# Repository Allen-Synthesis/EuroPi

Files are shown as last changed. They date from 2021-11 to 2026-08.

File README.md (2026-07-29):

  
# EuroPi
The EuroPi is a user reprogrammable [Eurorack](https://en.wikipedia.org/wiki/Eurorack) module developed by [Allen Synthesis](https://allensynthesis.co.uk) that uses the [Raspberry Pi Pico](https://www.raspberrypi.com/products/raspberry-pi-pico/) to process and produce modular level signals based on code written in [MicroPython](https://micropython.org/). The entire project is open-source.

## Documentation
### Hardware
The hardware source files and documentation (including build guides) can be found in the [hardware overview](hardware/README.md), and kits can be bought directly from [Allen Synthesis](https://allensynthesis.square.site/product/europi-panel-pcb/16?cp=true&sa=true&sbp=false&q=false).

### Software
Before using any of the software, follow the [programming_instructions](software/programming_instructions.md) to set up and calibrate your module.
A list of user contributed scripts (along with descriptions for their usage) can be found in [contrib/README.md](software/contrib/README.md).

The EuroPi firmware allows you to interact with the hardware easily using code written in MicroPython. You can read the full list of available functions in the [EuroPi API Documentation](https://allen-synthesis.github.io/EuroPi/), which also includes some examples of some of those functions can be used. Some of the less obvious but potentially useful functions are also explained in more depth in [interesting_things.md](software/interesting_things.md).

If you would like to extend any of the features of the EuroPi software, you can view the [firmware source code](software/firmware/europi.py), and make contributions of your own after reading the [contribution guidelines](contributing.md).

### Issues
If you find any bugs, either in the software, the hardware, or the documentation, please [create a GitHub issue](https://github.com/Allen-Synthesis/EuroPi/issues/new/choose) so it can be fixed by one of the maintainers. There are issue templates available, so please choose whichever is most relevant.

### AI Policy 
This is a project that is both explicitly aware of, and reliant on, its social context; the module's licenses are deliberately 'free' and open-source, and that fact is what has allowed its community to develop itself, and consequently develop the EuroPi module.
To paraphrase [Dan McQuillan](https://www.youtube.com/watch?v=mh0U2o5Ysms), "AI removes the cultural context that underpins our social relations" - A tool which produces an output without regard for social context cannot be used to meaningfully contribute to any project that specifically aims to analyse and engage with that context.

We are not able to know with certainty that any contribution is AI-free, however any pull requests which have clearly relied on it will be rejected. For the reasons described above we hope that you will choose to develop without it, not just to ensure a quick merge, but for the benefit of the open-source community and society as a whole.
All of the core components of the EuroPi (the firmware and hardware) are entirely AI-free.

## Specification
* 6 0-10V Control Voltage outputs, each with indicator LED
* 2 Knobs with 12 bit resolution
* 2 Push Buttons
* 1 0-12V Control Voltage input with 12 bit resolution
* 1 Digital input for external clocking or gate sources
* 128x32 OLED Display
* I²C expansion header on the rear for extra sensors or outputs

github banner

## License
This module, and any documentation included in this repository, is entirely "free" software and hardware. The hardware is [certified by the Open Source Hardware Association](https://certification.oshwa.org/uk000048.html)

* Software: [Apache 2.0](software/LICENSE)
* Hardware: [CERN OHL-S v2](hardware/LICENSE)
* Documentation: [CC0 1.0](LICENSE)

Anyone is welcome to design their own versions of the idea, or modify my designs.
The only thing I would ask is that you refrain from using the brand name 'Allen Synthesis' on your DIY builds if they have modified my files in any way, just to prevent any confusion if they end up being re-sold or distributed. This is in line with section 8.2 of the CERN license. You may use the brand name if you have simply copied the files from this repository to replicate without modification.

If you have a bug fix or improvement that you think is worth sharing, then feel free to send over any pictures or documentation and it can be merged with the main project!

## Disclaimer
Recreate any of the files found in this repository at your own risk; I will attempt to solve any issues that you might have with my designs, but I can't guarantee that there are not minor bugs in any of the documents, both hardware and software. If you want a module or kit that you know will work and will have customer support, you can order one directly from [Allen Synthesis](https://allensynthesis.co.uk/).

**NOTE:** This repository relates to the EuroPi module, however some users may be expecting to see what is now referred to as the 'EuroPi Prototype'. The repository for this (now deprecated) module [can be found here](https://github.com/roryjamesallen/EuroPi-Prototype)

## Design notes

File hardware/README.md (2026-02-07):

# Hardware Overview
There are multiple versions of the hardware documented in this directory, the original EuroPi (through-hole), the new EuroPi-SMD (surface-mount), and a stripboard version (stripboard). Each has a different build guide and bill of materials, so make sure you follow the one you want to build.

**[surface-mount](surface-mount/)**: The simplest to DIY as you only need to solder on the components which stick through the panel, i.e. the jacks, knobs etc. All of the other circuitry is soldered onto the PCB already.

**[through-hole](through-hole/)**: A slightly more in depth build as you need to solder on every component, however only through-hole components are used, so this isn't as hard as it sounds. This is the build most people have made and was previously the only publicly available build at all.

**[stripboard](stripboard/)**: A much rougher layout and does not use a PCB at all, but instead uses 'stripboard'. This hasn't been tested nearly as much as the other two, but people have successfully built it and shared their version on Discord. Not developed or maintained by Allen Synthesis.

# Hardware Specifications
All hardware variants share the same specifications as the components and schematics are the same.

## Outputs
- 1k Output Impedance
- RC filter smoothed PWM
- ~1.5kHz Maximum usable frequency (without changing RC values)
- 0-10V

## Analogue Input
- 100k Input Impedance
- 0-12V Readable Range
- Protected for ±12V (TL074 limits, MCP6002 will always clip to ±3.3V)

## Digital Input
- 100k Input Impedance
- 0.8V threshold to read as high

## OLED
- SSD1306 0.91"
- 128 x 32 pixels
- I2C Protocol

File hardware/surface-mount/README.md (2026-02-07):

# EuroPi (surface-mount)

This is a version of the EuroPi that has all of the components other than the Pico, power header, and panel components pre-soldered using SMD packages. This makes for a much simpler DIY build, as well as a thinner end result. It has identical technical specifications to the through-hole version and adds the hardware required for input detection.

The board files for this version are designed in [KiCad](https://www.kicad.org/) so are a more friendly starting point for third-party development or modification.

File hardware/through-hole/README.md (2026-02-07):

# EuroPi (through-hole)
This directory contains the build instructions and production files for the 'original' EuroPi, which is the entirely through-hole build. This is the build the majority of users have.

# PCB Files

The PCB files are in two file types:
- .pcb files, which can be opened in [DesignSpark](https://www.rs-online.com/designspark/pcb-software) free PCB software
- .rar files, which are zipped folders containing the Gerber format PCBs. Each entire .rar folder can be dragged and dropped to a PCB manufacturer such as [JLC PCB](https://jlcpcb.com/) (my personal choice)

There are two different options for the panel PCB:
- Panel, which is made for JLC aluminium production
- Black Panel, which is made for FR4 production by any manufacturer
The subtleties of these files are minor, but JLC will only produce the aluminium boards correctly if the layers are in the order that they are in these files, which is silkscreen on the bottom layer and copper on the top.

In line with the license used for the PCBs, if you modify these files before production (rather than just dragging and dropping the gerber files), please contact me if you would like to keep the 'Allen Synthesis' name on it! This is not based in any mistrust of your modifications, but in the risk that someone else might then get hold of these boards or files, turn to me for support, and be disappointed.

If you would rather save yourself the effort of ordering boards (and potentially paying import charges), you can also order Panel + PCB kits directly from me, which will ship with a lower lead time than a PCB manufacturer too!
https://allensynthesis.square.site/

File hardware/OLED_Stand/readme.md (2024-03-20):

# 3D printed OLED stands

A simple small stand for your OLED display. This helps hold it in place while soldering and keeps it snug against the face of the module.

> There are two versions of the stand, one for the CPC style OLED and one for the TPH (the Pi Hut) style OLED.

## CPC style OLED

3D print the file [OLED_Stand.stl](OLED_Stand.stl).

Put the stand on something about 5-10mm tall, then solder some component cutoff wire to your OLED so that they fall below the bottom of the stand. Place on your interface board, solder pins to board. Pins may need to be bent slightly for the model of OLED that you're using. Just align the stand and the display and you should be right in the middle of the cutout.

Print upside down for best results/least amount of supports. Should print very quickly on most printers. It takes 30 minutes on an Ender3 Pro.

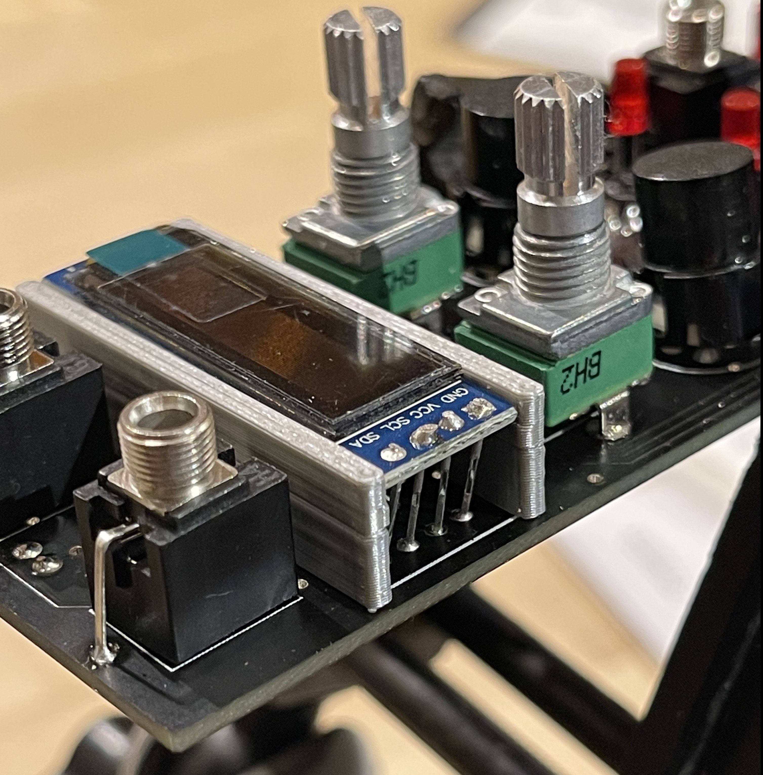
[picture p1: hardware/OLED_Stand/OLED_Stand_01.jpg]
OLED Stand
 

## TPH (the Pi Hut) style OLED

3D print the file [OLED_Stand_Pi_Hut.stl](OLED_Stand_Pi_Hut.stl).

The TPH (the Pi Hut) OLED needs a different stand because it has a chunky connector on the side (unused by the EuroPi).

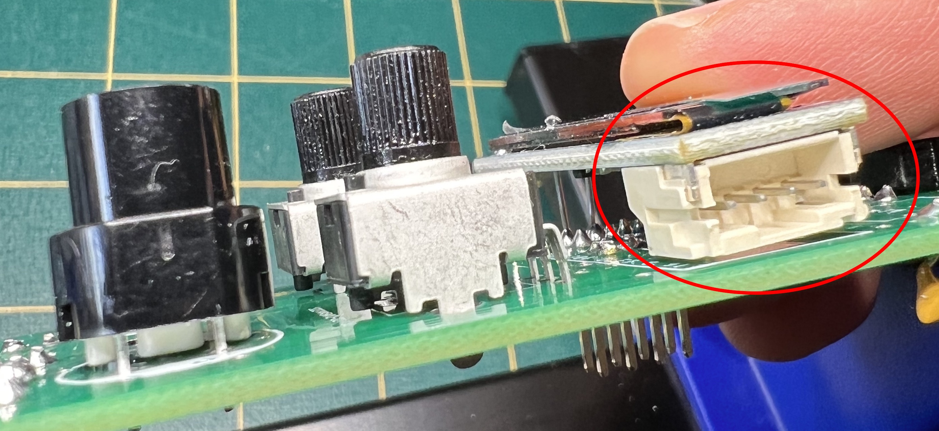
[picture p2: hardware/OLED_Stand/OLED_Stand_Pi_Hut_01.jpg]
OLED Pi Hut style
 

- Slide your OLED into the groove.
- Place the stand with OLED into position on the PCB (hold in place using bluetack).
- Solder the four vertical wires.

The stand has a notch to avoid certain soldering points. You should keep the stand permanently in your EuroPi for added stability of the screen.

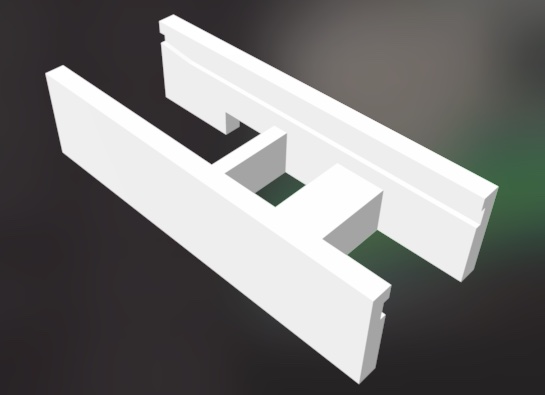
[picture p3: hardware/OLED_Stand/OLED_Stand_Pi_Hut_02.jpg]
OLED Stand for Pi Hut style


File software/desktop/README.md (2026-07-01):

# Desktop and Mobile Software

This directory contains programs and configuration files intended to run on your desktop/laptop
computer or mobile device, not on EuroPi itself.

Please refer to the README.md file in each sub-directory for details on how to set up and use
each piece of software.

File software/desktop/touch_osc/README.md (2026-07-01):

# Sample TouchOSC Configuration

This directory contains a sample TouchOSC configuration file designed to work with
[`osc_control`](/software/contrib/osc_control.md).

To use this layout, copy `europi.tosc` onto your device and open TouchOSC. Import
`europi.tosc` into TouchOSC. This will add the following controls:

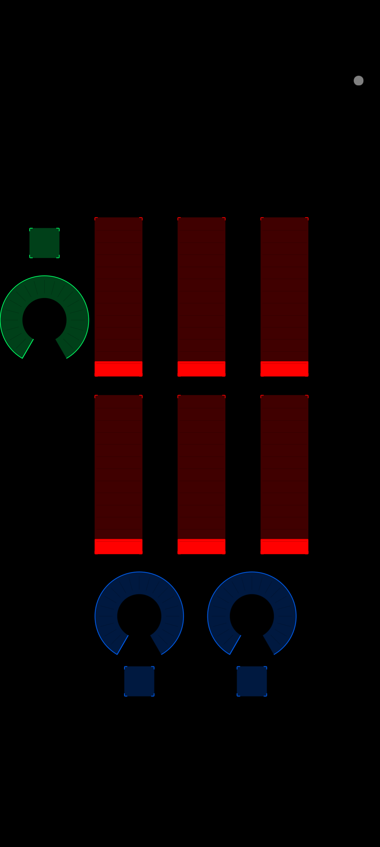
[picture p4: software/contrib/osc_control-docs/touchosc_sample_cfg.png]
OSC Layout


- 6 red sliders to control EuroPi's outputs
- green indicators for the values of `din` and `ain`
- blue indicators for the values of `k1`, `k2`, `b1`, and `b2`

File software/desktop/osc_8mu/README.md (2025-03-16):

# OSC 8mu Interface

This program is intended to be run on a laptop or desktop with a
[Music Thing Modular 8mu](https://www.musicthing.co.uk/8mu_page/)
connected to it.  It converts the MIDI outputs from 8mu into OSC
messages that can be consumed by EuroPi when properly set up.

## Requirements

### EuroPi

Your EuroPi module must be equipped with a Pico W or Pico 2 W instead
of the standard Pico.

EuroPi's WiFi [must be configured](/software/CONFIGURATION.md#wifi-connection)
with either
1. your computer connected directly to EuroPi's access point, or
2. both your computer and EuroPi connected to the same external network.

Power on EuroPi and run the [`OSC Interface`](/software/contrib/osc_control.md)
program, making note of EuroPi's IP address displayed on the OLED.

### Laptop/Desktop

You must have Python3 installed on your computer, with the following
modules:
- `mido`
- `rtmidi` (via the `python-rtmidi` PyPI package)

To install these, use `pip3` (or `pip`):
```bash
pip3 install mido
pip3 install python-rtmidi
```

Finally, you must own a Music Thing Modular 8mu and have it connected to
your computer using a USB-C cable.

## Running the program

Once EuroPi is running the `OSC Interface` program, start `osc_8mu`
on your desktop by running
```bash
cd /path/to/EuroPi/software/desktop
python3 osc_8mu.py --ip <EuroPi's IP address>
```

Depending on the configuration of 8mu you may need to specify what MIDI
controls will control each output of EuroPi.  For example, if you have
configured 8mu to use controls 20-28 for the sliders, you will need
to run `osc_8mu` with the following command:
```bash
python3 osc_8mu.py --ip 192.168.4.1 --cv1 20 --cv2 21 --cv3 22 --cv4 23 --cv5 24 --cv6 24
```

To override the UDP port, use the `-p|--port` argument. By default `osc_8mu` will use
port 9000 to send UDP packets to EuroPi.

For more information about the available parameters, run
```bash
python3 osc_8mu.py --help
```

## MIDI to OSC to EuroPi conversion

The 8mu slider position is reported as a MIDI value from `0` to `127`. This is converted
to a `0.0` to `1.0` value for OSC, which is then multiplied by `MAX_OUTPUT_VOLTAGE` on
EuroPi to set the value of the output channel. Obviously 128 positions in the MIDI source
doesn't provide super-fine resolution on EuroPi's voltage.

To work around this the `-s|--scale` parameter can be set to provide an additional
scale factor during the MIDI to OSC conversion:

```
X_midi <- Read from 8mu: 0-127

X_osc = X_midi / 127.0 * scale
V_out = X_osc * MAX_OUTPUT_VOLTAGE
```

For example, setting `scale` to 0.1 will reduce EuroPi's output range from 0-10V
to 0-1V, but will compress all 128 steps within the 1V range, allowing finer control
over a smaller voltage range.

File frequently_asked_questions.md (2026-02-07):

# FAQ

### Frequently asked questions about the EuroPi project. If you can't find the answer to your question here, head over to [The Discord](https://discord.gg/JaQwtCnBV5) and ask it in the support channel!

#

### Topics:

### [General Questions](#general-questions)
### [Hardware Decisions](#hardware-decisions)
### [Bill of Materials (BOM)](#bill-of-materials)
### [Git](#git)
### [Programming](#programming-1)
### [Calibration](#calibration-1)

#

## General Questions

| Can the EuroPi process audio? | Some audio has been achieved on the EuroPi, such as t-schreibs' [Poly Square](software/contrib/poly_square.md) script, however full audio processing would likely require extra hardware to be accurate |
|--|--|

## Hardware Decisions

| Why did you use potentiometers and not encoders? | This module is designed to be a platform with which you can design fully functioning modules of your own, rather than a deep menu based system, and I feel that using encoders would encourage user interfaces that stray into the unusable. Users can always add encoders using i²c if they're determined! |
|--|--|

## Bill of Materials

| Do any of the capacitors need to be polarised? | No, non-polarised will work fine |
|--|--|

## Git/GitHub

| What is a 'Pull Request'? | This is a request made by a user to the main repository to 'pull' the extra data, either changes, new files, or deletions, from their fork into the main one. Essentially it is the way that users contribute to the main repository. The guidelines for creating a PR, and more explanation of what one is, can be found in the [contributing guidelines](contributing.md) |
|--|--|

## Programming

| Do I need to learn programming to use this module? | Nope! The menu system can be used with absolutely no programming knowledge at all, but once installed you are always free to write your own scripts if you feel like it |
|--|--|

## Calibration

| When in the second stage of calibration, my module never reaches 10V, what do I do? | Refer to the [troubleshooting guide](troubleshooting.md) |
|--|--|

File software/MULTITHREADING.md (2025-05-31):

# Multi-Threading

The Raspberry Pi Pico used in EuroPi has 2 CPU cores.  By default only one core is used.  Micropython contains a
module called `_thread` that can be used to run code on both cores.  This can be helpful if, for example, your program
features a lot of mathematical calculations (e.g. floating point operations, trigonometry (e.g. `sin` or `cos`)) that
must be run quickly, but also features a complex GUI to render to the OLED.

## WARNING

Multi-threading is considered an experimental feature, and is intended for advanced programmers only. Adding threads to
your program can introduce many hard-to-debug errors and requires some understanding of some advanced topics not
covered here, including:
- thread safety
- concurrency
- semaphores & mutexes

Unless you're certain you need the additional processing power offered by the EuroPi CPU's second core, it is
_strongly_ recommended that you write your program using a single thread.

## Using `_thread`

To use the `_thread` library you must first import it into your program:
```python
import _thread
```

Your program will always contain at least one thread, referred to as the "main thread."  To start a second thread
you must define a function to execute and start it with `_thread.start_new_thread`.

### Example 1: Basic thread execution

This example shows the absolute minimum needed to run two threads:

```python
from europi import *
import time
import _thread

def my_second_thread():
    """The secondary thread; toggles CV2 on and off at 0.5Hz"""
    while True:
        cv2.on()
        time.sleep(1)
        cv2.off()
        time.sleep(1)

def main():
    """The main thread; creates the secondary thread and then toggles CV1 at 1Hz"""
    # Start the second thread
    second_thread = _thread.start_new_thread(my_second_thread, ())

    while True:
        cv1.on()
        time.sleep(0.5)
        cv1.off()
        time.sleep(0.5)
```

This example has a few limitations that we'll address below:
1. It's not a `EuroPiScript`, so it can't be included in the main menu
2. The secondary thread can keep running after we cancel execution, which can result in problems
   using the Python terminal in Thonny for debugging.

### Example 2: Basic `EuroPiScript` implementation

This is a more complex example that implements the same logic as above, but wrapped in a `EuroPiScript`.
Note that we add a second condition to the `while` loops; the `self.is_running` flag will allow the
background thread to exit cleanly when debugging in Thonny.
```python
from europi import *
from europi_script import EuroPiScript
import time
import _thread

class BasicThreadingDemo1(EuroPiScript):
    def __init__(self):
        super().__init__()

        # is main() running?
        # this is used to make sure the threads exit when we cancel
        # the program
        self.is_running = False

    def main_thread(self):
        """The main thread; toggles CV1 on and off at 1Hz"""
        while self.is_running:
            cv1.on()
            time.sleep(0.5)
            cv1.off()
            time.sleep(0.5)

    def secondary_thread(self):
        """The secondary thread; toggles CV2 on and off at 0.5Hz
        """
        while self.is_running:
            cv2.on()
            time.sleep(1)
            cv2.off()
            time.sleep(1)

    def main(self):
        # Clear the display
        oled.fill(0)
        oled.show()

        # set is_running to True BEFORE we start the threads!
        # otherwise they'll exit right away
        self.is_running = True
        try:
            second_thread = _thread.start_new_thread(self.secondary_thread, ())
            self.main_thread()
        except KeyboardInterrupt:
            # When Thonny's terminal connects, or when we press ctrl+C we'll
            # catch a KeyboardInterrupt exception, which we can use to stop
            # both threads.
            self.is_running = False
        finally:
            print("User aborted. Exiting.")

if __name__ == "__main__":
    BasicThreadingDemo1().main()
```

### Example 3: Handling digital inputs

Interrupt Service Routines (ISRs), implemented as `handler` functions for button presses and `din` rising/falling edges
have been known to cause threaded programs to hang.  It is therefore recommended to _avoid_ using `handler` functions
in your program:
```python
# To NOT do this:
@b1.handler
def on_b1_rising():
    self.do_stuff()
```

Instead, [`experimental.thread`](/software/firmware/experimental/thread.py) provides a `DigitalInputHelper` class
that can be used inside your main thread to check the state of the buttons & `din` and invoke callback functions
when a rising or falling edge is detected.

For example:
```python
from europi import *
from europi_script import EuroPiScript

import time
import _thread

from experimental.thread import DigitalInputHelper

class BasicThreadingDemo2(EuroPiScript):
    def __init__(self):
        super().__init__()
        self.is_running = False

        self.digital_input_helper = DigitalInputHelper(
            on_b1_rising = self.on_b1_press,
            on_b1_falling = self.on_b1_release,
            on_b2_rising = self.on_b2_press,
            on_b2_falling = self.on_b2_release,
            on_din_rising = self.on_din_high,
            on_din_falling = self.on_din_low
        )

    def on_b1_press(self):
        """Turn on CV4 when the button is held
        """
        cv4.on()

    def on_b1_release(self):
        """Turn off CV4 when the button is released
        """
        cv4.off()

    def on_b2_press(self):
        """Turn on CV5 when the button is held
        """
        cv5.on()

    def on_b2_release(self):
        """Turn off CV5 when the button is released
        """
        cv5.off()

    def on_din_high(self):
        """Turn on CV6 when the signal goes high
        """
        cv6.on()

    def on_din_low(self):
        """Turn off CV6 when the signal drops low
        """
        cv6.off()

    def main_thread(self):
        """The main thread; toggles CV1 on and off at 1Hz and handles the buttons + DIN
        """
        # calling time.sleep will block the input handling, so we need to check the clock instead
        last_state_change_time = time.ticks_ms()
        cv1_on = True
        cv1.on()

        while self.is_running:
            # Check the inputs
            self.digital_input_helper.update()

            now = time.ticks_ms()
            if time.ticks_diff(now, last_state_change_time) >= 500:
                last_state_change_time = now
                cv1_on = not cv1_on
                if cv1_on:
                    cv1.on()
                else:
                    cv1.off()

    def secondary_thread(self):
        """The secondary thread; toggles CV2 on and off at 0.5Hz
        """
        while self.is_running:
            cv2.on()
            time.sleep(1)
            cv2.off()
            time.sleep(1)

    def main(self):
        # Clear the display
        oled.fill(0)
        oled.show()

        self.is_running = True
        try:
            second_thread = _thread.start_new_thread(self.secondary_thread, ())
            self.main_thread()
        except KeyboardInterrupt:
            self.is_running = False
        finally:
            print("User aborted. Exiting.")

if __name__ == "__main__":
    BasicThreadingDemo2().main()
```

### Example 4: OLED rendering on the second core

One of the slowest operations in the EuroPi firmware is updated the OLED. If possible moving any GUI rendering into
a secondary thread is a good idea to optimize your program.  Note that you will likely need to use `Lock` objects
to prevent threads from trying to read/write data at the same time.

```python
from europi import *
from europi_script import EuroPiScript

import math
import _thread

class BasicThreadingDemo3(EuroPiScript):
    def __init__(self):
        super().__init__()

        # Create a lock object to prevent multiple threads from accessing our pixel array
        self.pixel_lock = _thread.allocate_lock()

        # Create an array that we'll store vertical pixel positions in to draw on screen
        self.pixel_heights = []

    def cv_thread(self):
        """The main thread; generates a sine wave on CV1
        """
        CYCLE_TICKS = 10000  # one complete sine wave every N times through the loop

        ticks = 0
        cv1_volts = 0
        while True:
            # convert the tick counter to radians for use with sin/cos
            theta = ticks / CYCLE_TICKS * (2*math.pi)

            # sin gives us [-1, 1], but we need to shift it to [0, MAX_OUTPUT_VOLTAGE]
            cv1_volts = (math.sin(theta) + 1) / 2 * MAX_OUTPUT_VOLTAGE

            # convert the voltage to an integer from 0 to OLED_HEIGHT
            # note that row 0 is the top, so we'll draw a line that goes down as the voltage goes up
            # since this is just an example, that's fine; the math to flip the visualization is left as
            # an exercise for the reader
            with self.pixel_lock:
                self.pixel_heights.append(int(cv1_volts * OLED_HEIGHT / MAX_OUTPUT_VOLTAGE))

                # Restrict the number of pixel heights to match the width of the screen
                if len(self.pixel_heights) >= OLED_WIDTH:
                    self.pixel_heights.pop(0)

            ticks = ticks + 1
            if ticks >= CYCLE_TICKS:
                ticks = 0

            cv1.voltage(cv1_volts)

    def gui_thread(self):
        """Draw the wave shapes to the screen
        """
        usb_connected_at_start = europi.usb_connected.value()
        while eurpi.usb_connected.value() == usb_connected_at_start and self.is_running:
            # clear the screen
            oled.fill(0)

            # Draw the pixels representing our waves
            # Make sure to grab the lock so the arrays aren't modified while we're reading them!
            with self.pixel_lock:
                for i in range(len(self.pixel_heights)):
                    oled.pixel(i, self.pixel_heights[i], 0xff)  # draw a white pixel

            # Show the updated display
            oled.show()

    def main(self):
        self.is_running = True
        try:
            second_thread = _thread.start_new_thread(self.gui_thread, ())
            self.cv_thread()
        except KeyboardInterrupt:
            self.is_running = False
        finally:
            print("User aborted. Exiting.")

if __name__ == "__main__":
    BasicThreadingDemo3().main()
```

## How many threads can I use?

Because each thread runs on a different core, and the EuroPi's processor only has 2 cores, it is recommended to limit
your program to 2 thread: the main thread, and a single additional thread started with `_thread.start_new_thread`.

## Cancelling Execution and the Second Core

Typically if you catch `KeyboardInterrupt` exceptions as described in the examples above you should
be able to prevent the second core from becomming locked, but if your program has other errors that
are not handled it's possible that the main thread will exit while the second thread keeps running.

If this occurs, the easiest way to reset the secondary core is to simply power-cycle your module.

## References

- [Official Python `_thread` docs](https://docs.python.org/3/library/_thread.html)

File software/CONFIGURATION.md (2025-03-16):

# Configuration Customization

Certain properties of the module, such as screen rotation, CPU clock speed, and Raspberry Pi Pico model, can be
set using a static configuration file.  This file is located at `/config/EuroPiConfig.json` on the
Raspberry Pi Pico. If this file does not exist, default settings will be loaded.  The following shows the
default configuration:
```json
{
    "EUROPI_MODEL": "europi",
    "PICO_MODEL": "pico",
    "CPU_FREQ": "overclocked",
    "ROTATE_DISPLAY": false,
    "DISPLAY_WIDTH": 128,
    "DISPLAY_HEIGHT": 32,
    "DISPLAY_SDA": 0,
    "DISPLAY_SCL": 1,
    "DISPLAY_CHANNEL": 0,
    "EXTERNAL_I2C_SDA": 2,
    "EXTERNAL_I2C_SCL": 3,
    "EXTERNAL_I2C_CHANNEL": 1,
    "EXTERNAL_I2C_FREQUENCY": 100000,
    "EXTERNAL_I2C_TIMEOUT": 1000,
    "MAX_OUTPUT_VOLTAGE": 10.0,
    "MAX_INPUT_VOLTAGE": 10.0,
    "GATE_VOLTAGE": 5.0,
    "MENU_AFTER_POWER_ON": false
}
```

## System

Options:
- `EUROPI_MODEL` specifies the type of EuroPi module. Currently only `"europi"` is supported. Default: `"europi"`
- `PICO_MODEL` must be one of
  - `"pico"`,
  - `"pico h"`,
  - `"pico w"`,
  - `"pico 2"`, or
  - `"pico 2w"`.
  Default: `"pico"`.
- `CPU_FREQ` specifies whether or not the CPU should be overclocked. Must be one of `"overclocked"` or `"normal"`.
  Default: `"overclocked"`
- `MENU_AFTER_POWER_ON` is a boolean indicating whether or not the module should always return to the main menu when
  it powers on.  By default the EuroPi will re-launch the last-used program instead of returning to the main menu. Default: `false`

## Display

Options:
- `ROTATE_DISPLAY` must be one of `false` or `true`. Default: `false`
- `DISPLAY_WIDTH` is the width of the screen in pixels. The standard EuroPi screen is 128 pixels wide. Default: `128`
- `DISPLAY_HEIGHT` is the height of the screen in pixels. The standard EuroPi screen is 32 pixels tall. Default: `32`
- `DISPLAY_SDA` is the I²C SDA pin used for the display. Only SDA capable pins can be selected. Default: `0`
- `DISPLAY_SCL` is the I²C SCL pin used for the display. Only SCL capable pins can be selected. Default: `1`
- `DISPLAY_CHANNEL` is the I²C channel used for the display, either 0 or 1. Default: `0`
- `DISPLAY_CONTRAST` is a value indicating the display contrast. Higher numbers give higher contrast. `0` to `255`. Default: `255`

## External I²C

Options:
- `EXTERNAL_I2C_SDA` is the I²C SDA pin used for the external I²C interface. Only SDA capable pis can be selected. Default: `2`
- `EXTERNAL_I2C_SCL` is the I²C SCL pin used for the external I²C interface. Only SCL capable pins can be selected. Default: `3`
- `EXTERNAL_I2C_CHANNEL` is the I²C channel used for the external I²C interface, either 0 or 1. Default: `1`
- `EXTERNAL_I2C_FREQUENCY` is the I²C frequency used for the external I²C interface. Default: `100000`
- `EXTERNAL_I2C_TIMEOUT` is the I²C timeout in milliseconds for the external I²C interface. Default: `1000`

## I/O voltage

Options:
- `MAX_OUTPUT_VOLTAGE` is a float in the range `[0.0, 10.0]` indicating the maximum voltage CV output can generate. Default: `10.0`
  The hardware is capable of 10V maximum
- `MAX_INPUT_VOLTAGE` is a float in the range `[0.0, 12.0]` indicating the maximum allowed voltage into the `ain` jack.
  The hardware is capable of 12V maximum. Default: `10.0`
- `GATE_VOLTAGE` is a float in the range `[0.0, 10.0]` indicating the voltage that an output will produce when `cvx.on()`
  is called. This value must not be higher than `MAX_OUTPUT_VOLTAGE`. Default: `5.0`

I/O voltage options should specify no more than 1 decimal point. i.e. `2.5` is acceptable, but `1.234` is not.  These
limits are intended for broad compatibility configuration, not for precise tuning.

If you assembled your module with the Raspberry Pi Pico 2 (or a clone featuring the RP2350 microcontroller) make sure to
set the `PICO_MODEL` setting to `"pico2"`.

# Experimental configuration

Other configuration properties are used by [experimental features](/software/firmware/experimental/__init__.py)
and can be set using a similar static configuration file. This file is located at `/config/ExperimentalConfig.json`
on the Raspberry Pi Pico. If this file does not exist, default settings will be loaded.

## Quantization

Options:
- `VOLTS_PER_OCTAVE` must be one of `1.0` (Eurorack standard) or `1.2` (Buchla standard). Default: `1.0`

## Realtime Clock (RTC)

Options:
- `RTC_IMPLEMENTATION` is one of the following, representing the realtime clock enabled on your module:
  - `""`: there is no RTC present. (default)
  - `"ds3231"`: use a DS3231 module connected to the external I2C interface
  - `"ds1307"`: use a DS1307 module connected to the external I2C interface (THIS IS UNTESTED! USE AT YOUR OWN RISK)
  - `"ntp"`: use an NTP source as the external clock. Requires wifi-supported Pico (e.g. Rasperry Pi Pico W or Pico 2 W)
    and valid network configuration (see [WiFi connection](#wifi-connection), below)

## Timezone

Options:
- `UTC_OFFSET_HOURS`: The number of hours ahead/behind UTC the local timezone is (-24 to +24)
- `UTC_OFFSET_MINUTES`: The number of minutes ahead/behind UTC the local timezone is (-59 to +59)

## WiFi Connection

Options:
- `WIFI_MODE`: the wireless operation mode, one of:
  - `"access_point"` (default): EuroPi acts as a wireless access point for other devices to connect to
  -`"client"`: connect EuroPi to an external wireless router or accesspoint (DHCP required)
- `WIFI_SSID`: the SSID of the wireless network to connect to (in `client` mode) or to broadcast
  (in `access_point` mode). Default: `"EuroPi"`
- `WIFI_BSSID`: the optional BSSID of the network to connect to (e.g. access point MAC address). Default: `""`
- `WIFI_PASSWORD`: the password of the wireless network. Default: `"europi"`
- `WIFI_CHANNEL`: the WiFi channel 1-13 to use in `access_point` mode; ignored in `client` mode. Default: `10`
- `WIFI_DHCP`: ignored if `WIFI_MODE` is `access_point`. Otherwise this controls whether or not
  EuroPi requests a DHCP lease from the external access point. Default: `true`.
- `WIFI_IP`: a static IP address to use in `client` mode if DHCP is disabled. Default: `192.168.4.1`
- `WIFI_GATEWAY`: the static gateway in `client` mode when DHCP is disabled. Default: `0.0.0.0`
- `WIFI_NETMASK`: the netmask to use in `client` mode, if DHCP is disabled. Default: `255.255.255.0`
- `WIFI_DNS`: the IP address of the DNS server to use when DHCP is disabled. Default: `8.8.8.8`

WiFi options are only applicable if EuroPi has the Raspberry Pi Pico W or Raspberry Pi Pico 2 W board;
other Pico models do not contain wireless support.

**NOTE**: At the time of writing, the latest Micropython firmware for the Raspberry Pi Pico 2 W has a bug in
which the wireless card will not reliably work if the CPU is overclocked. If you have problems using wifi please
try changing `CPU_FREQ` to `normal` in `EuroPiConfig.json`.

### WiFi Security

If `WIFI_PASSWORD` is empty EuroPi will assume the network is _unencrypted_. This applies to both `client` and
`access_point` modes. If `WIFI_PASSWORD` contains any text, WPA/WPA2 will be used (WPA2 is preferred, but
in `client` mode WPA will be used if the router requires it).

Other wireless authentication models, including the use of cerfificates, VPN connections, etc... are not supported
at this time on the Raspberry Pi Pico (2) W.

## WebREPL Configuration

`WebREPL` allows accessing the Python shell over WiFi, as well as enabling sending/receiving files wirelessly.
This can be useful if you lack a USB cable long enought to reach from your computer to your EuroPi.

Enabling `WebREPL` requires a Raspberry Pi Pico W or Pico 2 W, as well as a valid wifi configuration (see above).

When enabled, `WebREPL` will use the password `EuroPi` by default. To change this password you will need to modify
`/webrepl_cfg.py` to enter your new password.

To access `WebREPL`, direct your computer's browser to `http://<EuroPi's IP address>:8622`, e.g.
`http://192.168.4.1:8622`. Alternatively you can configure Thonny's terminal to connect via `WebREPL`
by selecting Run > Configure Interpreter, selecting `WebREPL` from the drop-down, and entering
EuroPi's IP address and port 8622.

Options:
- `ENABLE_WEBREPL`: enable or disable `WebREPL`. Default: `false`

### `WebREPL` Security

Enabling `WebREPL` can be a security risk: it potentially allows anyone to access the Python interpreter of
your EuroPi, giving them complete access to run code, modify files, etc.... If you choose to enable `WebREPL`
it is highly recommended that you choose a strong password and that you make sure your wifi connection is
using WPA2 (see [WiFi Security](#wifi-security), above).

# Accessing config members in Python code

The firmware converts the JSON file into a `ConfigSettings` object, where the JSON keys are converted
to Python attributes.  The JSON object's keys must follow these rules, otherwise a `ValueError` will be raised:

1. The string may not be empty
1. The string may only contain letters, numbers, and the underscore (`_`) character
1. The string may not begin with a number
1. The string should be in `ALL_CAPS`

The JSON key is converted into a Python attribute of the configuration object. For example, this JSON file
```json
{
  "CLOCK_MULTIPLIER": 4,
  "HARD_SYNC": true,
  "WAVE_SHAPE": "sine"
}
```
would produce a Python object with these attributes:
```python
>>> dir(config_object)
[
  '__class__',
  '__init__',
  '__module__',
  '__qualname__',
  '__dict__',
  'to_attr_name',
  'CLOCK_MULTIPLIER',
  'HARD_SYNC',
  'WAVE_SHAPE'
]

>>> config_object.CLOCK_MULTIPLIER
4

>>> config_object.HARD_SYNC
True

>>> config_object.WAVE_SHAPE
'sine'
```

`europi.py` contains objects called `europi_config` and `experimental_config` which implement the core & experimental
customizations described in the sections above.

When you import `europi` into your project you can access the `europi_config` object like this:
```python
from europi import *

# A voltage range we can select from in a user menu
VOLTAGE_RANGE = range(0, europi_config.MAX_OUTPUT_VOLTAGE)
```

Alternatively, you can access it using the fully qualified namespace:
```python
import europi

# A voltage range we can select from in a user menu
VOLTAGE_RANGE = range(0, europi.europi_config.MAX_OUTPUT_VOLTAGE)
```

# Note on Booleans

Python uses `True` and `False` to represent boolean values (starting with upper-case letters), but JSON uses `true` and
`false` (starting with lower-case letters).

This is an unavoidable inconsistency between the configuration file and the Python source code. When modifying the JSON
file to modify your configuration, make sure to use correct JSON boolean names, not Python names.

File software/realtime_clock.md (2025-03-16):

# Realtime Clock

EuroPi does not natively include a realtime clock. An external clock module can be
installed and configured to provide time and date information to EuroPi's programs.

## What is a realtime clock?

A realtime clock is a clock with a battery that will continue to track the time
even when your synthesizer is powered-off. This allows EuroPi to know what the
current date and time are, even if the module has been turned off for some time.

Without a realtime clock, the only way to get the time is by using Micropython's
`time.ticks_ms()` or `time.ticks_us()` functions; these return the ticks (in
milliseconds or microseconds) since the module was powered-on, but won't accurately
represent the real-world time and date.

## What clock should I buy?

There are many I2C compatible realtime clock modules available. EuroPi has been
tested with the DS3231, though the similar DS1307 may also work.

These modules can be bought online from a variety of sources, for example:
- https://www.amazon.ca/dp/B09S8VF9GL
- https://shop.kincony.com/products/ds3231-rtc-module
- https://www.mouser.ca/ProductDetail/Analog-Devices-Maxim-Integrated/DS3231MPMB1
- https://www.aliexpress.com/item/1005001875764383.html

## How do I connect the clock?

The realtime clock should be connected to EuroPi's I2C header pins, located on the
rear of the module, between the Raspberry Pi Pico and the power header.



_EuroPi's I2C header (circled)_

Depending on the size and depth of your synthesizer's case there are a few ways you
can mount the clock. For deep cases, the easiest solution is to simply use a standoff
to connect the clock to the Raspberry Pi Pico:

 

_The DS3231 RTC mounted to the Raspberry Pi Pico using a standoff_

For shallower cases, you can attach header pins and jumper wires to a pice of perfboard
or plastic, and mount the clock vertically.

 

_A vertical mount made from a piece of perboard, 2 female headers, and some wire_

Other mounting solutions are also possible, for example attaching the clock behind a
blank panel or using double-sided foam tape to attach it directly to the inside of your
case. As long as the clock is securely fastened so it won't move around, insulated from
any accidental contact with conductive surfaces inside the case, and properly
connected to the I2C header pins it should be fine.

## How do I configure the clock?

The default external I2C settings from `europi_config` should be used, unless you have
a specific need to change them in `config/EuroPiConfig.json` (for example, your RTC module
needs a specific I2C frequency):
```json
{
    "EXTERNAL_I2C_SDA": 2,
    "EXTERNAL_I2C_SCL": 3,
    "EXTERNAL_I2C_CHANNEL": 1,
    "EXTERNAL_I2C_FREQUENCY": 100000,
    "EXTERNAL_I2C_TIMEOUT": 50000,
}
```

You will also need to edit `config/ExperimentalConfig.json` to specify what RTC module you
are using:
```json
{
    "RTC_IMPLEMENTATION": "ds3231"
}
```

See [Configuration](/software/CONFIGURATION.md) for more details on EuroPiConfig.json and
ExperimentalConfig.json.

## How do I set the time?

When you first connect your clock, it will probably not indicate the correct time. To set
the realtime clock's internal memory to the current time, connect and configure the clock
as described above, and then connect EuroPi to Thonny's Python terminal.

Inside the terminal, run the following commands:
```python
from experimental.rtc import clock, Month, Weekday
clock.source.set_datetime((2025, Month.JUNE, 14, 22, 59, 0, Weekday.THURSDAY))
```

The example above sets the date to Thursday, 25 June, 2025 at 22:59:00. Modify the
year, month, day, hour, minute, second, and weekday to the current UTC date and time
when you run the command.

Once you've done this, restart your EuroPi and run the following command to make sure
the clock is properly configured:
```python
from experimenta.rtc import clock
print(clock.utcnow())
```
You should see the current date and time printed.

## What about local time?

You can further configure EuroPi to add a timezone offset. To do this, edit `/config/ExperimentalConfig.json`
to add the following:
```json
{
    "UTC_OFFSET_HOURS": -3,
    "UTC_OFFSET_MINUTES": -30,
}
```
This will set the local timezone to UTC -03:30, or Newfoundland time. If you don't liven in
Newfoundland (it's okay, I don't either), adjust the hours and minutes to your local timezone. Note that
EuroPi will _not_ track daylight savings time, so if your region changes the clocks every spring and
autumn, you will need to manually adjust EuroPi twice per year to keep the local time synchronized.

The sign of the minutes and hours must match.

## NTP Clock

If you have a Raspberry Pi Pico W or Pico 2 W, you can use the Network Time Protocol (NTP) to provide the external
clock signal to your module. To do this you must:

1. Use Thonny to install the following _additional_ packages on your module:
   - `micropython-socket`
   - `ntptime`
1. [Connect to a wireless network](/software/CONFIGURATION.md#experimental-configuration) by entering your network's
   SSID and password into the experimental configuration file
1. Set the `RTC_IMPLEMENTATION` to `ntp`
1. (optional) Enter a valid, accessible NTP server. By default `0.pool.ntp.org` will be used, but you may wish to use
   a different NTP server closer to your location.

Once configured, restart the module.  Your EuroPi should connect to the wifi network and get clock data from the
specified NTP server.

## Troubleshooting

If you see a warning of the form
```
WARNING: Oscillator stop flag set. Time may not be accurate.
```
when you print the time, this means the clock is not actually running and won't track the time
when the module is powered-off. Setting the time and date using the `set_datetime` method
described above should start the clock automatically, but if it does not you should refer
to your RTC module's datasheet to check how to clear the oscillator stop bit.

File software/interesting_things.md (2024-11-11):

## Overclocking
This code will read the analogue input and replicate the voltage read at CV output 1.
The second line will overclock the Pico to 250Mhz (the default clock speed is 125MHz).
This is as high as I have managed to safely overclock the Pico without causing unexpected crashes.
The '1' sent as a parameter to the read_voltage method, overrides the default 256 samples (usually averaged for higher accuracy), and only samples the analogue input once, making it much faster (but less accurate).

```python

from europi import *
import machine

machine.freq(250_000_000)

while True:
    input_voltage = ain.read_voltage(1)
    cv1.voltage(input_voltage)

```

This code proves the speed of the Pico to the extent that if you send audio to the analogue input, you can hear a very bitcrushed but recognisable version of it at CV output 1.

## Connecting I2C devices
EuroPi has 1 I2C channel available for connecting external devices. The header pins for this connection are located
between the Pico and the module's power connector.

To use an external I2C device, you will need to connect it to the ground, 3.3V supply, SDA, and SCL pins of the I2C
header. You must also specify the frequency of the I2C channel by creating or modifying `config/EuroPiConfig.json`
on the module:
```json
{
    "EXTERNAL_I2C_FREQUENCY": 400000
}
```
Specify the desired frequency with the `EXTERNAL_I2C_FREQUENCY` key in the JSON object. The default frequency is
`100000` (100k). Rates of up to 1M can be specified, but nothing faster than 400k has been officially tested.
(The OLED display connected to the other I2C channel uses a frequency of 400k).

By default the I2C channel uses a timeout of 50000 microseconds. To change this, set the `EXTERNAL_I2C_TIMEOUT`
parameter in `config/EuroPiConfig.json`:
```json
{
    "EXTERNAL_I2C_TIMEOUT": 100000
}
```
The timeout value specificed is in microseconds.

To use the external I2C connection in your programs, use
```python
from europi import external_i2c

external_i2c.writeto(...)
external_i2c.readfrom(...)
# etc...
```

The `external_i2c` object is an instance of `machine.I2C`, so refer to [the official documentation](https://docs.micropython.org/en/latest/library/machine.I2C.html)
for more information on using I2C.

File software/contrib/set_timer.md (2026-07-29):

# Set Timer

Set Timer is a simple manual or CV controlled clock/stopwatch to help track how long you've been
playing or recording.

## Inputs & Outputs

- `din`: Start/stop input. See configuration, below.
- `ain`: Split trigger.
- `b1`: Start/stop button.
- `b2`: Split/reset button. Will reset when stopped, or start a new split timer when running.
- `k1-2`: Unused.
- `cv1`: High when the timer is running, low when stopped.
- `cv2`: Outputs a 10ms trigger every time a new split timer starts.
- `cv3-6`: Unused.

## Configuration

The operating mode of the CV input to the timer can be set by creating/editing
`config/SetTimer.json`:
```json
{
    "MODE": "gate"
}
```
The `MODE` field can be set to either `gate` (default) or `trigger`:
- `gate`: The timer starts on the rising edge of the input signal and stops on the falling edge.
- `trigger`: The timer responds to the rising edge of the input signal and will toggle between
  starting or stopping.

## Patching Suggestions

Connect our master clock's on/off output to `din` to start/stop the clock automatically. Connect
the trigger output on `cv2` to a sequencer or switch to coordinate changes at the same time you
start a new split.

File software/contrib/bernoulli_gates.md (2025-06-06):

# Bernoulli Gates

This script is based on Mutable Instruments Branches. Because EuroPi only haa a pair of digital/analogue
inputs, the dual Bernoulli gates share the same clock (from the digital input), and only one Bernoulli
gate has CV input.

A Bernoulli gate takes a logic signal (trigger or gate) as an input, and routes it to either of its
two outputs according to a random coin toss.

## Inputs & Outputs

Inputs:
- `din`: trigger/clock
- `ain`: probability control of gate 1 (summed with Knob 1)
- `k1`: probability control of gate 1
- `k2`: probability control of gate 2
- `b1`: mode switch of gate 1
- `b2`: mode switch of gate 2

Outputs:
- `cv1`: output A of gate 1
- `cv2`: output B of gate 1
- `cv3`: copy of input trigger/clock
- `cv4`: output A of gate 2
- `cv5`: output B of gate 2
- `cv6`: logical AND of both output A (`cv1` and `cv4`)

Turning a knob anticlockwise increases the probability that a signal will be routed to the
corresponding gate's A-output, while turning it clockwise increases the probablility of the signal
being routed to the gate's B-output. At 12-o'clock the probability of either is 50/50. Fully
anticlockwise the probability of either is 100/0 and fully clockwise is 0/100.

Gate modes can be switched between
- trigger: `Tr`
- toggle: `Tg`
- gate (latch): `G`
by pressing the buttons. These modes are described in more detail below.

## Tigger mode (Tr)

When the **trigger mode** is enabled, an output A/B changes to +5V for 10ms every time they are
activated by the corresponding Bernoulli gate.

## Toggle mode (Tg)

In **toggle mode**, the module associates the “heads” and “tails” outcomes to a different pair of
decisions: “continue sending the trigger to the same output as before” and “send the trigger to the
opposite output”. As a result, when the probability knob 1 is set to its maximum value, the trigger
will alternate between outputs A and B.

## Gate mode/Latch mode (G)

When the **gate mode** is enabled, an output A/B stays at +5V until the other output gets activated.

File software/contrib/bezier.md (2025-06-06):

# Bezier Curves

This script generates two random CV outputs using [Bezier curves](https://en.wikipedia.org/wiki/Bezier_curve).

This work is inspired by the [ADDAC507](https://www.addacsystem.com/en/products/modules/addac500-series/addac507),
a collaboration between ADDAC System and [Monotrail](https://youtu.be/9PxVmeMrOoQ?si=GsNDKNipjHtBIPT1)

## Inputs & Outputs

The module has two separate output channels, referred to as A and B. Each has identical controls,
though channel B's controls can only be accessed by holding `b2`.  Note that when changing channels,
the knobs will "lock" in their previous positions, so you may need to sweep the knob to unlock it.

- `b1` -- press to change the clipping mode for both channels (see below)
- `b2` -- hold to change `k1` and `k2` to channel B input

- `k1` -- set the frequency of channel A or B
- `k2` -- set the curve of channel A or B
- `ain` -- configurable CV input to control either the frequency or curve (see below for how to set
  routing)
- `din` -- on a rising edge, force channels A and B to choose new goal voltages. This will not
  generate an output gate on `cv4` (see below), but may change the gate state on `cv5` and `cv6`.

- `cv1` -- CV output from channel A
- `cv2` -- CV output from channel B
- `cv3` -- the average of channel A and B CV outputs
- `cv4` -- gate output of channel A
- `cv5` -- gate output of channel B
- `cv6` -- logic combination of gate outputs of channels A and B (see below for how to configure the
  logic mode)

Gate outputs are different for channels A and B:
- Channel A (`cv4`) outputs a 10ms trigger every time a new sample is generated (determined by the
  frequency)
- Channel B (`cv5`) is high whenever its voltage output is higher than 50%. e.g. if the range is set
  to 0-10V, `cv5` will be high if `cv2` is 5V or more.

Patching a clock/gate/trigger signal into `din` will force the output channels to choose a new goal
voltage. This can (and frequently will) cause an abrupt change in the CV output of channels A and B,
rather than the smoothly changing
voltages they normally output.

## Additional Configuration

The script has additional parameters that can be set by manually editing/creating
`/config/Bezier.json`. The default values for this file are below:

```json
{
    "MIN_VOLTAGE": 0.0,
    "MAX_VOLTAGE": 10.0,
    "AIN_MODE": "frequency",
    "LOGIC_MODE": "xor",
    "MAX_INPUT_VOLTAGE": 10.0
}
```

The following fields may be set:

- `MIN_VOLTAGE` -- the minimum voltage that channel A or channel B may output. Default: 0.0
- `MAX_VOLTAGE` -- the maximum voltage that channel A or channel B may output. Default 10.0
- `AIN_MODE` -- changes what parameter voltage to `ain` controls. Must be one of `curve` or
  `frequency`. Default: `frequency`
- `LOGIC_MODE` -- sets the logical operation used to determine the gate output of `cv6`. Must be one
  of `and`, `or`, `xor`, `nand`, `nor`, or `xnor`. Default: `xor`.
- `MIN_FREQUENCY` -- the minumum frequency (Hz) for choosing new random values. Must be between
  0.001 and 10.0. Default: 0.01
- `MAX_FREQUENCY` -- the maximum frequency (Hz) for choosing new random values. Must be between
  0.001 and 10.0. Default: 1.0
- `MAX_INPUT_VOLTAGE` -- the maximum CV input voltage (default: 10.0)

Note that the maximum and minimum voltages must be defined such that:
- `MIN_VOLTAGE` is less than `MAX_VOLTAGE`
- `MIN_VOLTAGE` and `MAX_VOLTAGE` are positive
- `MIN_VOLTAGE` and `MAX_VOLTAGE` do not fall outside the range defined by the module's master
  configuration
- `MAX_INPUT_VOLTAGE` is less than the module's master configuration.

See [Configuration](/software/CONFIGURATION.md) for more information on input & output voltage
options for the entire module.

If you plan on using CV to control Bezier, make sure you set the maximum input voltage according to
your modules' output.  For example if you plan on connecting it to an LFO that outputs 0-5V, you may
find it helpful to set the `MAX_INPUT_VOLTAGE` to `5.0` to allow the full modulation range.  If your
LFO is bipolar (e.g. `+/-5V`), the input will be clamped at 0 as EuroPi does not support bipolar CV
input.  In this case, the use of a voltage rectifier is recommended.

## Clipping mode

The output can behave in one of 3 ways if the output wave moves outside the defined maximum/minimum
voltage range:
- `limit` -- the output is clipped to the maximum/minimum value
- `fold` -- the output is flipped such that the shape of the curve is reflected
- `thru` -- the output wraps around through the opposite end of the range

## Curve Shapes

The shape of the bezier curves is defined by the "curve constant" `k`. This value lies in the range
`[-1, 1]`, and is
interpreted as follows:
- `0.0` -- linear interpolation between voltages
- `k < 0` -- horizontal approach to each new voltage
- `k > 0` -- vertical approach to each new voltage

The following image illustrates this concept, copied from the ADDAC507 manual:
Bezier Curves

Negative values of `k` will generally result in a smoother overall shape to the output voltage.
Positive values will have more abrupt changes in voltage whenever a new goal value is generated.

## CV Control

If CV control is set to `frequency` (the default), `ain` will accept positive voltage, increasing
the frequency of both channels as voltage increases.

If CV control is set to `curve`, `ain` will accept positive voltage, changing the curve constant of
both channels. The channels' curve constants are set to the average between the knob value
(`[-1, 1]`) and the CV value:
- `0V` is equivalent to a curve constant of `-1`
- `50%` of `MAX_INPUT_VOLTAGE` is equivalent to a curve constant of `0`
- `100%` of `MAX_INPUT_VOLTAGE` is equivalent to a curve constant of `+1`

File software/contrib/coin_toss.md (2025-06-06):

# Coin Toss

Two pairs of clocked probability gates.

## Inputs & Outputs

Inputs:
- `din`: External clock (when in external clock mode)
- `ain`: Threshold control (summed with threshold knob)
- `k1`: internal clock speed
- `k2`: probability threshold
- `b1`: toggle internal / external clock source
- `b2`: toggle gate/trigger mode

Outputs:
- `cv1` & `cv2`: Coin 1 gate output pair when voltage above/below threshold
- `cv3`: Coin 1 clock
- `cv4` & `cv5`: Coin 2 gate output pair at 1/4x speed
- `cv6`: Coin 2 clock

Knob 1 adjusts the master clock speed of gate change probability. Knob 2 moves
the probability thresholed between A and B with a 50% chance at noon. Output
row 1 (cv1 and cv2) run at 1x speed and output row 2 (cv4 and cv5) run at
1/4x speed for interesting rhythmic patterns. Push button 1 to toggle between
internal and external clock source. Push button 2 to toggle between gate and
trigger mode. Analogue input is summed with the threshold knob value to allow
external threshold control.

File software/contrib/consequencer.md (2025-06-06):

# EuroPi Consequencer - A 6-channel open source sequencer and random source power house!

Consequencer is a gate and stepped CV sequencer inspired by Grids from Mutable Instruments and the
randomness created by the Turing Machine. Pattern changes and randomness are introduced as a
consequence of both manual input and control voltages sent to the analogue input. A large number of
popular gate patterns are pre-loaded. Stepped CV sequences are automatically generated.

Both gate patterns and CV sequences can be smoothly morphed between without disrupting playback.
Use outputs 1 - 3 for gates and outputs 4 - 6 for randomised stepped CV patterns.
Send a clock to the digital input to start the sequence.

Demo video: https://youtu.be/UwjajP6uiQU

Credits:
- The Europi hardware and firmware was designed by Allen Synthesis: https://github.com/Allen-Synthesis/EuroPi
- A small number of preloaded drum patterns were recreated from here: https://docs.google.com/spreadsheets/d/19_3BxUMy3uy1Gb0V8Wc-TcG7q16Amfn6e8QVw4-HuD0/edit#gid=0

# July 2022 Update - Probability based drum patterms

Consequencer now includes the ability to add probability-based steps to patterns!
You can use probability in patterns to add variabilty in interesting ways.
Some example patterns have been included in this release and you can find instructions below in the
"Advanced usage" section for adding your own.

You can easiliy identify steps within patterns that have a probability less than 100%.
Normal steps are shown with a `^` character, whereas steps with a probability are shown with a `-`.

# Controls and Outputs

Operating Diagram

## Inputs

- digital_in: Clock in
- analog_in: Mode 1: Adjusts randonmess, Mode 2: Selects gate pattern, Mode 3: Selects stepped CV
  pattern

## Knobs

- knob_1: randomness
- knob_2: select pattern

## Buttons

button_1:
- Short Press  (<300ms)  : Play previous CV Pattern
- Medium Press (>300ms)  : Short Press: toggle randomized hi-hats on / off
- Long Press   (>3000ms) : Toggle option to send clocks from output 4 on / off
button_2:
- Short Press  (<300ms)  : Play next CV Pattern or generate a new one if needed
- Medium Press (>300ms)  : Cycle through analogue input modes
- Long Press   (>3000ms) : Toggle between pattern banks (original / grids)

## Outputs

- output_1: gate 1 e.g Kick Drum
- output_2: gate 2 e.g Snare Drum
- output_3: gate 3 e.g Hi-Hat
- output_4: randomly generated stepped CV
- output_5: randomly generated stepped CV
- output_6: randomly generated stepped CV

# Getting Started

The following sections provide instructions for creating a simple 3 drum pattern with a kick, snare
and hi-hat, then using random CV patterns to vary the timbre in each drum pattern. You can of course
connect outputs 1 - 3 to any module which expects gates and outputs 4 - 6 to any module expecting a
control voltage.

## Basic Usage
1. Connect a clock input to the Digital input
2. Connect a Bass Drum to output 1, Snare to output 2 and Hi-hat to output 3
3. Start your clock - a pattern will output gates on outputs 1 -3
4. Select different patterns manually using knob 2 (right-hand knob). The selected pattern is shown
   visually on the screen.

## Adding randomness
1. A medium-press (>300ms and < 3000ms) and release of button 1 toggles on/off the real-time
   generation of a random gate pattern to output 3. A small filled rectangle is shown on the bottom
   left of the screen when this feature is active.
2. Knob 1 increases or decreases the randomness of the patterns sent to outputs 1 -3
3. Randomness can also be controlled by sending CV to the analogue input if analogInputMode 1 is
   selected (default).

## Using random CV from outputs 4 - 6

Outputs 4 - 6 provide a random pattern of stepped CV which is sync'd with the inbound clock.
A short-press and release of button 2 will generate a new pattern for all 3 outputs.

Example usage for these CV outputs, (this will depend on the inputs your drum module has):
- Snare Decay
- Hi-Hat decay (simulate an open hi-hat)
- Hi-Hat pitch
- Velocity
- Kick decay
- Kick accent
- Send stepped CV into the cutoff frequencer of a VCF (Voltage Controlled Filter)
- Send stepped CV into a quantizer, then feed the quantized output into a VCO (Voltage Controlled
  Oscillator)

## Selecting analogue input modes

Consequencer can perform 3 different actions when a control voltage input is received at the
analogue input. The current running mode is shown on the bottom right of the screen (e.g. Mr, Mp, Mc)
Cycle through the modes by long-pressing and releasing button 2. The following modes are available:

- Mode 1 (Mr) : Control voltage adjusts randomness of the gate patterns sent to outputs 1 - 3
- Mode 2 (Mp) : Control voltage selects the gate pattern
- Mode 3 (Mc) : Control voltage selects the stepped CV pattern

## Controlling a pattern using CV

1. Select analogInputMode 2 (Mr) using button 2.
2. Send a control voltage into the analogue input

A fixed voltage will select a single pattern and varying voltage (e.g. an envelope or LFO) will
smoothly cycle through patterns.

# Grids Patterns

The 25 different patterns from the Mutable Instruments Grids module were exported from the Grids
code and added to the Consequencer.

Access the Grids patterns by holding button 2 for 3-5 seconds and releasing.
When Grids mode is enabled, a period '.' is visible before the pattern number on the bottom right of
the screen

Two different versions of each Grids pattern have been created. The first version (even numbers,
including 0) are the equivalent of having all three Grids density knobs at 50%. The second version
(odd numbers) are the equivalent of having all three Grids density knobs at 70%. An example is below:

- Pattern 0: Grids pattern 1, density: 50%
- Pattern 1: Grids pattern 1, density: 70%
- Pattern 2: Grids pattern 2, density: 50%
- Pattern 3: Grids pattern 2, density: 70%

# Screen saver

To improve performance a little, a screen saver mode has been added which turns the screen off if
the module has not been interacted with in 10 seconds. The screen saver is turned off as soon as an
interaction occurs. Example interactions are knob movement and button presses.

# Advanced usage

## Adding / Removing / Updating Gate Patterns

Patterns can be added, removed or updated by updating the relevant list structures at the end of the
consequencer.py file in the pattern class (look for the line `class pattern:`). Once patterns are
updated make sure you save a copy of the updated file to the EuroPi using yoru favourite method
(Thonny / REPL), then restart the Consequencer script.

The syntax should be intuitive. An example pattern is shown below. Each `1` or `0` represents a gate
or no gate at that point in the sequence.
The mapping of `BD`, `SN`, `HH` is as follows:
- BD: Output 1
- SN: Output 2
- HH: Output 3

Starting with the July 2022 update, steps now also have a probability which is configured using the
BdProb, SnProb and HhProb sections as shown below.
Use a value from `1` to `9` to set the desired level of probability for each step.
A value of `9` will cause the step to trigger 100% of the time, any value from `1` to `8` will
trigger the step from n/9 times.

You can also use shorthand to define probabilities, for example:

- A single digit probability string is auto-populated for all values. e.g. a probability of `9` for
  an 8 step pattern will automatically become `99999999`

- A multi-digit probability string that is shorter in length than the pattern string is
  automatically filled with the last digit in the probability string. e.g. a probability of `9995`
  for an 8 step pattern will automatically become `99995555`.

Example valid patterns and probability patterns are shown below.

```
    BD.append("1001001001000100")
    SN.append("0001000000010000")
    HH.append("1111111111111111")
    BdProb.append("9999999999999999")
    SnProb.append("9999999999999999")
    HhProb.append("9999999999999999")

    BD.append("1001001001000100")
    SN.append("0001100000010000")
    HH.append("1010101010110101")
    BdProb.append("9")
    SnProb.append("99995")
    HhProb.append("95")

```

## Output clocks/gates on output 4

The Consequencer has a small amount of latency between receiving a clock or gate at the digital
input and sending out gates to the outputs. This may not be noticable depending on how you
incorporate Consequencer into your patch. However, there is an option for Consequencer to send out
gates on output which are perfectly in time with the sequence being played. This allows you to clock
other modules using output 4.

To enable this feature hold down button 1 for longer than 3 seconds, then release the button. A
small unfilled rectangle is shown on the bottom left of the screen when this feature is active. This
visual indicator is on the right of the random hi-hat visual indicator (filled rectangle on the
bottom left of the screen).

# Known bugs / Interesting features

A small amount of noise causes the analogue input to vary slightly. This can sometimes cause the
randomness, gate pattern or stepped CV pattern to flicker between values. It happens only
occassionally, but introduces an interesting and subtle variation to the sequence being played.

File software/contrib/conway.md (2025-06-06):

# John Conway's Game of LiFO

This script implements [John Conway's Game Of Life](https://en.wikipedia.org/wiki/Conway%27s_Game_of_Life)
as the procedural kernel for multiple LFOs.

The game is played on a 128x32 field (the size of the OLED). Every pixel is a cell. On every step an
empty space will spawn a new cell if it has exactly 3 neighbours. Cells with 2 or 3 neighbours stay
alive. Cells with 1 or 0 neighbours die of loneliness. Cells with 4 or more neighbours die of
overcrowding.

This program acts as a free-running LFO; it is not clockable externally.

On every step, a number of random new cells will also spawn, based on the CV input provided on
`ain`. `k2` acts as an attenuator for the signal on `ain`.

## Inputs

| Input | Usage |
|---|---|
| `din` | Clear the field & start a new random spawn |
| `ain` | Offset control for spawn density |
| `b1` | Manual equivalent to `din` |
| `b2` | Manual equivalent to `din` |
| `k1` | Base spawn density |
| `k2` | Attenuverter for `ain` |

## Outputs

| Output | Description |
|---|---|
| `cv1`  | 0-10V depending on the Shannon entropy of the entire field |
| `cv2`  | 0-10V depending on the ratio between the number of births and the total population of the current generation |
| `cv3`  | 0-10V depending on the ratio between the number of births and the number of deaths in the current generation |
| `cv4`  | 5V trigger when every generation is computed |
| `cv5`  | 5V gate if the number of births in the current generation was greater than the number of deaths |
| `cv6`  | 5V trigger if the field has reached a point of stasis (see below) |

If global voltage limits [have been changed](../CONFIGURATION.md) then those limits will be used
instead of the 10V or 5V values described above.

## Stasis Detection

Because of the modest computing power available, this program uses some simple statistics to infer
if the game has reached a point of stasis. There is a chance that false-positives and
false-negatives can be detected.

When the game is believed to have reached a state of stasis it will automatically reset, as if a
signal had been detected on `din`.  The field will clear and be filled with random data with a
density governed by `ain`, `k1`, and
`k2`.

The game is assumed to have reached a state of stasis under these conditions:
1. at least 12 generations have passed since the last reset, and one of
2. the number of game spaces that have changed from dead to alive or alive to dead is equal to
   zero, or
3. The sum of population changes in groups of 2, 3, or 4 generations has a standard deviation of
   1.0 or less and the absolute value of the mean of the group is less than 1.0.

To better-explain 3, consider the following 12 generations' of population changes:
```
[16, -17, 18, -14, 8, -23, 0, -3, 13, -12, 6, -5]
```

Grouping these changes into buckets of 2, 3, or 4 generations we produce these summed buckets:

```
Size 2: [-1, 4, -15, -3, 1, 1]
Size 3: [17, -29, 10, -11]
Size 4: [3, -18, 2]
```

We calculate the mean and standard deviation of each set of buckets, giving:
```
Size 2: -2.167, 6.69328
Size 3: -3.25, 18.08833
Size 4: -4.333, 9.672412
```

In this case none of the standard deviations nor means have a magnitude smaller than 1, so the
system is not considered to be in stasis.

Conversely, given these population changes:
```
[-12, 6, 4, 2, -12, 6, 4, 2, -12, 6, 4, 2]

Size 2: [-6, 6, -6, 6, -6, 6] -> 0.0, 6.0
Size 3: [-2, -4, -6, 12]      -> 0.0, 7.071068
Size 4: [0, 0, 0]             -> 0.0, 0.0
```
we would assume we have reached stasis, as the mean and standard deviation of the size-4 buckets are
less than 1.0.

## LFO Rate Variablility

Because of the implementation of Conway's Game of Life, when the field is densely-populated,
e.g. immediately after a reset with a high spawn rate, the outputs will change relatively slow.  As
cells die off and the field becomes more sparse the rate will increase.  This is normal.

## Patch Ideas

You can patch an external LFO into DIN to periodically reset the simulation before it reaches a
state of stasis.

You can create interesting feedback by patching `cv1`-`cv3` into `ain` and using the gate/trigger
signals from `cv4`-`cv6` to control the simulation reset rate & reset density.

If the variation in the LFO rate causes problems you can take the outputs from Conway and connect
them to an externally-clocked Sample & Hold module. This will smooth out the changes in the update
frequency of Conway.

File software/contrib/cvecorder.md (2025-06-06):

# CVecorder

CVecorder ("Sveecorder") is a 6 bank, 6 channel CV recording and playback program that runs on the
EuroPi from [Allen-Synthesis](https://github.com/Allen-Synthesis/EuroPi). It can be used to control
the CV of any module in a really fine-grained way, rather than spending time creating CV patterns
with sequencers, envelopes or LFOs, you simply record the exact CV pattern you want and have this
played back into your modules.

Also, because CVecorder has 6 banks you can record 6 different variations of 6 channels of CV, then
smoothly change between them during a performance without skipping a beat!

Note, due to limitations in the Raspberry Pi pico (the hardware running behind the EuroPi), only
positive CV can be recorded and played back.

Demo video: https://youtu.be/Crj0P7pr2YA

## Controls and Display

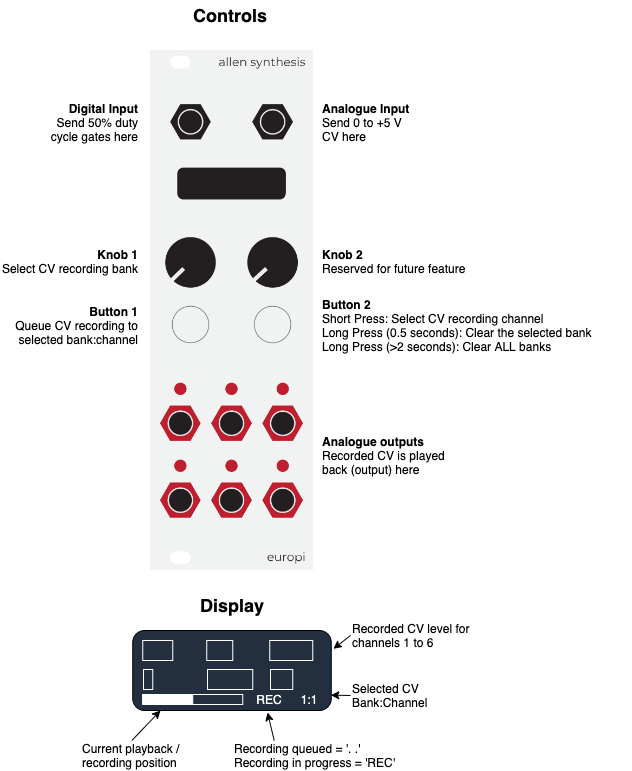
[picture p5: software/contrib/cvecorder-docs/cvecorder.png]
Operating Diagram


## Getting Started

The following sections provide instructions for recording and playing back CV using CVecorder.

### Initial Connections
1. Connect a 50% duty cycle gate input to the Digital input
2. Connect a CV source to the analogue input (0 to +5V works best)
3. Connect each output (1 to 6) to modules you want to send CV to

### Recording and Playing back CV
CVecorder records CV using the following format:
- Each CV channel records a total of 64 CV values (samples).
- Two CV samples are recorded for each received gate. One sample is captured on the rising edge,
  another on the falling edge.
- Each CV channel is looped with every 32nd gate into the Digital input.
- Each CV sample is captured with a resolution of 0 - 9.99, providing a resolution of 1000 potential
  CV values to record.
- Each CV channel relates directly to each output. CV channel 1 sends the recorded CV to output 1,
  CV channel 2 to output 2 and so on.
- There are 6 banks of 6 CV channels, allowing you to record 6 variations of CV recordings in each
  bank and move smoothly between them during a performance.

To record and playback CV:
1. Send a 50% duty cycle gate to the Digital input, this will automatically start the CVecorder. You
   will see this on the display on the bottom left-hand side.
2. Select the required bank using knob 1
3. Select the required channel using button 2
4. Press button 1 to queue CV recording to the selected bank:channel. You will see indicator at the
   bottom of the screen change to '. .' , CV recording will start at the beginning of the CV
   channel. 'REC' will be displayed when recording has started.
5. At the end of the channel, the recorded CV is output from the corresponding output.
6. Select the next required CV channel using button 2, then repeat step 4.
7. Once you have everything the way you want it on bank 1, select the next bank using knob 1 and
   record your next set of 6 CV channels to the next bank.
8. During your performance, you can move smoothly between each CV bank using knob 1. This allows you
   to switch between 6 variations of CV to all 6 outputs.

## Saving CV between power cycles
Every time you record a new CV channel, CV is automatically saved to local storage on the Raspberry
Pi pico. This means that you can power off your module at any time (other than during the recording
of a channel) and it will always be available when you power back up.

To overwrite saved CV simply record over it. However, if you would prefer to clear an entire bank or
all banks use button 2 - see 'Clearing banks' for more info.

### Clearing banks and channels
If you want to update the CV recorded into a channel, simply record over it. To clear a bank, repeat
this process for all channels in the bank. However, if you would rather clear a channel completely
hit record and send no CV into the channel during the recording period.

## Patching ideas

### Painting quantized melodies

This patch allows you to paint melodies using a CV source like a joystick.
CV is recorded and played back by the CVecorder, which is quantized to scale and sent to a VCO.

1. Connect a 50% duty cycle gate to the Digital input
2. Connect a CV source to the analogue input (0 to +5V works best) for example a joystick

If your quantizer has a trigger input:

3. Mult / Divide the gate input and connect to the quantizer trigger input. This will sample CV from
   the CVecorder each time it receives a gate
4. Connect CVecorder output 1 to the quantizer input
5. Connect the quantizer output to a VCO
6. Play around with subtle movements on your CV controller and hear the melodies come out of your
   VCO!

If your quantizer has no trigger input:

3. Mult / Divide the gate input and connect to a sample and hold trigger/clock input
4. Connect CVecorder output 1 to a sample and hold CV input
5. Connect the sample and hold output the quantizer input
6. Connect the quantizer output to a VCO

### Extreme FX control

This patch provides super-granular control of FX modules, allowing you to control the value of each
FX parameter up to two times with each clock cycle. Doing this can create both smooth and whacky FX
changes.

1. Connect a 50% duty cycle gate to the Digital input
2. Connect a CV source to the analogue input (0 to +5V works best) for example a joystick
3. Connect each of the outputs to parameters on your FX module
4. Play around with different combinations of CV across the different channels to have fine-grained
   control of your FX CV parameters

### Creating percussion variations

This patch allows you to add interesting variations to your percussion.

1. Connect a 50% duty cycle gate to the Digital input
2. Connect a CV source to the analogue input (0 to +5V works best) for example a joystick
3. Connect each of the outputs to parameters on your percussion modules, for example connect to
   inputs that control pitch, accents, timbre or sample.
4. Play around with different combinations - if it sounds good stick with it!

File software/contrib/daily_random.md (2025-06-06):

# Daily Random

Generates pseudo-random gate and CV patterns based on the current date and time.

## I/O Assignments

- `ain`: not used
- `din`: external clock input
- `b1`: not used
- `b2`: not used
- `k1`: not used
- `k2`: not used
- `cv1`: daily gate sequence (updates at midnight local time)
- `cv2`: hourly gate sequence (updates at the top of every hour)
- `cv3`: minute gate sequence (updates at the top of every minute)
- `cv4`: daily CV sequence (updates at midnight local time)
- `cv5`: hourly CV sequence (updates at the top of every hour)
- `cv6`: minute CV sequence (updates at the top of every minute)

## Required Hardware

This script _can_ be used on a normal EuroPi, but will result in highly predictable
patterns. For best results, connect a Realtime Clock (RTC) to EuroPi's secondary I2C
header pins, located on the underside of the board.

See [Realtime Clock Installation](/software/realtime_clock.md) for instructions on
installing and configuring the realtime clock.

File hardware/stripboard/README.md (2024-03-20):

# Stripboard Layouts

These designs have been generously provided by [Timmoneer](https://github.com/stripboard-layouts), and the original files [can be found here](https://github.com/stripboard-layouts/lament-for-mills/tree/main/Allen%20Synthesis%20EuroPi).

This build hasn't been tested by Allen Synthesis, but has been found to work successfully, so if you are looking to make a lower budget build, or you are looking for a nicer platform to modify the project on, this may be the way to go!

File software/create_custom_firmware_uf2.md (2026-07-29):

# Creating a custom firmware.uf2 image for EuroPi

## Compiling the firmware on Windows
1. If not already installed, install [Docker](https://docs.docker.com/desktop/install/windows-install/)
1. If not already cloned, [create a local clone](https://docs.github.com/en/repositories/creating-and-managing-repositories/cloning-a-repository?tool=desktop) of the EuroPi repository
1. Run Docker
1. Click the windows file manager file path *inside* the root folder of your clone of the EuroPi repo (the folder named 'EuroPi', not any of the folders inside it)
    
1. Type `cmd`
    
1. Press Enter
1. In the new terminal window, type `software\uf2_build\build_uf2.bat`
1. Press Enter
1. Wait for .uf2 to compile (this may take some time, do not close the terminal window)
1. The custom .uf2 build can be found at `EuroPi\software\uf2_build\europi-dev.uf2`

## Compiling the firmware on Mac/Linux (using Docker)
The same process described above for Windows can also be used on Mac and Linux, with a few small changes.
1. If not already installed, install Docker
   * [Linux instructions](https://docs.docker.com/desktop/setup/install/linux/)
   * [Mac instructions](https://docs.docker.com/desktop/setup/install/mac-install/)
1. If not already cloned, [create a local clone](https://docs.github.com/en/repositories/creating-and-managing-repositories/cloning-a-repository?tool=desktop) of the EuroPi repository
1. Open a terminal (ctrl+alt+T on most desktop Linux distributions) and run `cd /path/to/EuroPi` (replacing the path with the path to the repository cloned above)
1. In the same terminal, run `./software/uf2_build/build_uf2.sh`
1. Wait for .uf2 to compile (this may take some time, do not close the terminal window_
1. The custom .uf2 build can be found at `EuroPi/software/uf2_build/europi-dev.uf2`

## Compiling the firmware on Mac/Linux (without Docker)
The instructions below describe the steps needed to build the uf2 locally on your machine for
development purposes. Alternatively you can run the script `software/uf2_build/build_uf2.sh` to
build the image in a docker container. You will need to have [docker](https://docs.docker.com/get-started/)
installed and running. See the script for execution details.
``` Bash
# install extra tools if not already done so
$ sudo apt update
$ sudo apt install cmake gcc-arm-none-eabi libnewlib-arm-none-eabi build-essential

# get micropython source from github repo
# choose latest stable version instead of the master branch
$ git clone -b v1.20.0 https://github.com/micropython/micropython.git

# fetch submodules
$ cd micropython
$ make -C ports/rp2 submodules

# build tools
$ make -C mpy-cross

# enter the dir for our hardware port
$ cd ports/rp2

$ ls
# files that should be frozen and included in the firmware should be placed in the 'modules' dir
# so thats 'micropython/ports/rp2/modules/'
# what should be done here is written below
# once that has been done you can continue to make the firmware

# optional clean up
$ make clean

# build the firmware
$ make
```

## Modules dir
after the files for EuroPi, EuroPi contrib and ssd1306 are inserted
the structure of the modules dir should look like this:
```
micropython/ports/rp2/modules/
├── _boot_fat.py
├── bootloader.py
├── bootloader_mode.py
├── _boot.py
├── configuration.py
├── contrib
│   ├── bernoulli_gates.py
│   ├── coin_toss.py
│   ├── consequencer.py
│   ├── cvecorder.py
│   ├── diagnostic.py
│   ├── hamlet.py
│   └── ...
├── europi.py
├── europi_config.py
├── europi_display.py
├── europi_hardware.py
├── europi_log.py
├── europi_script.py
├── experimental
│   ├── __init__.py
│   ├── a_to_d.py
│   ├── bisect.py
│   ├── bitarray.py
│   ├── clocks
│   |   ├── __init__.py
│   |   ├── clock_source.py
│   |   ├── ds1307.py
│   |   ├── ds3231.py
│   |   ├── ntp.py
│   |   └── null_clock.py
│   ├── custom_font.py
│   ├── fonts
│   |   ├── __init__.py
│   |   ├── freesans14.py
│   |   ├── freesans17.py
│   |   ├── freesans20.py
│   |   ├── freesans24.py
│   |   ├── ubuntumono14.py
│   |   ├── ubuntumono17.py
│   |   ├── ubuntumono20.py
│   |   └── ubuntumono24.py
│   ├── euclid.py
│   ├── experimental_config.py
│   ├── http_server.py
│   ├── knobs.py
│   ├── math_extras.py
│   ├── osc.py
│   ├── quantizer.py
│   ├── random_extras.py
│   ├── rtc.py
│   ├── screensaver.py
│   ├── settings_menu.py
│   ├── thread.py
│   └── wifi.py
├── file_utils.py
├── main.py (optional)
├── rp2.py
├── setup.py
├── ssd1306.py
├── tools
│   ├── __init__.py
│   ├── about.py
│   ├── calibrate.py
│   ├── conf_edit.py
│   ├── diagnostic.py
│   └── experimental_conf_edit.py
├── ui.py
└── version.py
```
_boot.py should be modified to look like this: (increase progsize)
``` Python
import os
import machine, rp2

bdev = rp2.Flash()
try:
    vfs = os.VfsLfs2(bdev, progsize=1024)
except:
    os.VfsLfs2.mkfs(bdev, progsize=1024)
    vfs = os.VfsLfs2(bdev, progsize=1024)
os.mount(vfs, "/")

del os, bdev, vfs
```
main.py could look like this: (It's important to call the garbage collector to make space for the software)
``` Python
import gc
gc.collect()
from contrib.menu import *
BootloaderMenu(EUROPI_SCRIPTS).main()
```

## Import priority
When using import in micropython it will look for the file according to the priority defined by the position in sys.path.
So it will look at / and /lib first, before looking in the frozen firmware modules.
However if the frozen modules of the firmware include a main.py it will autostart this and ignore any main.py located in /.

## Freezing bytecode instead of source code
By default the files from the modules dir will be frozen (included in the firmware) as python source files (.py). Alternatively it is also possible to freeze the precompiled bytecode generated from these source files. Using precompiled bytecode instead of raw source code will reduce RAM usage might slightly improve execution performance. To freeze bytecode instead of source code manifest.py can be altered to look like this:

micropython/ports/rp2/boards/manifest.py
``` Python
freeze_as_mpy("$(PORT_DIR)/modules")
freeze("$(MPY_DIR)/drivers/onewire")
freeze("$(MPY_DIR)/drivers/dht", "dht.py")
include("$(MPY_DIR)/extmod/uasyncio/manifest.py")
include("$(MPY_DIR)/drivers/neopixel/manifest.py")
```

More details about the benefits of bytecode and documentation about manifest.py can be found here: https://docs.micropython.org/en/latest/reference/manifest.html

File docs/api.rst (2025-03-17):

API
===

.. autosummary::
   :toctree: generated

   europi
   europi_config
   europi_display
   europi_hardware
   europi_log
   europi_script
   configuration
   file_utils
   ui
   experimental
   experimental.a_to_d
   experimental.bisect
   experimental.bitarray
   experimental.euclid
   experimental.http_server
   experimental.knobs
   experimental.math_extras
   experimental.osc
   experimental.quantizer
   experimental.random_extras
   experimental.rtc
   experimental.screensaver
   experimental.settings_menu
   experimental.thread
   experimental.wifi
   experimental.clocks.clock_source
   experimental.clocks.ds1307
   experimental.clocks.ds3231
   experimental.clocks.ntp
   experimental.clocks.null_clock
   tools.about
   tools.calibrate
   tools.conf_edit
   tools.diagnostic
   tools.experimental_conf_edit

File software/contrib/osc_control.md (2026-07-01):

# Open Sound Control (OSC) Interface

This program allows the use of Open Sound Control packets over UDP to control
EuroPi.

## OSC Addresses

The following addresses are used by the program (noting that the `/europi` namespace
can be changed; see below):

- `/europi/cv1`
- `/europi/cv2`
- `/europi/cv3`
- `/europi/cv4`
- `/europi/cv5`
- `/europi/cv6`

All of the above will accept float or integer data. Floats are treated as the 0-1
level for CV control. Integers are treated as boolean on/off signals (0 for off, anything
else for on).

- `/europi/cvs`

The above accepts 6 parameters of either float or integer, and will set all 6 outputs
with a single packet.

In addition to the input addresses above, EuroPi will broadcast the following addresses
at 20Hz:

- `/europi/ain`: float, the 0-1 input level
- `/europi/k1`: float, the knob position as a value in the range 0-1
- `/europi/k2`: float, the knob position as a value in the range 0-1
- `/europi/din`: integer, a 0/1 value indicating if the input is off or on
- `/europi/b1`: integer, a 0/1 value indicating if the button is pressed or not
- `/europi/b2`: integer, a 0/1 value indicating if the button is pressed or not

## Multiple EuroPi on the same network

If you have more than one EuroPi you may find it desirable to assign each their own
namespace. Otherwise by moving one fader on your OSC input device you may control
all EuroPis at once.

Create `/config/OscControl.json` to set the namespace:

```json
{
    "NAMESPACE": "/europi_1"
}
```

If the namespace does not start with `/`, a `/` will automatically be added.  If the namespace
is left empty, it will default to `/`.

## Changing the topics

The input & output topics described above are defaults. To rename the topics (e.g. to facilitate
easier interaction with other devices) the topics can be customized by specifying the topics for
each output: `/config/OscControl.json`:

```json
{
    "CV1_TOPIC": "cv1",
    "CV2_TOPIC": "cv2",
    "CV3_TOPIC": "cv3",
    "CV4_TOPIC": "cv4",
    "CV5_TOPIC": "cv5",
    "CV6_TOPIC": "cv6",
    "CVS_TOPIC": "cvs",

    "AIN_TOPIC": "ain",
    "DIN_TOPIC": "din",
    "K1_TOPIC": "k1",
    "K2_TOPIC": "k2",
    "B1_TOPIC": "b1",
    "B2_TOPIC": "b2",
}
```

If the topics begin with a `/`character, they are treated as absolute topic names. If they do not
start with `/` they will be included in the `NAMESPACE` defined above.

## Changing the port

TouchOSC uses UDP port 9000 by default, so that's what EuroPi looks for. To override
the default with a different port, set the port in `/config/OscControl.json`, e.g.:

```json
{
    "RECV_PORT": 6024
}
```

## Sending data

To configure the port & IP address that button, knob, `ain`, and `din` states are send,
set the `SEND_PORT` and `SEND_ADDR` keys in `/config/OscControl.json`, e.g.:

```json
{
    "SEND_ADDR": "192.168.4.100",
    "SEND_PORT": 9001,
}
```

## Configuring TouchOSC

[TouchOSC](https://hexler.net/touchosc) is a commercial program available for a variety
of platforms that allows you to create custom OSC input interfaces.

### Network setup

Press the link button to configure TouchOSC's connection to your EuroPi.

Select `UDP` as the connection type and enter the IP address of your EuroPi and
enter the following:
- `Host`: EuroPi's IP address
- `Send Port`: the `RECV_PORT` value configured on EuroPi; this is the port TouchOSC
  sends data, and the port that EuroPi correspondingly listens on
- `Receive Port`: the `SEND_PORT` value that you configured on EuroPi; this is the
  port TouchOSC listens for data on, and correspondingly the port EuroPi sends data on
- `Zeroconf`: leave as `Default` unless you have a specific requirement to change this

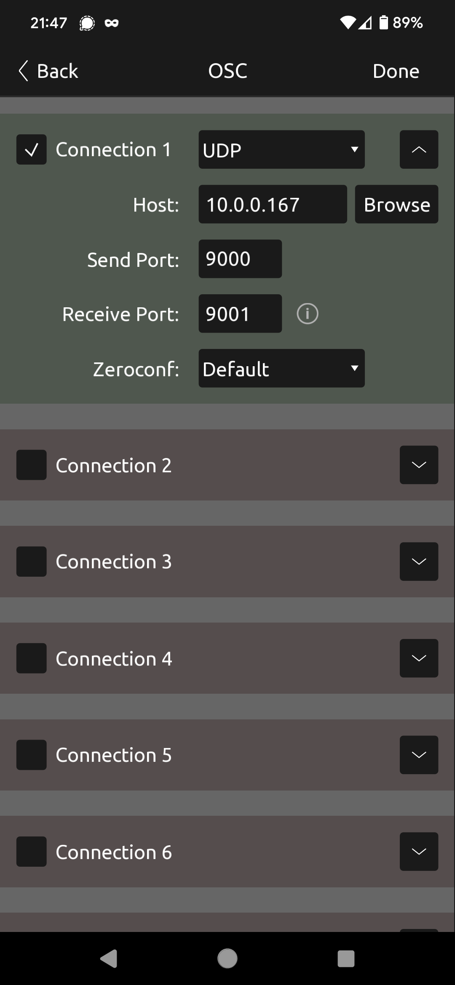
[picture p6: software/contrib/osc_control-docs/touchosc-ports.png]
TouchOSC network setup


_Configuring TouchOSC's networking_

### UI setup

#### Sample Setup

A [sample configuration file](/software/desktop/touch_osc/europi.tosc) is provided
in the `software/desktop` directory. Copy this file onto your device and import it into
TouchOSC. This will automatically add the following controls:

TouchOSC Sample Config

- 6 red sliders to control EuroPi's outputs
- green indicators for the values of `din` and `ain`
- blue indicators for the values of `k1`, `k2`, `b1`, and `b2`

#### Manual Setup

To manuyally set up TouchOSC to control EuroPi, add six sliders to your panel. Then edit each
slider to set its name to `europi/cvN` where `N` is the number `1` to `6`.

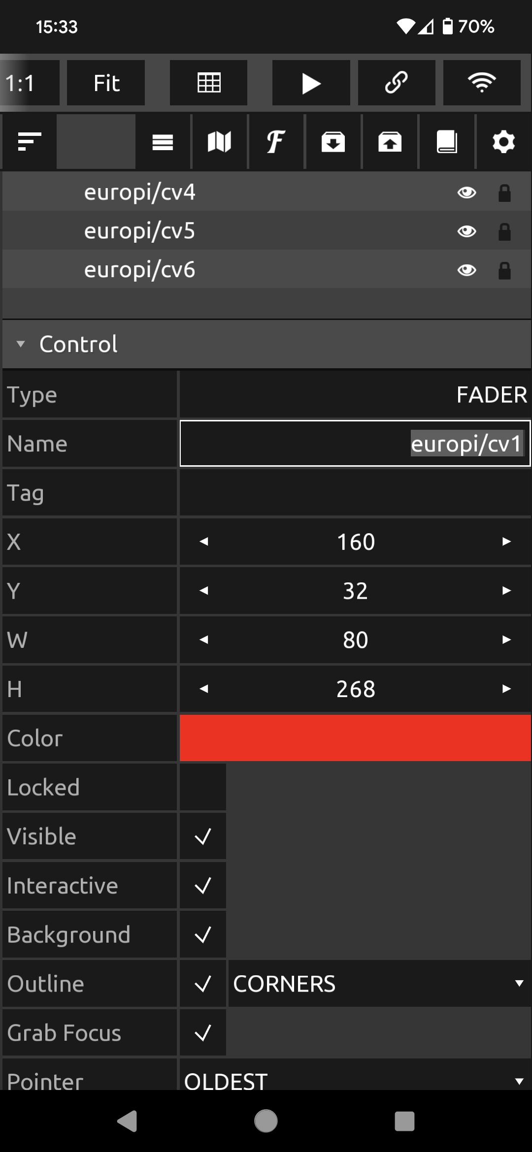
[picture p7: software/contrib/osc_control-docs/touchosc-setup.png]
TouchOSC Setup


_Configuring a slider's name in TouchOSC on Android_

Then configure TouchOSC's `OSC` connection to connect to your EuroPi's IP address. Your
phone/table must either be connected to EuroPi's access point, or both must be connected
to the same wifi network.

Once configured, start TouchOSC's interface by pressing the triangular "Play" button.

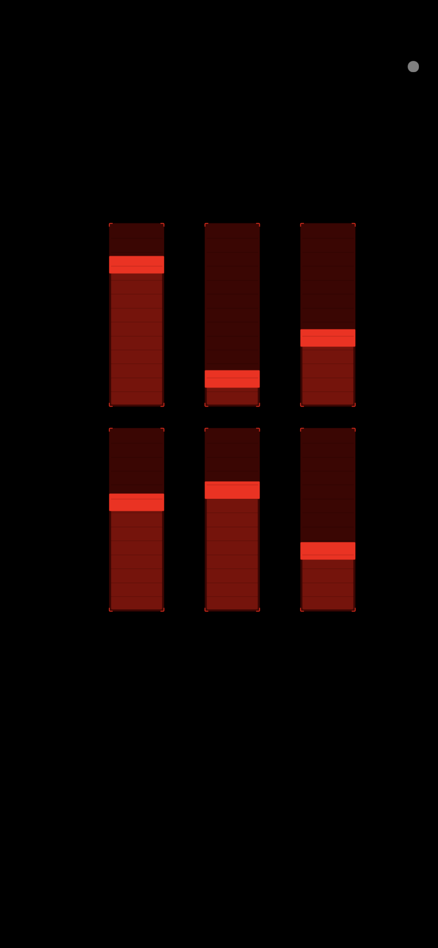
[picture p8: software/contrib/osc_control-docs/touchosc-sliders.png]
TouchOSC Setup


_TouchOSC's sliders_

EuroPi's OLED will show bars indicating the levels of TouchOSC's sliders

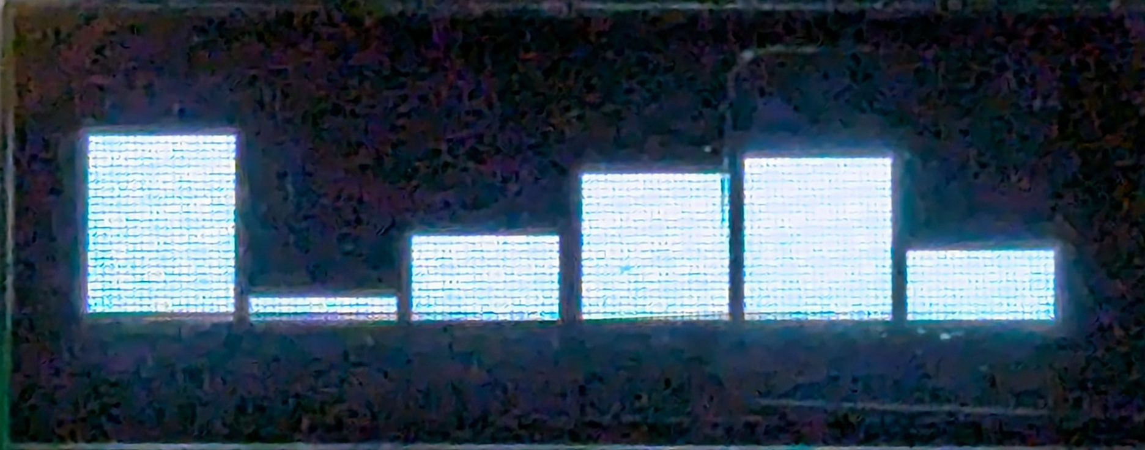
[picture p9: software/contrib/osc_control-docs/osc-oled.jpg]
EuroPi OLED


_EuroPi's OLED showing the same slider levels as TouchOSC_

## Using 8mu

If you have a [Music Thing Modular 8mu](https://www.musicthing.co.uk/8mu_page/)
you can use it to control EuroPi via OSC.

Refer to the [OSC 8mu interface](/software/desktop/osc_8mu/README.md.md) for details on
how to set up your computer to read 8mu's sliders and convert them to OSC
messages for EuroPi.

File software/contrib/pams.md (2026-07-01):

# Pam's "EuroPi" Workout

This program is an homage to [ALM's Pamela's "NEW" Workout](https://busycircuits.com/alm017/)
and [Pamela's "PRO" Workout](https://busycircuits.com/alm034/) modules, reimagined for the EuroPi.
It is intended to be used as a main clock generator, euclidean rhythm generator, clocked LFO,
clocked random voltage source, etc... with optional quantization.

The module itself will generate the master clock signal with a configurable BPM (1-240 BPM
supported). Each output has an independently controlled clock multiplier or divider, chosen from
the following:

```
[x16, x12, x8, x6, x4, x3, x2, x1, /2, /3, /4, /6, /8, /12, /16]
```

## I/O Mapping

| I/O | Usage
|---|---|
| `din` | External control input (see below) |
| `ain` | Routable CV input to control other parameters |
| `b1` | Start/Stop input |
| `b2` | Press to enter/exit edit mode. Long-press to enter/leave sub-menu |
| `k1` | Routable CV input to control other parameters |
| `k2` | Menu navigation |
| `cv1` - `cv6` | Output signals. Configuration is explained below |

If you accidentally press `b2` and enter edit mode, you can long-press `b2` to change
menu levels and cancel the current operation, without modifying the setting you had
selected.

`din` can be configured to operate in multiple modes:
- start/stop trigger
- run gate
- reset trigger

## Menu Navigation

Rotate `k2` to scroll through the current menu. Pressing and holding `b2` for 0.5s will
enter a sub-menu. Pressing and holding `b2` again will return to the parent menu.

On any given setting, pressing `b2` (without holding) will enter edit mode for that
item. Rotate `k2` to choose the desired value for the item, and press `b2` again
to apply it.

The menu layout is as follows:

```
Clock
 +-- BPM*
 |    +-- DIN Mode
 |    +-- Reset
 |
CV1
 +-- Mod.*
 |    +-- Wave Shape**
 |    +-- Wave Width (PWM/Symmetry)*
 |    +-- Phase*
 |    +-- Wave Amplitude*
 |    +-- Attack*
 |    +-- Decay*
 |    +-- Sustain*
 |    +-- Release*
 |    +-- Skip Probability*
 |    +-- Euclidean Steps*
 |    +-- Euclidean Triggers*
 |    +-- Euclidean Rotation*
 |    +-- Swing Percentage*
 |    +-- Quantization Scale*
 |    +-- Quantizer Root*
 |    +-- Mute
 |    +-- Save
 |    +-- Load
 |    +-- Reset
 |
CV2 to 6
 +-- Same as CV1
 |
AIN
 +-- Gain
 |    +-- Precision
 |
Visualization
```

`*` These settings can be automatically selected using voltage coming into `ain`.

`**` This setting can be set up to work as a sample & hold for the signal coming into `ain`.

Some settings (e.g. ADSR envelope parameters, quantization root) are hidden from the menu if they
would be ignored by the current configuration for that channel.

The vizualization does not have any submenu items and simply displays the voltages of `CV1`-`6`,
`AIN`, and `K1`.

## Main Clock Options

The main clock menu has the following options:

- `BPM` -- the main BPM for the clock. Must be in the range `[1, 300]`.

The submenu for the main clock has the following options:

- `DIN Mode` -- Control the action taken when a gate or trigger is sent to `DIN`:
  - `Gate`: the clock will start on a rising edge and stop on a falling edge
  - `Trigger`: the clock will toggle between the running & stopped states on a rising edge
  - `Reset`: the clock will not change, but all waveforms & euclidean patterns will reset to the
    beginning
  - `Ext. Clk`: the clock's BPM is dynamically calculated based on the input square wave. The input
    clock is synchronized to the `x1` outputs.
- `Stop-Rst` -- Stop & Reset: if true, all waves & euclidean patterns will reset when the clock
  starts. Otherwise they will continue from where they stopped

### External Clocking Limitations

Pam's can only be clocked within the `BPM` range described above. Any external clock signal that
is slower than the minimum BPM (1) or faster than the maximum BPM (300 at the time of writing) will
be clamped within this range.

Pam's internal clock will be hard-sync'd with the external signal on the external signal's rising
edge, so even at out-of-range speeds the system will make a best-effort to stay synchronized.

Clocking Pam's with a highly-variable clock source may result in synchronization issues. Because of
the hard-syncing that occurs, any `x1` outputs will remain mostly synchronized, but other outputs
may become desynchronized if the external clock speed varies too much.

## CV Channel Options

Each of the 6 CV output channels has the following options:

- `Mod` -- the clock modifier: `/16` to `x16`.  `x1` will output one waveform every beat (dictated
  by the BPM). Multipliers (`xN`) will output `N` waveforms every beat.  Divisions (`/N`) will
  output a waveform every `N` beats.

3 additional special-purpose clock mods are available:
- Reset Reset: a trigger that fires when the clock stops (can be used
  to trigger other modules to reset, e.g. sequencers sequential switches, other euclidean
  generators). The fired trigger is 10ms in duration at 10V times the channel's amplitude. e.g. at
  50% the trigger will be 5V.
- Start Start: a trigger that fires when the clock starts (can be
  used to trigger other modules, or reset on-start). The trigger is at least 10ms long, but is based
  on the clock speed and may be longer. Trigger voltage is 10V times the channel's amplitude. e.g.
  at 50% the trigger will be 5V
- Run Run: a gate that is high when the clock is running and low when
  the clock is stopped. As long as the clock is running the gate will remain high.  Gate voltage is
  10V times channel's amplitude. e.g. at 50% the gate is 5V.

See below for details on setting the channels' amplitude parameters

The submenu for each CV output has the following options:

- `Wave` -- the wave shape to output. Square/Triangle/Sine/Random/AIN
  - Square Wave Square: square/pulse wave with adjustable width
  - Triangle Wave Triangle: triangle wave with adjustable symmetry
    (saw to symmetrical triangle to ramp)
  - Sine Wave Sine: bog-standard sine wave
  - ADSR Envelope ADSR: an Attack/Decay/Sustain/Release envelope
  - Turing Turing: a shift-register like the Music Thing Modular
    Turing Machine. Can either output pulses or stepped CV.
  - Random Wave Random: outputs a random voltage at the start of
    every euclidean pulse, holding that voltage until the next pulse (if `EStep` is zero then every
    clock tick is assumed to be a euclidean pulse)
  - AIN AIN (S&H): acts as a sample & hold of `ain`, with a sample
    taken at the start of every euclidean pulse (if `EStep` is zero then every clock tick is assumed
    to be a euclidean pulse)
  - KNOB KNOB (S&H): acts as a sample & hold of `k1`, with a sample
    taken at the start of every euclidean pulse (if `EStep` is zero then every clock tick is assumed
    to be a euclidean pulse)

- `Width` -- width of the resulting wave. See below for the effects of width adjustment on different
  wave shapes
- `Phase` -- the phase offset of the wave. Starting a triangle at 50% would start it midway through
- `Ampl.` -- the maximum amplitude of the output as a percentage of the 10V hardware maximum
- `Attack` -- the percentage of the cycle time dedicated to the attack phase of an ADSR envelope
- `Decay` -- the percentage of the cycle time minus attack time dedicated to the decay phase of an
  ADSR envelope
- `Sustain` -- the percentage level of the sustain phase of an ADSR envelope
- `Release` -- the percentage of of the cyle time minus the attack & decay phases dedicated to the
  release phase of an ADSR envelope
- `TLen` -- The length of the Turning machine shift register
- `TLock` -- The lock value of the Turing machine shift register
- `TMode` -- The mode of the Turing machine: either `Gate` or `CV`
- `Skip%` -- the probability that a square pulse or euclidean trigger will be skipped
- `EStep` -- the number of steps in the euclidean rhythm. If zero, the euclidean generator is
  disabled
- `ETrig` -- the number of pulses in the euclidean rhythm
- `ERot` -- rotation of the euclidean rhythm
- `Swing%` -- percentage division between pairs of consecutive notes. 50% results in no swing. Less
  than 50% results in a short-long-short-long-... pattern of notes. Greater than 50% results in a
  long-short-long-short-... pattern of notes
- `Quant` -- quantization scale
- `Q Root` -- quantizer root: transposes the quantized output up by the number of semitones above C.
- `Mute` -- if a channel is muted its output will always be zero. A muted channel can still be
  edited.
- `Save` -- save the channel's current settings to one of 6 banks. Banks are shared across all
  channels
- `Load` -- load a channel's settings from one of 6 banks. Banks are shared across all channels
- `Reset` -- if set to `OK` all channel settings are reset to their defaults. Setting to `Cancel`
  takes no action

The values of the `Attack`, `Decay`, `Sustain`, and `Release` settings are ignored if the wave whape
is not set to `ADSR`

### Changing Settings While Clock is Running

Changing some settings while the clock is running may have undesirable side-effects, including
clicks, out-of-time triggers, and the like.  Generally-speaking it is best to make changes while
the clock is stopped.

Applies immediately, can be safely changed at any time:
- Mute
- Skip

Applies immediately, but may result in rapid output level changes, clicks, and similar effects:
- Wave shape
- Attack, Decay, Sustain, Release
- Width
- Phase
- Swing
- Quantizer mode
- Quantizer root
- Clock Mod

Can be changed safely at any time, but the effect is delayed until the current wave shape completes
its cycle:
- Euclidean length, triggers, rotation

### ADSR Envelope

The ADSR envelope is affected by the `Width`, `Amplitude` and `Phase` parameters:
- `Phase` will shift the timing of the envelope
- `Width` adjusts the total duration of the envelope. The envelope always starts at the beginning
  of the phase, but may end early, outputting 0.0V after the end of the release
- the `Amplitude` setting adjusts the overall height of the wave. The attack phase always reaches
  peak amplitude, and the sutain phase is calculated relative to the `Amplitude` setting.

The following diagram shows the breakdown of the ADSR envelope:

```
   Total cycle time T
(based on clock modifer)
|----------------------|
|                      | ___
|    /\                | Peak amplitude = Amplitude%
|   /  \               |
|  /    \_______       | ___
| /             \      |  |  S = Amplitude% * Sustain%
|/               \_____| _|_
|--A-|D|---S---|R|--0--|

|A| + |D| + |S| + |R| = T * Width%

T' = T * Width%
|A| = T' * Attack%
|D| = (T' - |A|) * Decay%
|R| = (T' - |A| - |D|) * Release%
|S| = T' - |A| - |D| - |R|
```

### Phase Offsets

The following ascii art shows the effect of phase on a squarewave.  Note that the wave is not
clipped; the entire wave form is simply shifted to the right by the phase percentage.

```
x1, phase = 0
 ____      ____      ____      ____
|    |    |    |    |    |    |    |
|    |    |    |    |    |    |    |
|    |____|    |____|    |____|    |____

x1, phase = 50
      ____      ____      ____      ____
     |    |    |    |    |    |    |    |
     |    |    |    |    |    |    |    |
 ____|    |____|    |____|    |____|    |

x1, phase = 25
   ____      ____      ____      ____
  |    |    |    |    |    |    |    |
  |    |    |    |    |    |    |    |
__|    |____|    |____|    |____|    |__
```

### Swing

The following ascii art shows the effects of chaning the swing parameter on a simple square wave.
Note that the duty cycle of the wave is preserved within each step, and each 2-note cycle takes the
same amount of time. Only the timing between the first and second notes of each pair is affected.

```
Swing = 50%
 ____      ____      ____      ____
|    |    |    |    |    |    |    |
|    |    |    |    |    |    |    |
|    |____|    |____|    |____|    |____

Swing = 25%
 __    ______        __    ______
|  |  |      |      |  |  |      |
|  |  |      |      |  |  |      |
|  |__|      |______|  |__|      |______

Swing = 75%
 ______        __    ______        __
|      |      |  |  |      |      |  |
|      |      |  |  |      |      |  |
|      |______|  |__|      |______|  |__
```

Setting the swing too high or too low, especially at higher clock speeds, can compress the shorter
note so much that it ceases to exist. In that case the 0-length note is skipped entirely. This can
lead to some interesting interactions with Euclidean patterns, as every second step is skipped
whether it's on or off.

### `AIN` and `Random` Waves

`AIN` and `Random` wave modes are treated like a sample-hand-hold of the incoming signal, with the
sample taken on the rising edge of a similarly-configured square wave.

For example, imagine `AIN` has a saw wave being sent into it.  For example, below we have a saw LFO
being sent into `AIN` with CV1 configured to read it.
```
AIN
      /|      /|      /|      /|      /|
    /  |    /  |    /  |    /  |    /  |
  /    |  /    |  /    |  /    |  /    |
/      |/      |/      |/      |/      |

CV1 clock x1, phase = 0
 ____      ____      ____      ____
|    |    |    |    |    |    |    |
|    |    |    |    |    |    |    |
|    |____|    |____|    |____|    |____

CV1 Output

      ____           ____
     |    |____     |    |____
_____|         |____|         |__________
```

### Turing Waves

`Turing` wave mode can operate in one of two sub-modes: `Gate` (default) or `CV`.

In `Gate` mode, it outputs simple of/off square waves.

Like the [original Turing Machine](https://github.com/TomWhitwell/TuringMachine) module, the `TLock`
parameter controls the likelihood that bits are randomly flipped when the register shifts.  When
`TLock` is _positive_, the output pattern is equal to the `TLength` parameter. When `TLock` is
_negative_ the output pattern is the initial `TLength` bits, followed by their compliment.  The
further from zero in either direction, the less likely it is that bits will be flipped during the
shift.

For example if `TLength` is 8 and the register contains `10101100`, and `TLock` is `+100` the gate
output will be `[1, 0, 1, 0, 1, 1, 0, 0]`.  If `TLock` is `-100` instead the gate output will be
`[1, 0, 1, 0, 1, 1, 0, 0, 0, 1, 0, 1, 0, 0, 1, 1]`.

In `CV` mode it outputs a pseudo-random control voltage,similar to the `Random` wave. The value of
the wave is determined by looking at the lowest 8 bits in the register (the register always contains
16 bits, regardless of `TLength`), treating them as a binary integer, and dividing that value by
256. The resulting value in the range `[0, 1)` is multiplied by the output amplitude to generate the
output voltage.
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

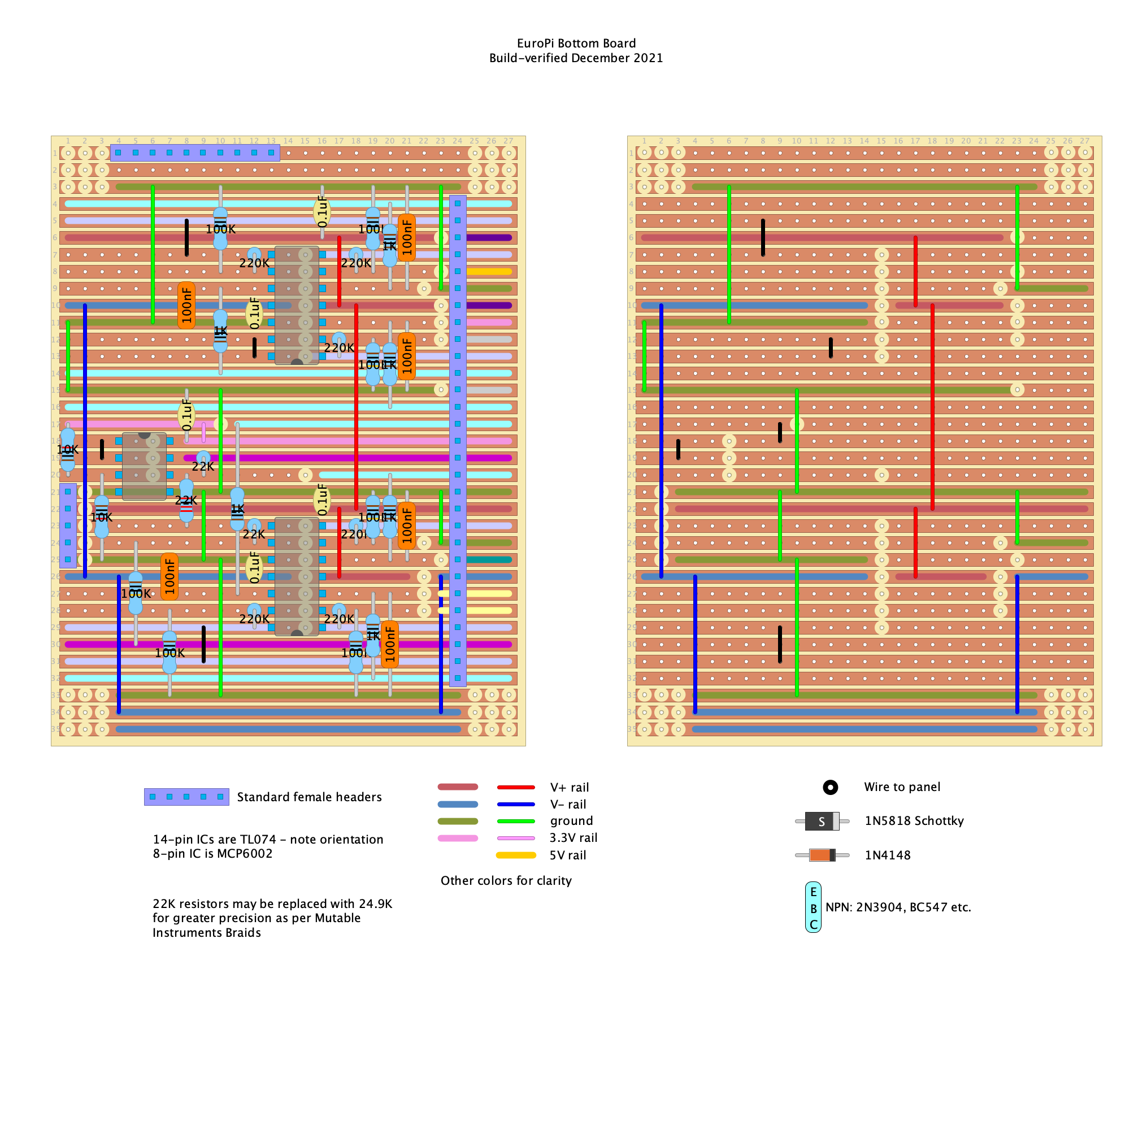
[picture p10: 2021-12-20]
hardware/stripboard/europi-stripboard-bottom-board.png

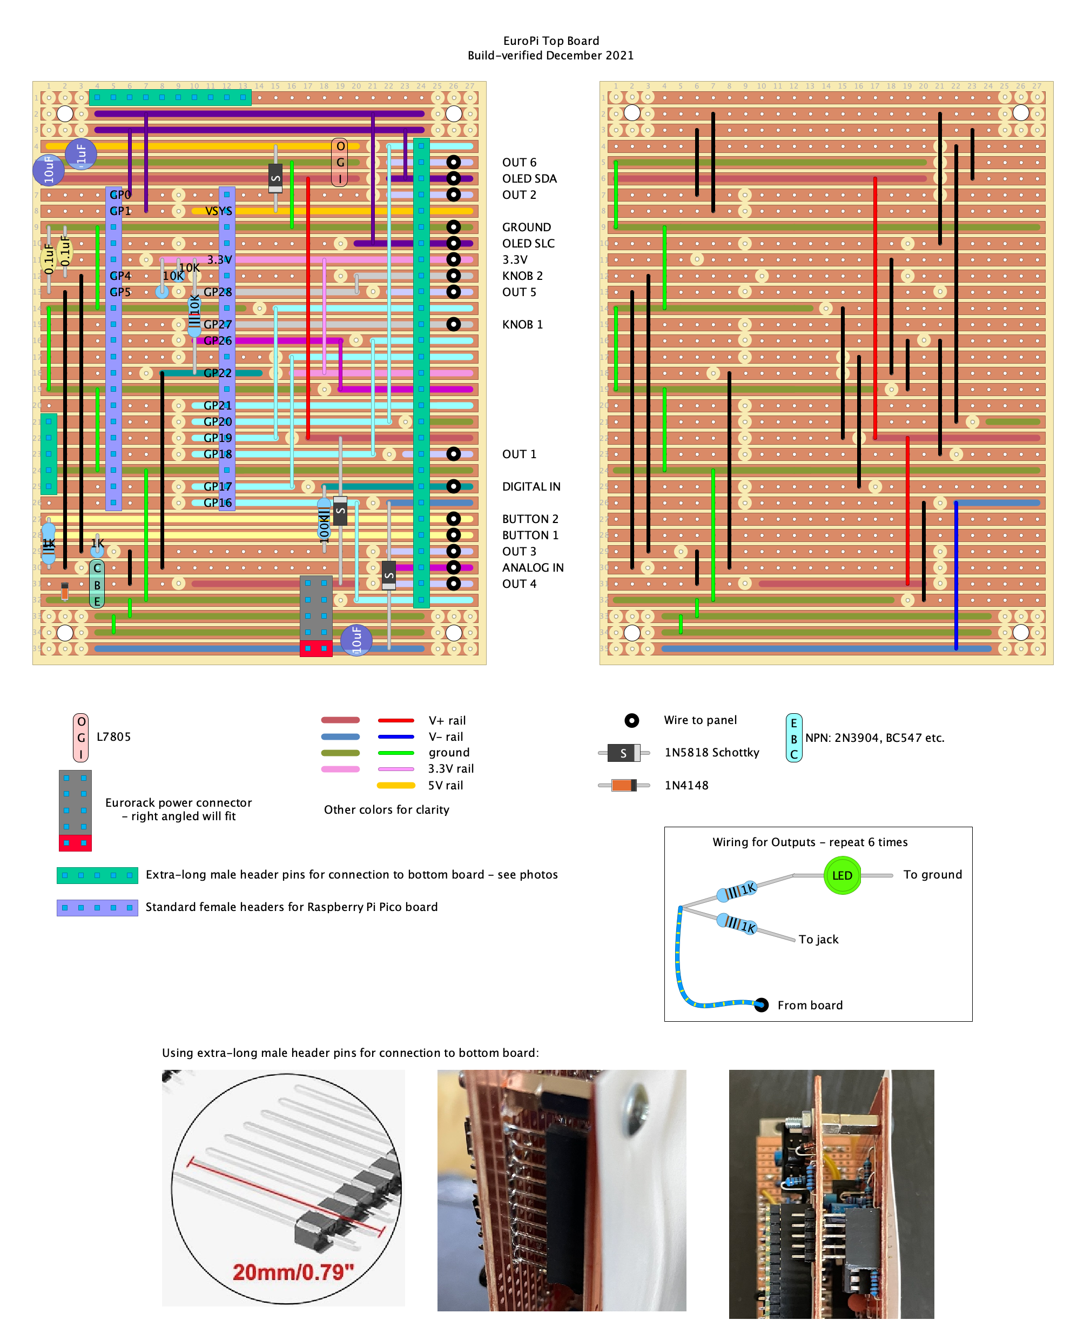
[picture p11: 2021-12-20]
hardware/stripboard/europi-stripboard-top-board.png

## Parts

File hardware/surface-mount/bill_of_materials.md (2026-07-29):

# Bill of Materials

In addition to the EuroPi-SMD PCB (bought from Allen Synthesis or a third-party supplier), you will need the following components to complete your build.
You will also need one 3.5mm cable (normal Eurorack patch cable) to perform the calibration process.

| Component | Quantity | Value | Description | Suggested Supplier |
|-|-|-|-|-|
| LED1 - LED6 | 6 | L-424HDT | 3mm LED | [CPC](https://cpc.farnell.com/kingbright/l-424hdt/led-flat-top-3mm-red/dp/SC11541)<br>[Mouser](https://www.mouser.co.uk/ProductDetail/Kingbright/WP424IDT?qs=58z0TXQGVSSLYuj%2FWm1qPQ%3D%3D) |
| VR1 - VR2 | 2 | 10k | 10 Kiloohm Linear Rotary Potentiometer | [CPC](https://cpc.farnell.com/alps/rk09k11310kb/potentiometer-10k-lin/dp/RE04560)<br>[Thonk](https://www.thonk.co.uk/shop/alpha-9mm-pots-vertical-t18/) (B10K - T18 Shaft - Alpha Vertical Potentiometer)<br>[Mouser](https://www.mouser.co.uk/ProductDetail/BI-Technologies-TT-Electronics/P0915N-QC15BR50K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)<br>**NOTE: Any resistance value between 5K and 100K will work for the potentiometers** |
| SW1 - SW2 | 2 | D6RXX F1 LFS | C&K Tactile Switch (Non-Illuminated) | [Thonk](https://www.thonk.co.uk/shop/radio-music-switch/)<br>[Mouser (Black)](https://www.mouser.co.uk/ProductDetail/CK/D6R90F1LFS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) |
| OLED1 | 1 | 0.91" SSD1306 | I2C OLED Display | [CPC](https://cpc.farnell.com/winstar/wea012832fwpp3n00000/oled-display-128x32-white-i2c/dp/SC15661)<br>**Note: The surface-mount build does not support 'The Pi Hut' style OLEDs, they WILL NOT WORK due to different pinouts.** |
| J1 - J8 | 8 | PJ398SM | Thonkiconn 3.5mm Mono Jack | [Thonk](https://www.thonk.co.uk/shop/thonkiconn/)<br>[Mouser](https://www.mouser.co.uk/ProductDetail/Adafruit/4031?qs=u16ybLDytRatVTT4ndlXOw%3D%3D)<br>[Banananuts](https://www.thonk.co.uk/shop/bananuts/)<br>[Cosmonuts](https://www.thonk.co.uk/shop/cosmonuts/) |
| CONN0 | 2 (pairs) | 20x1 2.54mm | Pico Connection Header (Male + Female) | CPC:<br>[Male](https://cpc.farnell.com/harwin/m22-2012005/header-vertical-1row-20way/dp/CN14644), [Female](https://cpc.farnell.com/multicomp/2212s-20sg-85/socket-pcb-1-row-20way/dp/CN14539)<br>Mouser:<br>[Male](https://www.mouser.co.uk/ProductDetail/Amphenol-FCI/10129378-920001BLF?qs=0lQeLiL1qyYln8p37ftVpg%3D%3D), [Female](https://www.mouser.co.uk/ProductDetail/Samtec/CES-120-02-T-S-RA?qs=0lQeLiL1qyZzf%2Fbgtv%2FkJg%3D%3D) |
|| 1 | JST-PH (4 Pin) | I2C Expansion Header (Optional) | [CPC](https://cpc.farnell.com/jst-japan-solderless-terminals/b4b-ph-k-s-lf-sn/header-top-entry-4way-2mm/dp/CN14075)<br> **Note: This is an optional JST-PH header that can be used to connect extra I2C peripherals such as sensors. Not soldering it will not affect function of the module other than you being unable to connect these.** |
|| 1 | JST-PH (6 Pin) | GPIO Expansion Header (Optional) | [CPC](https://cpc.farnell.com/jst-japan-solderless-terminals/b6b-ph-k-s-lf-sn/header-top-entry-6way/dp/CN14077)<br> **Note: This is an optional JST-PH header that breaks out the remaining GPIO pins of the Pico as well as providing 3.3V power so you can experiment with expansion boards or sensors. Not soldering it will not affect the function of the module.** |
| | 2 | T18 Shaft | Knobs | [Thonk](https://www.thonk.co.uk/shop/1900h-t18/)<br>**NOTE: If you buy D-Shaft potentiometers, the knobs must be 'Reverse-D-Shaft' type.<br>Any knobs which fit may be chosen, but Mouser does not stock the standard suggestion sold by Thonk** |
| | 1 | 10 - 16 Pin | Eurorack Power Cable | [Thonk](https://www.thonk.co.uk/shop/eurorack-power-cables/)<br>**Note: Mouser does not stock the correct cable at time of writing. Other suppliers will provide the correct part, but always double check that the polarity is correct (red stripe is always -12V)** |
| | 1 | | Micro USB Cable (Capable of Data Transfer) | [CPC](https://cpc.farnell.com/pro-signal/psg91562/lead-usb-a-male-micro-b-male-black/dp/CS32732), [The Pi Hut](https://thepihut.com/products/usb-to-micro-usb-cable-0-5m)<br>[Mouser](https://www.mouser.co.uk/ProductDetail/Teltonika/PR2US08M?qs=9vOqFld9vZXl90mLcdqZXQ%3D%3D) |
| | 1 | | Raspberry Pi Pico | [The Pi Hut](https://thepihut.com/products/raspberry-pi-pico)<br>[CPC](https://cpc.farnell.com/raspberry-pi/raspberry-pi-pico/raspberry-pi-pico-rp2040-mcu-board/dp/SC17106)<br>[Mouser](https://www.mouser.co.uk/ProductDetail/Raspberry-Pi/SC0915?qs=T%252BzbugeAwjgnLi4azxXVFA%3D%3D)<br>**Note: Any official version of the Raspberry Pi Pico will work (W, H, or WH). Third party RP2040 boards may work, but there is no guarantee - always double check the pinout** |

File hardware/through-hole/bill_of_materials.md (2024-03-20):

# Bill of Materials

In addition to the Front Panel, Jack PCB, and Pico PCB (bought from Allen Synthesis or a third-party supplier), you will need the following components to complete your build.
You will also need one 3.5mm cable (normal Eurorack patch cable) to perform the calibration process.

Please note that a few of these are multi-packs of components, and there may well be cheaper alternatives if you are doing a single build, so as long as the specification is the same you can get any of these components from any supplier most accessible to you.

You can either add each of these components to your basket using whichever suppliers you prefer, or alternatively use the complete [Mouser Shopping Basket](https://www.mouser.co.uk/ProjectManager/ProjectDetail.aspx?AccessID=b8e6a0d666) and then buy the few components that Mouser doesn't stock (Knobs, OLED, and Eurorack Power Cable) elsewhere.
If buying in bulk there are likely other suppliers that are cheaper - this BOM is compiled for DIY builders aiming to build 1-5 EuroPis at once.

| Component | Quantity | Value | Description | Suggested Supplier
|-|-|-|-|-|
| R1 - R12, R19 - R20 | 14 | 1k | 1 Kiloohm Resistor | [CPC](https://cpc.farnell.com/unbranded/mf25-1k/resistor-0-25w-1-1k/dp/RE03722)<br>[Mouser](https://www.mouser.co.uk/ProductDetail/YAGEO/MF0207FRE52-1K?qs=8uu3sA0mUdvCQE3OPmDzOQ%3D%3D)
|R13 - R18 | 6 | 4.7k | 4.7 Kiloohm Resistor | [CPC](https://cpc.farnell.com/unbranded/mf25-4k7/resistor-0-25w-1-4k7/dp/RE03757)<br>[Mouser](https://www.mouser.co.uk/ProductDetail/TE-Connectivity-Holsworthy/LR1F4K7?qs=ip69W3eHERXYYCvJ5kqIlw%3D%3D)
| R21 - R23 | 3 | 22k | 22 Kiloohm Resistor | [CPC](https://cpc.farnell.com/unbranded/mf25-22k/resistor-0-25w-1-22k/dp/RE03743)<br>[Mouser](https://www.mouser.co.uk/ProductDetail/YAGEO/MFR25SFTE26-20K?qs=xZ%2FP%252Ba9zWqbQbDvFESXcPA%3D%3D)
| R24 - R26 | 3 | 10k | 10 Kiloohm Resistor | [CPC](https://cpc.farnell.com/unbranded/mf25-10k/resistor-0-25w-1-10k/dp/RE03723)<br>[Mouser](https://www.mouser.co.uk/ProductDetail/YAGEO/MFR50SJT-52-10K?qs=xZ%2FP%252Ba9zWqZ4kQrxBn79Xw%3D%3D)
| R27 - R34 | 8 | 100k | 100 Kiloohm Resistor | [CPC](https://cpc.farnell.com/unbranded/mf25-100k/resistor-0-25w-1-100k/dp/RE03724)<br>[Mouser](https://www.mouser.co.uk/ProductDetail/YAGEO/MFR-25FRF52-100K?qs=5furm%2FeQHzRFPw%252B0Jam4HA%3D%3D)
| R35 - R40 | 6 | 220k | 220 Kiloohm Resistor | [CPC](https://cpc.farnell.com/unbranded/mf25-220k/resistor-0-25w-1-220k/dp/RE03744)<br>[Mouser](https://www.mouser.co.uk/ProductDetail/YAGEO/MFR-25FRF52-220K?qs=oAGoVhmvjhyfB1wbipURwA%3D%3D)
| C1 - C2 | 2 | 1uF | 1 Microfarad Capacitor (Polarised)| [CPC](https://cpc.farnell.com/multicomp/mcmhr50v105m4x7/capacitor-1uf-50v-radial-105-deg/dp/CA08237)<br>[Mouser](https://www.mouser.co.uk/ProductDetail/Wurth-Elektronik/860020672005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)
| C3 - C14 | 12 | 100nF | 100 Nanofarad Capacitor (Non-Polarised)| [CPC](https://cpc.farnell.com/multicomp/mcrr50104x7rk0050/capacitor-100nf-50v/dp/CA06296)<br>[Mouser](https://www.mouser.co.uk/ProductDetail/Vishay-BC-Components/K104K10X7RF53H5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)
| C15 - C16 | 2 | 10uF | 10 Microfarad Capacitor (Polarised)| [CPC](https://cpc.farnell.com/panasonic/eeueb1j100s/capacitor-10uf-63v-5x11mm/dp/CA08350)<br>[Mouser](https://www.mouser.co.uk/ProductDetail/Wurth-Elektronik/860010572002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)
| D1 - D4 | 4 | 1N5817 | Schottky Diode | [CPC](https://cpc.farnell.com/multicomp-pro/1n5817/schottky-rectifier-1a-20v-do-204al/dp/SC15528)<br>[Mouser](https://www.mouser.co.uk/ProductDetail/Diotec-Semiconductor/1N5817?qs=OlC7AqGiEDkUjhPY%2FT8RQg%3D%3D)
| LED1 - LED6 | 6 | L-424HDT | 3mm LED | [CPC](https://cpc.farnell.com/kingbright/l-424hdt/led-flat-top-3mm-red/dp/SC11541)<br>[Mouser](https://www.mouser.co.uk/ProductDetail/Kingbright/WP424IDT?qs=58z0TXQGVSSLYuj%2FWm1qPQ%3D%3D)
| VR1 - VR2 | 2 | 10k | 10 Kiloohm Linear Rotary Potentiometer | [CPC](https://cpc.farnell.com/alps/rk09k11310kb/potentiometer-10k-lin/dp/RE04560)<br>[Thonk](https://www.thonk.co.uk/shop/alpha-9mm-pots-vertical-t18/) (B10K - T18 Shaft - Alpha Vertical Potentiometer)<br>[Mouser](https://www.mouser.co.uk/ProductDetail/BI-Technologies-TT-Electronics/P0915N-QC15BR50K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)<br>**NOTE: Any resistance value between 5K and 100K will work for the potentiometers**
| SW1 - SW2 | 2 | D6RXX F1 LFS | C&K Tactile Switch (Non-Illuminated) | [Thonk](https://www.thonk.co.uk/shop/radio-music-switch/)<br>[Mouser (Black)](https://www.mouser.co.uk/ProductDetail/CK/D6R90F1LFS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)
| OLED1 | 1 | 0.91" SSD1306 | I2C OLED Display | [CPC](https://cpc.farnell.com/winstar/wea012832fwpp3n00000/oled-display-128x32-white-i2c/dp/SC15661)<br>[The Pi Hut](https://thepihut.com/products/0-91-oled-display-module)<br>**Note: Mouser does not stock the OLED required, and alternative suppliers to those listed may be too wide to fit in the module - always double check the datasheet and see the note below**
| J1 - J8 | 8 | PJ398SM | Thonkiconn 3.5mm Mono Jack | [Thonk](https://www.thonk.co.uk/shop/thonkiconn/)<br>[Mouser](https://www.mouser.co.uk/ProductDetail/Adafruit/4031?qs=u16ybLDytRatVTT4ndlXOw%3D%3D)<br>[Banananuts](https://www.thonk.co.uk/shop/bananuts/)<br>[Cosmonuts](https://www.thonk.co.uk/shop/cosmonuts/)
| CONN0 | 2 (pairs) | 20x1 2.54mm | Pico Connection Header (Male + Female) | CPC:<br>[Male](https://cpc.farnell.com/harwin/m22-2012005/header-vertical-1row-20way/dp/CN14644), [Female](https://cpc.farnell.com/multicomp/2212s-20sg-85/socket-pcb-1-row-20way/dp/CN14539)<br>Mouser:<br>[Male](https://www.mouser.co.uk/ProductDetail/Amphenol-FCI/10129378-920001BLF?qs=0lQeLiL1qyYln8p37ftVpg%3D%3D), [Female](https://www.mouser.co.uk/ProductDetail/Samtec/CES-120-02-T-S-RA?qs=0lQeLiL1qyZzf%2Fbgtv%2FkJg%3D%3D)
| CONN1 - CONN4 | 2 (pairs) | 4x2 2.54mm | PCB Connection Header (Male + Female) | CPC:<br>[Male](https://cpc.farnell.com/harwin/m20-9980445/header-2row-4way/dp/CN14381), [Female](https://cpc.farnell.com/multicomp/2214s-08sg-85/socket-pcb-2-54mm-2-row-vert-8way/dp/CN18449)<br>Mouser:<br>[Male](https://www.mouser.co.uk/ProductDetail/Amphenol-FCI/10129381-908002BLF?qs=DXv0QSHKF4wp0EFafi7%252BkA%3D%3D), [Female](https://www.mouser.co.uk/ProductDetail/TE-Connectivity/5-534206-4?qs=Eln3I3szM1ldJZZch%252BwNBQ%3D%3D)
| CONN5 | 1 | 4x1 2.54mm | I2C Header (Male) | [CPC](https://cpc.farnell.com/multicomp/2211s-04g/header-1-row-vert-4way/dp/CN14489)<br>[Mouser](https://www.mouser.co.uk/ProductDetail/Samtec/TMS-104-02-T-S?qs=0lQeLiL1qyYGrmA47bgfvw%3D%3D)
| CONN6 | 1 | 5x2 2.54mm | Eurorack Power Header (Shrouded) | [CPC](https://cpc.farnell.com/3m/n2510-6002rb/2-54mm-header-straight-10-way/dp/CN20355)<br>[Mouser](https://www.mouser.co.uk/ProductDetail/Amphenol-FCI/75869-101LF?qs=IfYaNh1cBzKYl6r7KisYeA%3D%3D)
| TL074-1 - TL074-2 | 2 | TL074 DIP | Quad Operational Amplifier (+ Socket) | CPC:<Br>[Op-Amp](https://cpc.farnell.com/texas-instruments/tl074acn/ic-op-amp-quad-jfet-dip14/dp/SC16602), [Socket](https://cpc.farnell.com/unbranded/mc-2227-14-03-f1/socket-ic-dil-0-3-tube-34-14way/dp/SC08125)<br>Mouser:<br>[Op-Amp](https://www.mouser.co.uk/ProductDetail/Texas-Instruments/TL074CNE4?qs=odmYgEirbwzZM%2F3R%2FF4zPw%3D%3D), [Socket](https://www.mouser.co.uk/ProductDetail/TE-Connectivity/1-2199298-3?qs=fK8dlpkaUMtBOtVI99wRlQ%3D%3D)
| MCP6002 | 1 | MCP6002 DIP | Dual Operational Amplifier (+ Socket) | CPC:<br>[Op-Amp](https://cpc.farnell.com/microchip/mcp6002-i-p/ic-op-amp-1-8v-1mhz-dual-pdip8/dp/SC17118), [Socket](https://cpc.farnell.com/multicomp/spc15494/dip-socket-8pos-2row-2-54mm-th/dp/SC15358)<br>Mouser:<br>[Op-Amp](https://www.mouser.co.uk/ProductDetail/Microchip-Technology/MCP6002-I-P?qs=Ux5rHyN1IXStLRM979v6Rg%3D%3D), [Socket](https://www.mouser.co.uk/ProductDetail/Mill-Max/110-41-308-41-001000?qs=dvxwXVM4mZVj1CY1TePuww%3D%3D)
| Q1 | 1 | 2N3904 | NPN Transistor | [CPC](https://cpc.farnell.com/multicomp-pro/2n3904/transistor-npn-to-92/dp/SC15978)<br>[Mouser](https://www.mouser.co.uk/ProductDetail/Diotec-Semiconductor/2N3904?qs=OlC7AqGiEDlYMySw5i2rlg%3D%3D)
| 7805 | 1 | L7805ABV | 5V Linear Voltage Regulator | [CPC](https://cpc.farnell.com/stmicroelectronics/l7805abv/ic-v-reg-5v/dp/SC10586)<br>[Mouser](https://www.mouser.co.uk/ProductDetail/Texas-Instruments/LM7805CT-NOPB?qs=OYMYEaN9QmBS2GvaX6GSkQ%3D%3D)
| | 1 | 11mm | M2.5 PCB Standoff + 2 Screws | CPC:<br>[Standoff](https://cpc.farnell.com/ettinger/05-02-113/spacer-hex-m2-5-11mm-length-brass/dp/PC01763), [Screws](https://cpc.farnell.com/unbranded/pp2m5-6/screw-pan-pozi-m2-5-x-6mm-100pk/dp/FN02140)<br>Mouser:<br>[Standoff](https://www.mouser.co.uk/ProductDetail/Wurth-Elektronik/970110151?qs=byeeYqUIh0MbOZEhnA3K1A%3D%3D), [Screws](https://www.mouser.co.uk/ProductDetail/Keystone-Electronics/29300?qs=H3YudI7YoxU32i5yvk535w%3D%3D)
| | 2 | T18 Shaft | Knobs | [Thonk](https://www.thonk.co.uk/shop/1900h-t18/)<br>**NOTE: If you buy D-Shaft potentiometers, the knobs must be 'Reverse-D-Shaft' type.<br>Any knobs which fit may be chosen, but Mouser does not stock the standard suggestion sold by Thonk**
| | 1 | 10 - 16 Pin | Eurorack Power Cable | [Thonk](https://www.thonk.co.uk/shop/eurorack-power-cables/)<br>**Note: Mouser does not stock the correct cable at time of writing. Other suppliers will provide the correct part, but always double check that the polarity is correct (red stripe is always -12V)**
| | 1 | | Micro USB Cable (Capable of Data Transfer) | [CPC](https://cpc.farnell.com/pro-signal/psg91562/lead-usb-a-male-micro-b-male-black/dp/CS32732), [The Pi Hut](https://thepihut.com/products/usb-to-micro-usb-cable-0-5m)<br>[Mouser](https://www.mouser.co.uk/ProductDetail/Teltonika/PR2US08M?qs=9vOqFld9vZXl90mLcdqZXQ%3D%3D)
| | 1 | | Raspberry Pi Pico | [The Pi Hut](https://thepihut.com/products/raspberry-pi-pico)<br>[CPC](https://cpc.farnell.com/raspberry-pi/raspberry-pi-pico/raspberry-pi-pico-rp2040-mcu-board/dp/SC17106)<br>[Mouser](https://www.mouser.co.uk/ProductDetail/Raspberry-Pi/SC0915?qs=T%252BzbugeAwjgnLi4azxXVFA%3D%3D)<br>**Note: Any official version of the Raspberry Pi Pico will work (W, H, or WH). Third party RP2040 boards may work, but there is no guarantee - always double check the pinout**

#### Note about OLED
The OLED has two suppliers listed, each with different pin configurations. The module supports either of these two configurations (the most common), but no others, so make sure that the one you buy, wherever you source it, has one of these two configurations.
It also *must* be 36mm or less. There are some displays which are 38mm wide, which will not only not fit within the width of the module, but will also leave the display off-centre in relation to the panel cutout. You can check the datasheet of any display before you buy to determine the width, but both of the displays listed in the BOM above are the correct 36mm.

OLED Pin Configurations
OLED Width

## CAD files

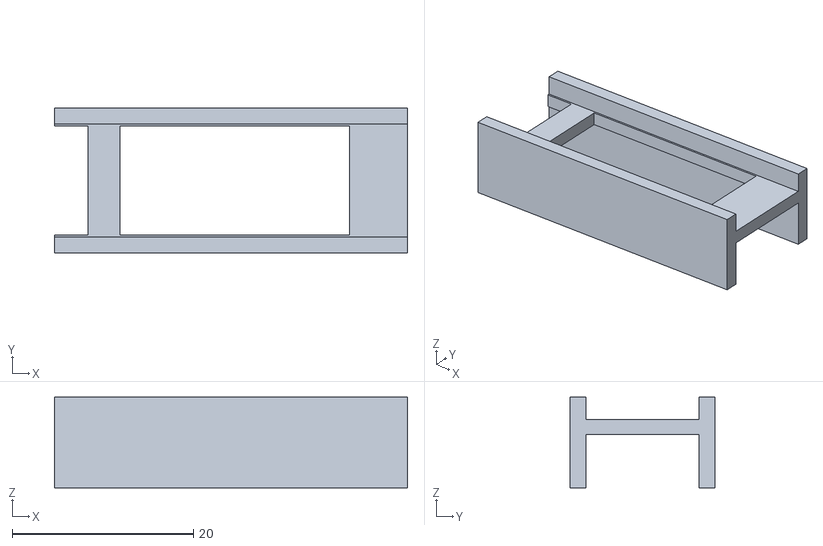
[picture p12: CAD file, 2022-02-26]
hardware/EuroPi/OLED_Stand/OLED_Stand.stl
39.0 x 16.0 x 10.0

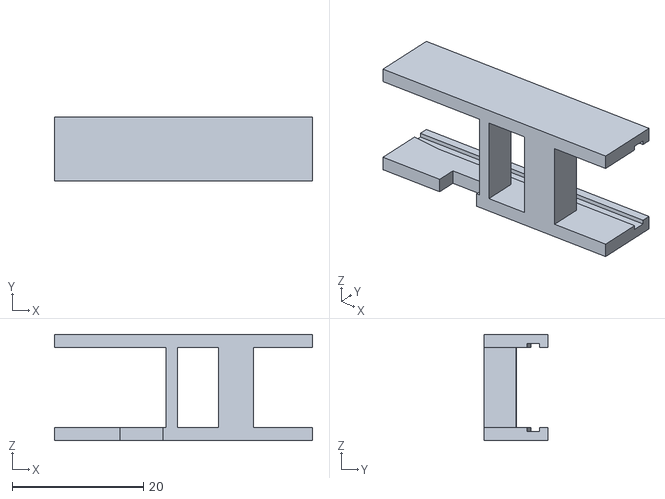
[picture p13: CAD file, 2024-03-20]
hardware/OLED_Stand/OLED_Stand_Pi_Hut.stl
39.3 x 9.80 x 16.1

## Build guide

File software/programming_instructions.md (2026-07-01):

# Setting up and programming the EuroPi

This document will take you through the steps to get your module ready to program.

> **Note**
> If you already have any version of the firmware or any other code loaded onto your EuroPi and want to ensure a clean installation, or you just want to make sure you have all the most recent scripts available, first follow these instructions:

1. Download [flash_nuke.uf2](https://learn.adafruit.com/getting-started-with-raspberry-pi-pico-circuitpython/circuitpython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) from Adafruit.

2. Holding down the white button labeled 'BOOTSEL' on the Raspberry Pi Pico, connect the module to your computer via the USB cable.
> **Note**
> If you are already running the menu system on the EuroPi (with a version greater or equal to X.X.X) and would rather not take the module out of your rack, you can instead run the script `_Bootloader Mode` while the module is connected to your computer over USB, and the module will enter bootloader mode

_DSC2400

3. Open your file manager and drag and drop the downloaded `flash_nuke.uf2` onto the new drive named 'RPI-RP2'. This will wipe your Pico clean, ready for a new installation of the firmware.

4. The Pico will automatically eject once the process is completed.

5. Continue to [Setting Up](#setting-up) as normal.

 ## Optional Quick start

> **Warning**
> This version of firmware will not let you override `main.py` nor can you modify existing scripts. Do not use this version of the firmware if you plan to write custom scripts for the EuroPi.

The quickest way to get your EuroPi flashed with the latest firmware is to head over to the [releases](https://github.com/Allen-Synthesis/EuroPi/releases) page and download the latest `europi-vX.Y.Z.uf2` file. Then follow the 'BOOTSEL' instructions above to flash the EuroPi firmware to your pico.

## Pico Setup

This section assumes you are using the Raspberry Pi Pico (or a compatible clone) featuring the RP2040 processor.  If you
are using a different model of Pico, e.g. the Pico W, or Pico 2, see [below](#alternative-picos).

### Downloading Thonny
To start with, you'll need to download the [Thonny IDE](https://thonny.org/). This is what you will use to program and debug the module.

Thonny

### Installing the firmware
1. Download the [most recent firmware](https://micropython.org/download/rp2-pico/) from the MicroPython website.
2. Holding down the white button labeled 'BOOTSEL' on the Raspberry Pi Pico, connect the module to your computer via the USB cable.

    _DSC2400

3. Open your file manager and drag and drop the downloaded .uf2 onto the new drive named 'RPI-RP2'.
4. The Pico will automatically eject once the process is completed.

### Installing the OLED library
1. Disconnect the Pico from the USB cable.
2. Reconnect, this time without holding down the button on the back.

    _DSC2401

3. Open up Thonny if not already open, and go to the bottom right where you can select the interpreter.
4. Click to select interpreter and choose 'MicroPython (Raspberry Pi Pico)'.

    Interpreter Select

5. **Important**: Wait until the Shell window at the bottom shows the MicroPython version and the purple ```>>>``` symbol.

    

6. Click Tools -> Manage Packages to open the package manager.
7. Type 'micropython-ssd1306' into the search box and click 'Search on PyPi'
8. Click the result named 'micropython-ssd1306'.

    ssd1306 library

9. Click 'Install'.
10. You will see that a folder has been created inside the Pico named 'lib', which contains the new file 'ssd1306.py'.

    ssd1306 inside lib

### Installing the EuroPi library

Use the exact same process as for the ssd1306 library to install the europi library:
1. Type 'micropython-europi' into the search box and click 'Search on PyPi'
2. Click the result named 'micropython-europi'.

    

3. Click 'Install'.
4. You will now see several new files, including 'europi.py' alongside the 'ssd1306.py' inside the 'lib' folder.

### (Optional) Installing the EuroPi Contrib library

The EuroPi Contrib library will make user-contributed software available on your EuroPi when using the [Menu](/software/contrib/menu.md) software. To install it, follow the same steps as the previous libraries on Thonny:

1. Type 'micropython-europi-contrib' into the search box and click 'Search on PyPi'
1. Click the result named 'micropython-europi-contrib'.

    Screenshot from 2023-07-14 03-02-02

1. Click 'Install'.
1. You will now see a `contrib` folder inside the `lib` folder which contains several software options with the extension `.py`.

## Alternative Picos

The Raspberry Pi Pico family has several different versions, all of which are mechanically and electronically interchangeable. This means
you can swap the Raspberry Pi Pico for the newer Pico 2 to take advantage of the RP2350 CPU's higher clock speed, or a Pico W/Pico 2 W
to add wi-fi connectivity to your EuroPi.

Each Pico model has its own MicroPython firmware:
- [Raspberry Pi Pico](https://micropython.org/download/RPI_PICO/) (the default for EuroPi)
- [Raspberry Pi Pico W](https://micropython.org/download/RPI_PICO_W/)
- [Raspberry Pi Pico 2](https://micropython.org/download/RPI_PICO2/)
- [Raspberry Pi Pico 2 W](https://micropython.org/download/RPI_PICO2_W/)
It is recommended to download the latest stable release for your Pico model.

Once the firmware is installed, continue installing the rest of the software:
1. [Installing the OLED library](#installing-the-oled-library)
2. [Installing the EuroPi library](#installing-the-oled-library)
3. [Installing the EuroPi Contrib library](#optional-installing-the-europi-contrib-library)

Once the software is installed, you will need to [configure the software](/software/CONFIGURATION.md#system) to finish setting up
the Pico.

## Next Steps

Now that you have installed the europi.py and ssd1306 libraries, you are ready to take the next step with the module.

* [Option 1](#install-the-contrib-scripts-and-setup-the-menu): Install all of the contrib scripts and use the bootloader menu
* [Option 2](#write-your-own-program-from-scratch): Start writing your own program from scratch
* [Option 3](#copy-someone-elses-program-to-run-on-your-module): Use someone else's program from the [contrib folder](/software/contrib/)
* [Option 4](#calibrate-the-module): Calibrate the module for higher accuracy

### Install the contrib scripts and setup the menu

The easiest way to start using EuroPi is to [install the `europi_contrib` library](#optional-installing-the-europi-contrib-library).
This will automatically create `lib/main.py` containing the following:

```python
import gc
from contrib.menu import *

gc.collect()
BootloaderMenu(EUROPI_SCRIPTS).main()
```

Copy this file from the `lib` directory into the root folder of the Pico using Thonny's file browser.
This file, when copied to the root folder, will automatically run a menu when EuroPi boots, allowing you to select a program from
the list to run.  After choosing a program, EuroPi will automatically restart that program next time it powers-on.  To return to
the menu, reset EuroPi by holding `B1` and `B2` for a few seconds.

If this is a brand new EuroPi, or you have just reinstalled the software, we recommend running
the [`~Calibrate`](#calibrate-the-module) program first. Calibrating is optional, but if you
plan on using EuroPi to produce [quantized](/software/contrib/quantizer.md) outputs it will
improve the accuracy.

#### Navigating the menu

To navigate the menu use the right knob. Turning clockwise will scroll down and turning anticlockwise will scroll up.

To run the selected program, press the either button once.  The last-run program will automatically start the next time you power-on your EuroPi.

To return to the main menu at any time, press and hold both buttons for 0.5s.

### Write your own program from scratch

To program the module, just create a new Python file, and then press Ctrl-Shift-S to save as to the Raspberry Pi Pico, and name it 'main.py'.
If you have [installed `europi_contrib`](#optional-installing-the-europi-contrib-library)
your module will already have the default `main.py` installed on it. If this is the case, you
may freely modify its contents. Note that if you reinstall or upgrade `europi_contrib` you will
lose any modifications you've made to `main.py`, so make sure to keep a backup.

Alternatively, you can create your program inside the `lib/contrib` directory, and add it to
`lib/contrib/menu.py` to launch it from the main menu.

#### Accessing EuroPi Hardware

For your program to make use of EuroPi's inputs and outputs add the line
`from europi import *` to the top of your program:

  From europi import

The `europi` module contains all of the objects and methods necessary for reading the six inputs
- `ain`, the analogue input jack;
- `din`, the digital input jack;
- `b1` and `b2`,  the two buttons; and
- `k1` and `k2`, the two knobs
and the six outputs: `cv1`-`cv6`.

Now you have access to the inputs and outputs using easy methods, which you can read about more in the [README.md](/software/README.md) of the software folder.

### Copy someone else's program to run on your module

1. Use the exact same process as for the ssd1306 and europi libraries to install the europi-contrib library:
   1. In Thonny, click Tools -> Manage Packages to open the package manager.
   2. Type 'europi' into the search box and click 'Search on PyPi'
   3. Click the result named 'micropython-europi-contrib'.
   4. Click 'Install'.
2. You will now see the new directory 'contrib' inside the 'lib' folder, containing the contrib scripts.
3. You can now choose any script from inside this contrib folder to run on your module. When you've chosen, double click the file on the Pico to open it.
4. Press 'Ctrl-Shift-S' to Save As, and choose 'Raspberry Pi Pico'

  
5. Name the file ``main.py``, being careful to include the '.py' so the module knows it is a Python file. If you do not name it ``main.py``, the module will not know to automatically run your program whenever it is connected to power. Save the file to the root directory of the Pico (not inside any folders)

  
6. Now you can disconnect the module from your computer, connect it to rack power, and the your chosen script will run automatically.

### Calibrate the module

To use the module for accurately reading and outputting voltages, you need to complete a calibration process. This will allow your specific module to account for any differences in components, such as resistor tolerances.
If you do not wish to calibrate the module and don't mind your voltages being slightly inaccurate, simply skip to the programming step and your module will use default values.

> **Note**
> If you have just installed the menu, simply run the calibration script and skip to step 2.

1. To begin, you need to choose the `calibrate.py` file and save it as `main.py` in the root directory, as we did in [Option 2](#copy-someone-elses-program-to-run-on-your-module) above. You can obtain the `calibrate.py` file from either the `lib/tools` directory on your Pico, or from [the firmware directory in the repository](/software/firmware/tools/calibrate.py).
2. Make sure your module is connected to rack power for the calibration process. It doesn't matter if it connected to USB as well, however if it is it will give an extra warning to turn on rack power which you need to skip using button 1.
3. Turn on the rack power supply, and the screen will display 'Calibration Mode'. If it doesn't, try [troubleshooting](../troubleshooting.md).
4. See [calibration](/software/firmware/tools/calibrate.md) for details on the calibration process.

# Programming Limitations

As with all hardware, the EuroPi has certain limitations. Some are more obvious and are required knowledge for any user, and some are more in depth and are only relevant if you will be programming the module yourself.

### Obvious Limitations
- Analogue input is only 0-10V
- Digital input can only detect signals above 0.7V (meaning it may trigger accidentally if you have a noisy 'low' state)
- Outputs, analogue input, and knobs, have a maximum resolution of 12 bits (4096 steps)
- Debouncing of the buttons means that very fast double presses may not be detected

### In Depth Limitations
- Clock pulses shorter than approximately 0.01s (10ms) will not be reliably detected (this depends on clock speed too)
- Reading any analogue source, either the analogue input or knobs, will result in a slight delay of the script (this can be reduced by using fewer samples, at the cost of accuracy)

## API Documentation

Auto-generated API documentation for Europi's core firmware and the user-created `experimental` libraries
can be found [here](https://allen-synthesis.github.io/EuroPi/).

# VS Code Configuration

If you use [VS Code](code.visualstudio.com) for development, you may find it helpful to create a `.vscode/settings.json` file in the root of the EuroPi repository. Copy the following into `.vscode/settings.json`:

```json
{
    "python.analysis.extraPaths": [
        "./software",
        "./software/firmware",
        "./software/tests/mocks"
    ]
}
```

This will allow the [Python extension](https://marketplace.visualstudio.com/items?itemName=ms-python.python) to properly detect the EuroPi modules and provide Intellisense completion & hints when using a native Python3 interpreter. Note that this will use the `mocks` module to provide definitions for built-in Micropython libraries that do not exist on standard Python3 installations. The code will not _run_ natively on your Windows/Mac/Linux development machine, but the VS Code IDE will at least provide appropriate code suggestions.

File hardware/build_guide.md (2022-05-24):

# Build Guide

#### Introduction
This document will go through the assembly of the EuroPi module.  
If you have bought only a Panel + PCB kit, you will need to also buy all of the components found in the [bill of materials](/hardware/bill_of_materials.md).  
  
This build is entirely through-hole (not even any pre-soldered SMD components!) so don't worry if you're fairly new to DIY, these instructions should be all you need to make your module.  
  
This guide should explain every step in enough detail, but there are some things left out for simplicity's sake, such as the fact that after each step any long legs will need to be snipped using your wire snips or scissors. This is only necessary for components with long legs, so resistors, capacitors, and LEDs. You don't need to snip anything off any of the headers, the 7805, the jacks, potentiometers, or IC sockets.  
 
#### Skiff Friendly Build 
There are two options for some of the build, one of which makes the module more skiff friendly (37mm deep as opposed to 45mm). If you wish to make the thinner version, simply click the links that say [Skiff Friendly Option](), and follow the instructions to guide you back into the normal build at the right points. Simply ignore these links if you don't mind the module being slightly deeper.

1 all
  
## Required tools
- Soldering Iron + Solder
- Wire Snips / Scissors
- Multimeter (Very nice to have but non-essential)

2 tools

## Preparation

#### If not already soldered, solder the headers to the Pico so that they are on the opposite side to the black integrated chips. It may help to push it into a breadboard to make sure the headers are straight
_DSC2386

## Pico PCB

The 'Pico PCB' is the PCB with the outline of the Pico on it.  
The 'front' of the Pico PCB is the side with the actual Raspberry Pi Pico on it, and the 'back' is the side with the transistor outline on it.

|Front|Back|
|-----|----|
|||

#### Required Components for Pico PCB
|Component|Quantity|
|---|---|
|1k Resistor|6|
|22k Resistor|3|
|100k Resistor|8|
|220k Resistor|6|
|10k Resistor|3|
|Schottky Diode|4|
|100nF Capacitor|10|
|14 Pin IC Socket|2|
|8 Pin IC Socket|1|
|NPN Transistor|1|
|1uF Capacitor|2|
|4x2 Female Header|2|
|Shrouded Power Header|1|
|4x1 Male Header|1|
|20x1 Female Pico Header|2|
|10uF Capacitor|2|

---

### Resistors

#### Solder the 1k resistors to the front (R1, R2, R3, R4, R5, R6)
_DSC2333
_DSC2335

#### Solder the 22k resistors to the front (R21, R22, R23)
_DSC2338

#### Solder the 100k resistors to the front (R28, R29, R30, R31, R32, R33, R34)
_DSC2339

#### Solder the 220k resistors to the front (R35, R36, R37, R38, R39, R40)
_DSC2340

#### Solder the 10k resistors to the back (R24, R25, R26)
_DSC2341

#### Solder the 100k resistor to the back (R27)
_DSC2342

---

### Diodes

#### Solder the Schottky diodes to the front (D2, D3, D4), taking care of the polarity
_DSC2343

#### Solder the Schottky diode to the back (D1), taking care of the polarity
_DSC2344

---

### Small Capacitors

#### Solder the 100nF capacitors to the front (C3, C4, C5, C6, C9, C10, C11, C12, C13, C14)
_DSC2345

---

### IC Sockets

#### Solder the 14 Pin IC sockets to the front (TL072-1, TL072-2), lining up the notch with the white square on the PCB
_DSC2346

#### Solder the 8 pin IC socket to the front (MCP6002), lining up the notch with the white square on the PCB
_DSC2347

---

### Transistor

#### Solder the NPN transistor to the back (Q1), lining up the flat edge with the line on the PCB
_DSC2348

---

### Medium Capacitors

#### Solder the 1uF capacitors to the front (C1, C2), taking care of the polarity. The white stripe on the capacitor lines up with the stripe on the PCB
_DSC2349

---

### Headers

#### Solder the female headers to the back
_DSC2350

#### Solder the shrouded power header to the front
_DSC2351

#### Solder the I²C header to the front
_DSC2352

[Skiff Friendly Option](skiff_friendly_instructions.md#step-1)

#### Push the female Pico headers onto the Pico itself
_DSC2355

#### Press this new assembly onto the footprint on the PCB
_DSC2356

#### Solder the female headers from the back
_DSC2357

#### Remove the Pico from the female headers
_DSC2358
_DSC2359

---

### Large Capacitors

#### Solder the 10uF capacitors to the front (C15, C16), taking care of the polarity. The white stripe on the capacitor lines up with the stripe on the PCB
_DSC2360

---

### 7805

[Skiff Friendly Option](skiff_friendly_instructions.md#step-2)

#### Solder the 7805 power regulator to the front, with the metal side in line with the white stripe on the PCB
  
_DSC2361

---

## Jack PCB

The 'Jack PCB' is the remaining board, with the outlines for the front panel components.  
The 'front' of the Jack PCB is the side with the OLED, jack, and button outlines, and the 'back' is the side with the OLED configuration diagram.

|Front|Back|
|-----|----|
|||

---

### Resistors

#### Solder the 1k resistors to the back (R7, R8, R9, R10, R11, R12, R19, R20)
_DSC2362 5

---

#### Solder the 4.7k resistors to the back (R13, R14, R15, R16, R17, R18)
_DSC2362

---

### Small Capacitors

#### Solder the 100nF capacitors to the back (C7, C8). If your board has a polarity marking, ignore it unless you are deliberately using larger polarised capacitors than the BOM calls for, in which case make sure they line up with the PCB marking
_DSC2363

---

### Headers

#### Push the male headers into the female headers that you soldered to the Pico PCB
_DSC2364

#### Push the Jack PCB onto the other side of the male headers
_DSC2365

#### Solder the male headers to the Jack PCB
_DSC2366

#### Pull the two PCBs apart carefully to reveal the perfectly aligned male headers on the Jack PCB
_DSC2367

---

#### OLED Configuration
There are two pin configurations that the OLED used in this build commonly comes in, which are labelled on the board 'TPH' (The Pi Hut), and 'CPC' (CPC, AliExpress, most other suppliers).  
The Pi Hut display is preferable as it does not have pre-soldered headers, so is easier to mount on the board. However the CPC display is still entirely usable.  
  
This configuration setup allows you to tell the module which display you are using, as their pins are ordered differently:  
TPH: VCC, GND, SDA, SCL  
CPC: SDA, SCL, VCC, GND
  
Don't ask my why there is still not a standard for I²C pin layout in the year 2021, but here we are, and here is how to tell the module which layout you are using:
  
#### Snip some resistor legs and bend them over the end of something small and round, such as needle-nose pliers
_DSC2410

#### Push the snipped legs into the holes on the PCB according to the diagram and which OLED you have, and then solder either from the top or the bottom
_DSC2411

---

### Front Panel Components

#### Solder the push buttons to the front (SW1, SW2)
_DSC2370

#### Solder the OLED Display to the front
This is quite an awkward operation as the distance the headers need to occupy is not standard to the lengths that 2.54mm headers come in. If you are using a CPC display, your headers are probably pre-soldered, in which case you need to prop the display up somehow while you solder one pin, then go on to solder the rest once you're sure it's straight.
  
If your display is CPC, the pins will be flush with the PCB if it's at the correct height, which is difficult but possible to solder.  
  
If your display is TPH, you can either solder pins and do it the same way as the CPC method, or use extra-long pin headers instead which will make the soldering process easier, as they will protrude far enough to get a better solder joint.

_DSC2375

#### Place the potentiometers (VR1, VR2) onto the front but don't solder yet
_DSC2376

#### Place the jacks (J1, J2, J3, J4, J5, J6, J7, J8) onto the front but don't solder yet
_DSC2377

#### Place the LEDs (LED1, LED2, LED3, LED4, LED5, LED6) onto the front but don't solder yet, lining up the short leg with the white stripe on the PCB
_DSC2378

#### Push the front panel onto the components, lining up the LEDs so they are flush
_DSC2379

#### Place an elastic band or hair bobble around the PCB and panel to hold them together. I used the plastic coated wire that came with my USB cable
_DSC2380

#### Solder all the components from the back. For the potentiometers, only solder the large lugs on the sides if yours are trimmer type potentiometers. Do not solder the lugs if the potentiometers came with nuts.
_DSC2381

---

## Finish off the assembly

#### Screw the PCB standoff onto the Jack PCB so that the standoff is on the back and the screw on the front
_DSC2383

#### Push the two PCBs together, keeping them both straight to avoid bending the header pins
_DSC2384

#### Screw the second screw into the PCB standoff through front of the Pico PCB to hold the two PCBs together firmly
Don't over-tighten so hard that you damage the PCB, but you also don't want this to rattle loose so make sure it is secure.
_DSC2385

#### Push the Pico into its slot on the Pico PCB
_DSC2387

#### If not done already, peel the protective film off the OLED display
_DSC2389

#### Screw all of the nuts on to hold the components to the front panel. 
If your potentiometer came with nuts, use them, otherwise just screw on the jacks.
Also pop on the knobs.
_DSC2390

#### Finally, pop the TL074 and MCP6002 Op-Amps into their respective sockets, making sure the notch in the IC matches the notch on the socket
_DSC2391

---

### (Optional) Multimeter Tests
Use your multimeter set to continuity mode for these tests.

#### Check that there is no continuity between +12V and -12V, between +12V and Ground, and between -12V and Ground on the power header
_DSC2395

If there is continuity on any checks where there shouldn't be then make sure your solder joints are good and that there is no dirt or stray solder bridging any connections. Also make sure that your diodes and power cable are all the correct orientation.

---

### Smoke Test

#### Connect your module to your Eurorack power supply without any other modules connected
_DSC2396

Make sure the cable is connected so that the 'key' on the cable slots into the notch on the header, and the red stripe is on the bottom side of the module.
Turn on your power supply and check for any smoke or discolouration of the PCB around the power connector, and immediately unplug if either occur.  
If all is groovy, the congratulations, you've finished building your EuroPi!

---

## Admire your handiwork!

_DSC2397

#### If you have any issues with the build process or programming that are not covered in the [troubleshooting guide](/troubleshooting.md) then please drop us an email at [contact@allensynthesis.co.uk](mailto:contact@allensynthesis.com)

#### Share photos of your build with us on [Instagram](https://www.instagram.com/allensynthesis/), or [email us](mailto:contact@allensynthesis.com)!

#### Now just follow the [programming instructions](/software/programming_instructions.md) to get ready to use your new EuroPi!

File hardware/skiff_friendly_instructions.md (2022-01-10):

# Skiff-Friendly Build Instructions

If you have opened this file without being directed here from the normal build guide, you are probably in the wrong place. Follow the normal build guide from the beginning and only access these instructions by clicking the links that say [Skiff Friendly Option]().

### Step 1

1. Instead of soldering female headers as per the normal build, push the Pico onto the board using its male headers only
2. Solder the Pico from the back
3. [Now go back to the normal build](https://github.com/Allen-Synthesis/EuroPi/blob/main/hardware/build_guide.md#large-capacitors)

### Step 2

1. Bend the 7805's legs 90 degrees using a pair of pliers. Look at the photos below to see where to bend them and in which direction
2. Push the 7805 into the PCB footprint and solder
3. You may need to put a piece of tape between the 7805 and the Pico to prevent the metal back of the 7805 from touching the pins or USB port of the Pico
4. [Now go back to the normal build](https://github.com/Allen-Synthesis/EuroPi/blob/main/hardware/build_guide.md#jack-pcb)
  
_DSC2402
_DSC2403

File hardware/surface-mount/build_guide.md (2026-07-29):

# EuroPi (surface-mount) Build guide
If you want to build this version of the EuroPi, you can buy the PCB directly from [Allen Synthesis](https://allensynthesis.square.site/product/europi-panel-pcb/16?cp=true&sa=true&sbp=false&q=false), and the remaining parts from the sources listed in the [bill of materials](/hardware/surface-mount/bill_of_materials.md)
1. Press fit the Thonkiconn audio jacks (x8), 9mm Potentiometers (x2), Buttons (x2), and LEDs (x6) to the PCB, but don't solder anything yet.

    
1. Put the panel on and just use an elastic band to hold it in place, making sure all the components fit through their cutouts properly.

    
1. Solder the jacks and potentiometers from the back, making sure they're properly aligned with the panel and not at a funny angle.
1. Now solder the buttons, taking care to make sure they're pushed against the PCB while doing so - they might try to fall out so it can help to just solder one pin first and keep the solder hot with your iron while you position it, and only solder the other 3 pins once you're happy.
1. To solder the LEDs, use the one pin trick again: solder just one pin of each LED and then push the LED flush with the panel with one hand while using the other to hold the soldering iron, keeping that pins solder molten.
1. Finally solder the remaining pins of each LED (and the buttons if you only soldered one pin of each of those)

    
1. Snip off the long LED legs using wire snips or the cutting part of a pair of pliers.
1. Solder the male headers (x2) onto the Raspberry Pi Pico (skip this step if you're using a Pico H which has them pre-soldered). I find that a breadboard is a useful tool to make sure the pins are completely straight.

    
1. Push the female headers (x2) onto the male headers, and then push both onto the back of the PCB.

    
1. Turn the PCB over and solder all of the Pico pins on both sides, making sure the Pico stays straight. Again it can help to just solder one pin at each end of each header, make sure its straight and re-heat the solder if necessary, and then continue soldering all the other pins only once you're happy.

    
1. Now it's time to solder the OLED, which is easily the most difficult part of this build. You need to apply a small amount of solder to each of the pins while holding the OLED in place with your other hand, so it can help to use some kind of desk clamp. Run the soldering iron over each of the 4 pins quickly enough that the solder on all of them stays molten, and use your other hand to make sure the display is straight while the solder cools. The pins should only just be flush with the back of the PCB, so I find it easier to solder from the top (but make sure none of the pins are bridged together).

    
1. Solder the Eurorack power header, (optional) I2C header, and (optional) GPIO expansion headers by fitting them and turning the board over to solder from the other side. Note: If these photos don't match your module, you likely have an older revision which does not have the GPIO expansion header and only requires a 1x4 2.54mm male header for the I2C port. The module will work identically but doesn't require the extra JST-PH headers.

    EuroPi-Back
1. Follow the [programming instructions](/software/programming_instructions.md) to set the module up for however you want to use it, calibrate it if you want higher accuracy, and have fun!



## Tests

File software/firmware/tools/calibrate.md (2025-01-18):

# Calibration

Input & output calibration too for EuroPi.

## Required Equipment

Calibration requires the following physical setup:
1. EuroPi _must_ be connected to rack power
2. For low-accuracy calibration you need either another EuroRack module or an external voltage source capable of
   generating precise voltages of either 5V or 10V
3. For high-accuracy calibration you need another EuroRack module or adjustable external voltage source capable of
   generating precise voltages of 1.0, 2.0, 3.0, ..., 9.0, 10.0V.

## Usage

Calibration is interactive with instructions displayed on-screen. These instructions are summarized below:
1. Make sure the module is powered from your Eurorack power supply.
2. Select input calibration mode by turning `K2`. Press `B2` when ready
    a. low-accuracy with 10V input
    b. low-accuracy with 5V input
    c. high-accuracy with variable 0-10V input
3. Disconnect all patch cables from the module. Press `B1`
4. Connect your voltage source to `AIN`. Press `B1` when instructed.
    a. low-accuracy with 10V input: connect 10V to `AIN`
    b. low-accuracy with 5V input: connect 5V to `AIN`
    c. high-accuracy: read the on-screen instructions and connect the specified voltages when required.
5. Connect `CV1` directly to `AIN`. Press `B1`. Wait for the module to perform the output calibration.
6. Repeat step 5 for `CV2`, `CV3`, etc... until all CV outputs are calibrated
7. Reboot the module when prompted. The new calibration will be applied automatically.

Calibration data is saved to `/lib/calibration_values.py`. DO NOT delete this file; if you delete it you will have to
complete the calibration again.

After calibrating and rebooting the module it is recommended to run the `Diagnostic` program to verify that the
inputs and outputs have been properly calibrated.

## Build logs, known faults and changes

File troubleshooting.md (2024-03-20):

# Troubleshooting the EuroPi module

This document should help you fix any problems you might be having with the hardware or software of the module.
If you have any other issues that aren't covered in this document, please create an Issue on this GitHub repository using the template.
You can search through this file for the error message you are getting or just press Ctrl-F and paste the first line of the message given in Thonny.

## No inputs or outputs are working

#### Steps to fix
1. Make sure your module is connected to both USB for programming and rack power for ±12V supply
2. Make sure the Pico and Jack PCBs are firmly pressed together, and held by the standoff

## Couldn't find the device automatically

```diff
- Couldn't find the device automatically.
- Check the connection (making sure the device is not in bootloader mode) or choose
- "Configure interpreter" in the interpreter menu (bottom-right corner of the window)
- to select specific port or another interpreter.
```

This means that your device is either not connected, or not being detected.
#### Steps to fix
1. Make sure the USB cable is connected firmly to both the Pico and your computer
2. Make sure your USB cable is capable of data transfer rather than just power
3. Re-flash the firmware by following the process set out in the [programming instructions](/software/programming_instructions.md)
4. Re-flash the firmware using the 'flash_nuke.uf2' found on the [Adafruit website](https://learn.adafruit.com/getting-started-with-raspberry-pi-pico-circuitpython/circuitpython), and then re-flash it again using the most recent firmware

## Calibration gets stuck on 10V

This means that the value the module recorded for 10V when you were sending in voltages to the analogue input cannot be reached by the CV output.
This could mean either:
1. The value you sent in for 10V was more than 10V
2. The module actually cannot reach 10V

To test if it is 1 or 2, first retry calibration, making sure the voltages you send in are accurate (never more than 10V). Measure this with a multimeter if you can to be sure.

If this doesn't fix the issue, then you know that your module cannot reach 10V on its own. There are a few things this could be:
1. The LEDs you used draw more current than the standard ones in the BOM, and are thus causing the output voltage to drop below 10V
2. There is a bridge/missing solder joint which is causing the output stage to have a lower gain factor than it should, and thus can't reach 10V
3. (Very unlikely) The output jack is broken and is not connected to the circuit properly

The easiest way to test a few of these possibilities at once is to set the output to the highest value possible, with this code:
```
from europi import *
cv1._set_duty(65535)
```
Simply create a new file with only this code in it, and then run the code with the module connected.
Now, use a multimeter to measure the voltage at the end of a mono cable plugged into the jack, and see if it is above 10V. As long as it is over 10V, even if only by about 0.5V, then this proves that the problem is not any of the above. If this is the case (the voltage is above 10V) then reflash the firmware using the instructions at the bottom of [the steps to fix above](#steps-to-fix-1).

If it was less than 10V, then check all of the solder joints on both PCBs, but especially all of the ones around the TL074 op-amps. If you see any joint that looks like it could be either bridging two pins or cracked, then clean up the joint with some solder braid or a solder sucker (a braid is preferred as it's less likely to damage the board) and re-solder.

If none of this solves the issue, then please post in the support channel of the [Discord server](https://discord.gg/JaQwtCnBV5) with photos of your PCBs, and we can see if we can spot anything!

## EuroPi Hardware Error

```diff
- EuroPi Hardware Error:
- Make sure the OLED display is connected correctly
```

This means that the Pico cannot detect the OLED display.
#### Steps to fix
1. Make sure that the solder joints between the OLED board and the PCB are secure and free of dirt
2. If you have a multimeter, test the continuity of each pin with the appropriate pin on the Pico according to [the pinout](hardware/EuroPi/europi_pinout.pdf)
3. Make sure your PCB standoffs are screwed on tightly; if the two board slip apart by any more than a millimetre or two then the connection will not be made
4. Make sure your OLED matches one of the two compatible pin configurations as outlined in the [build guide](hardware/EuroPi/build_guide.md#oled-configuration)

## Backend terminated or disconnected

```diff
- Backend terminated or disconnected. Use 'Stop/Restart' to restart.
```

The module has become disconnected from your computer.
#### Steps to fix
1. Try pressing Stop/Restart
2. Follow the steps to fix for 'EuroPi Hardware Error'

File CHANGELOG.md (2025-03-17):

# Change Log

### 2022-08-28

- [Release] version 0.6.1
- [Bug Fix] Add new `experimental` package to firmware setup.py (https://github.com/Allen-Synthesis/EuroPi/issues/164)

### 2022-08-28

- [Release] version 0.6.0
- [New Script] Turing Machine  (https://github.com/Allen-Synthesis/EuroPi/pull/114)
- [New Script] Smooth random voltages  (https://github.com/Allen-Synthesis/EuroPi/pull/153)
- [New Script] Probapoly - polyrhythmic gate patterns  (https://github.com/Allen-Synthesis/EuroPi/pull/161)
- [Bug Fix] Consequencer - Added probability-based steps in patterns  (https://github.com/Allen-Synthesis/EuroPi/pull/158)
- [Bug Fix] Consequencer - Increased reset_timeout to allow for slower BPMs  (https://github.com/Allen-Synthesis/EuroPi/pull/158)
- [Bug Fix] Strange Attractor - init save state  (https://github.com/Allen-Synthesis/EuroPi/pull/157)
- [Bug Fix] CVecorder - Updated loading screen to show progress to avoid a perception of a hang during load  (https://github.com/Allen-Synthesis/EuroPi/pull/161)
- [Bug Fix] CVecorder - Reduced number of save-state loading retries for faster loading  (https://github.com/Allen-Synthesis/EuroPi/pull/161)
- [Bug Fix] CVecorder - Fixed bug that caused recordings to be buggy if no save state file was found  (https://github.com/Allen-Synthesis/EuroPi/pull/161)
- [API] New experimental package added including `LockableKnob` and `KnobBank`  (https://github.com/Allen-Synthesis/EuroPi/pull/155)
- [Other] Add .vscode to gitignore to ignore user IDE settings

### 2022-05-24

- [Release] version 0.5.0
- [New Script] PolySquare 6 oscillator contrib script https://github.com/Allen-Synthesis/EuroPi/pull/141
- [Bug Fix] Updated display to show pattern number, decrease loading times #146
- [Bug Fix] Cvecorder bank clear remediation #139,
- [Documentation] Contributing updates #138, #125
- [Documentation] Update hamlet.md to align gate/CV ports with code #135
- [Other] Add a new test fixture called MockHardware #137
- [Other] Add missing test mocks #143

### 2022-04-28

- [Release] version 0.4.0
- [New Script] Hamlet, mod to Consequencer adding two voice tracks #129
- [New Script] Bernoulli gates, dual Bernoulli gates #104
- [New Script] CVecorder, record cv sequences #121
- [Bug Fix] coin_toss triggering on falling slope instead of rise #117
- [Bug Fix] remove for loop that was calling _set_duty() multiple times #126
- [Bug Fix] Poly-rhythmic Seq sequence reset #130
- [Other] add a test for menu's imports #120
- [Other] Harmonic LFOs updates #127, #128

### 2022-04-13

- Consequencer: Moved self.reset_timeout = 500 to a better place
- Consequencer: Reduced latency by removing the if self.clock_step < 128 check
- Consequencer: You can now add patterns longer than 32 steps without breaking anything 🙂
- Consequencer: Added new patterns inspired by African beats and one based on the Fibonacci sequence
- Consequencer: Added a feature to send a clock out of output 4 which is always in time with the Consequencer. I found this useful to combat the latency between the clock sent to the Consequencer and the gates that come out. With self.output4isClock set to True you can clock all your other modules using output 4 and they will be in-sync with the Consequencer
- Consequencer: Added explanation of self.output4isClock to doc
- Consequencer: Added UI access to self.output4isClock (long-press of button 1)
- CVecorder: Added

### 2022-04-04

- release version 0.3.0
- add save/load script state behavior via EuroPiScript
- add Strange Attractor chaotic modulation script
- add Noddy Holder sample/track and hold script

### 2022-03-16

- release version 0.2.0

### 2022-03-16

- add bootloader menu allowing the user to choose a script to run
- update all existing scripts to work with the menu
- add new firmware module 'europi_script' containing a base class to support menu inclusion
- add new firmware module 'ui' as a place to hold reusable UI components

### 2022-03-10

- release version 0.1.0

### 2022-02-18

- update diagnostic script to add temperature display and CV output rotation.

### 2022-02-15

- add Consequencer script

### 2022-02-04

- Add support for automated testing
- Add scope script

### 2022-02-01

- added `europi.DigitalReader.handler_falling()` To define a callback function to call when a falling edge is detected

### 2021-10-15 - 2022-02-02

- initial development of EuroPi library and documentation, including the following scripts:
  - calibrate
  - coin_toss
  - diagnostic
  - harmonic_lfos
  - polyrhythmic_sequencer
  - radio_scanner

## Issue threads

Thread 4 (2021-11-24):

[Project Suggestion] Improve oled initialization

awonak, 2021-11-24:
# Project Suggestion

Improve "[OSError: [Errno 5] EIO](https://github.com/Allen-Synthesis/EuroPi/blob/main/troubleshooting.md#oserror-errno-5-eio
)" error handling with more user friendly message.

**Describe your suggestion or idea**

The troubleshooting guide provides helpful tips for handling "[OSError: [Errno 5] EIO](https://github.com/Allen-Synthesis/EuroPi/blob/main/troubleshooting.md#oserror-errno-5-eio
)". This error message can be improved by checking the I2C ready state before allowing the exception to be thrown.

In [europi.py](https://github.com/Allen-Synthesis/EuroPi/blob/main/software/firmware/europi.py#L11-L13) lines 11-13, the oled I2C device is registered and immediately used. In the MicroPython documentation, the I2C class offers a "[scan](https://docs.micropython.org/en/latest/library/machine.I2C.html#machine.I2C.scan)" method which allows you to scan for peripheral deices on the given bus. If no devices are found, you can gracefully report that error to the user instead of allowing the unintuitive "OSError: EIO" error to be thrown.

An example implementation would look like this:

```python
oled_bus = I2C(0, sda=Pin(0), scl=Pin(1), freq=400000)
if len(oled_bus.scan()) == 0:
    raise SystemError("No I2C devices found. Ensure OLED device properly installed.")

oled = SSD1306_I2C(WIDTH, HEIGHT, oled_bus)
oled.fill(0)
oled.show()
```

**Images**
If applicable, add screenshots or photos to help explain your problem.

roryjamesallen, 2021-11-26:
Excellent suggestion. MicroPython does not seem to support SystemError without extra packages being installed, so an alternative method of displaying error messages is needed.
I have used simple red text to indicate the error and then exited the program. It's not ideal but it does also work when the library is imported, showing the correct error message in whichever is the currently running program.
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

awonak, 2021-11-26:
+1 to not adding additional imports. This looks like a great solution to me.

Closed 2021-11-28.

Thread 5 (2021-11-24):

[Project Suggestion] Simplify OLED display extra funtions

awonak, 2021-11-24:
# Project Suggestion

Instead of having separate functions to add custom behavior to the OLED instance variable, you can subclass the SSD1306_I2C library and add your custom functions there.

**Describe your suggestion or idea**

For example:
```python
class EuroPiDisplay(SSD1306_I2C):
    def __init__(self, sda, sc, channel=0, freq=FREQ):
        i2c = I2C(channel, sda=Pin(sda), scl=Pin(scl), freq=freq)
        if len(i2c.scan()) == 0:
            raise SystemError("No I2C devices found. Ensure OLED device properly installed.")

        # super() calls the init method on the SSD1306_I2C base class
        super().__init__(WIDTH, HEIGHT, i2c)

    def centre_text(self, text):
        """Takes a string of up to 3 lines separated by '\n', and displays them centred vertically and horizontally."""
        ...
        self.text(...)

    def clear(self):
        self.fill(0)

# Sample usage:
oled = EuroPiDisplay(SDA_PIN, SCL_PIN)
oled.clear()
oled.show()
# default SSD1306_I2C method
oled.text("default text")
# custom method
oled.centre_text("centred text")
```

This will give users a consistent interface for working with the OLED display. Custom functions should still be documented as such in the [OLED Tips page](https://github.com/Allen-Synthesis/EuroPi/blob/main/software/oled_tips.md#extra-functions-from-europipy), but this will give users a consistent interface when coding up their scripts. This also helps avoid the function `centre_text` from relying on the globally defined `oled` variable.

**Images**
If applicable, add screenshots or photos to help explain your problem.

roryjamesallen, 2021-11-26:
Including the error message approach from [Issue 4](https://github.com/Allen-Synthesis/EuroPi/issues/4), the extra OLED functions are now accessed as methods, using a subclass named 'oled_display'.
This should also make it much easier for users to add their own custom OLED methods.

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

awonak, 2021-11-26:
One minor tweak to that change on [europi.py line #62](https://github.com/Allen-Synthesis/EuroPi/blob/main/software/firmware/europi.py#L62), instead of `oled.text(...)` that should be `self.text(...)` just like you've done with self.clear() because self is the `oled_display` class instance and we no longer need to rely on the global variable.

roryjamesallen, 2021-11-28:
Fixed to use self.text() rather than oled.text(). A custom error message has now also been added for the even that a non-string is sent to the method

Closed 2021-11-28.

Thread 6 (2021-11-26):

[Project Suggestion] Add support for alternative OLED pin configurations

roryjamesallen, 2021-11-26:
# Project Suggestion

**Describe your suggestion or idea**
The current PCBs only support one pin layout for the I2C bus of the OLED display, meaning that alternative displays using the same driver which may be more accessible to other customers cannot be used.
The PCB could contain some hardware to allow the pins to be switched for alternative layouts.

**Images**
The Pi Hut OLED
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

CPC OLED (theoretically compatible but alternate pin configuration)
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

roryjamesallen, 2021-11-26:
Currently pursuing two possible ways of addressing this issue; hardware switches to allow configuration when the module is assembled, and a software + hardware approach where the pins can be switched using signals from GPIOs. The second would use up more pins of the Pico, but would result in much less hardware clutter and a much easier process for a DIY user.

roryjamesallen, 2021-11-26:
Further research shows only two common pin layouts exist for this OLED display, so a simpler approach is possible: A Hardware DIP switch and pull-up/down resistors.

#### The two potential pin layouts
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

#### Proposed hardware switching solution
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

In mode 1 (The Pi Hut), the DIP switch would be set to on/on/off/off
In mode 2 (CPC, AliExpress), it would be off/off/on/on

This would allow the two different OLED configurations to be used easily, with only a quick change of the switch positions during assembly to allow it to work.

#### Potential issues with solution
In theory, due to user error or misunderstanding, incorrect signals could be sent to the OLED, however this should not be an issue as the I2C bus runs on 3.3V, so even if the power rail were connected to a data pin, no damage should be caused and the issue could be fixed with a simple switch change.

roryjamesallen, 2021-11-26:
#### Illustration of proposed solution
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
DIP switch is situated underneath the OLED display to prevent accidental knocking of the switches during removal of the module, but switches would still be accessible with a pencil if required

awonak, 2021-11-26:
Another option I've seen modules use is jumpers and shunts to change hardware configuration. However, this probably wouldn't fit on the jack PCB and would have to be on the pico PBC.

Here's an example of a module I recently build that uses jumpers and shunts (regretfully I don't have the schematics). Check out page 65:
https://zlobmodular.com/wp-content/uploads/2021/01/svf_6612_builddocs-compressed.pdf

roryjamesallen, 2021-11-26:
> Another option I've seen modules use is jumpers and shunts to change hardware configuration. However, this probably wouldn't fit on the jack PCB and would have to be on the pico PBC.

Yup, I did consider using shunts and in many ways it would have been a cleaner approach, however there just isn't room on either PCB. The jack PCB doesn't have the vertical space between boards for a full jumper + shunt, and the pico PCB doesn't have the room around the existing traces and components

roryjamesallen, 2021-11-27:
A sheepish reply to my above comment: There may in fact be a much simpler header and shunt solution which would fit, as the shunts are shorter than I previously calculated, allowing for them to be mounted on the jack PCB but facing towards the pico PCB.

As the pins alternate in a certain way between the two configurations, a solution with only an 8 way 2 row header and 4 shunts should be possible, taking up minimal space and being easy to set for the user:

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

roryjamesallen, 2021-12-11:
Implemented solution works on new PCBs, users can even make the bridge simply using solder, saving the cost of shunts/jumpers if appearance isn't the priority!

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

Closed 2021-12-11.

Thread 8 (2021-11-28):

[Project Suggestion] Front access USB and reset

roryjamesallen, 2021-11-28:
# Project Suggestion

**Describe your suggestion or idea**
Currently the module needs to be plugged in via the USB on the Pico, but this means sometimes cramming the cable in between your rails, and you don't have any easy access to either bootsel or reset without removing the module.

It would be nice to have front access USB and potentially buttons for reset and bootsel.

roryjamesallen, 2021-11-28:
A solution is in progress which would use an expander module of 4HP.
The module would have front facing USB B (standard for Eurorack devices such as the Lich, Sol, or USB Pal), as well as the same buttons used on the EuroPi for bootsel and reset. It also includes a copy of the LED found on the Pico itself (GPIO25) to allow it to be used as a general purpose LED, perhaps for indicating digital input, or the current status of a variable in the current program

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

The expander would house the actual Pico, and the Pico on the actual EuroPi module would be replaced by a 'spoof Pico', a simple PCB with holes for headers, which would in turn connect the two with a 20 way wire.

This solution also has spare space to include headers for further expansion using the unused pins of the Pico.

roryjamesallen, 2021-11-29:
Further views of the concept:

Pico Side             |  Back Side
:-------------------------:|:-------------------------:
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  |  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

All unused pins are now accessible from the expansion headers at the bottom of the module, and dimensions are now correct

mjaskula, 2022-01-19:
I love everything about this, it should make working with the Europi as well as future expansion much easier.

One thing that does worry me is the size of the buttons. The look like they might be easy to hit by accident. But I guess I don't know how bad that would that be.

roryjamesallen, 2022-01-19:
That's actually a very good point that completely slipped my mind. I had been in the mindset of wanting to make everything as big and spaced out as possible but making these buttons smaller would actually be much better for this. I'll look into smaller ones similar to those used for the quality selector on Mutable Beads

mjaskula, 2022-01-19:
Yeah, that sounds like the right size to me.

Of course it’ll open up more panel real estate, which will make me want for more jacks and knobs.

roryjamesallen, 2022-01-19:
I reckon that's a good call! I might make it an alternate panel that has extra jacks/knobs as I really want this to not take away any I/O that people might want to use for their own expanders instead. It wouldn't be too hard to have an alternate version of the expander that adds a couple of extra ins and outs if people want them

roryjamesallen, 2022-01-22:
As suggested by @mjaskula, the current design now uses smaller tactile switches for the bootsel and reset functions to try and prevent accidental presses
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

noises-modular, 2022-06-30:
Could the spoof have a 2x10 pin header to allow for a common cable (assuming they are made)?

roryjamesallen, 2022-07-01:
That is actually a great idea; even better (more standard) would be a 16-16 pin Eurorack cable! Looking back at which pins would be broken out to the expander, it would be:
10 GPIO
+5V USB
GND
And then potentially some extra signals back from the Pico, such as regulated 3.3V

Anyway, the point is that fewer than 16 pins are used, so using a standard Eurorack cable would not only be more mechanically secure than a dupont style cable, but it's also much more likely to be easy to source for DIYers.

mjaskula, 2022-07-01:
One problem I see here with using the standard eurorack power cable is that someone might plug in a standard eurorack power cable and fry something.

roryjamesallen, 2022-07-01:
That is a very good point. There should be quite a lot of spare room around the connector if it is the full size of a Pico though, so perhaps with enough silkscreen warning it could be reliable?

It should also be relatively obvious as there will still be the normal power connector on the EuroPi, so hopefully it would seems illogical to connect two separate power cables to one module. I can also try to design the expander so that the 16 pin headers line up perfectly when the module and expander are side by side, so it should be pretty intuitive to connect a short 16-16 pin cable between the two, maybe if they're both labelled EXPANDER in obvious silkscreen too

awonak, 2022-07-01:
Identical pin headers on a PCB are definitely a concern, but there are many examples of modules that take this risk and provide detailed documentation to address this, for example the Zlob Entropy Expander uses 10 pin headers for its expander: https://zlobmodular.com/wp-content/uploads/2020/06/connecting_the_expander.pdf

noises-modular, 2022-07-02:
Another thought is I made a midi device with an arduino which uses a 3.5mm TRS type connection and communicates over serial to a sampler module in my rack. This expander may be a good opportunity to add an old school midi input and output to the Europi.

roryjamesallen, 2022-07-02:
That's definitely something I'll keep in mind, probably for a separate expander though as I'd rather leave as much up to the user as possible, and they might not want 2 of the GPIOs being used for MIDI if they'll never use it! It should be a pretty easy expansion module to make though, especially once the spare pins are available from the back of the USB expander

noises-modular, 2022-07-03:
I wonder if the Pico W might alleviate the need for USB access for re-programming.

Another thought on the expansion is to simplify the number of custom boards needed: a future rev of the Europi board could have a 2x16 shrouded pin header placed underneath where the Pico sits and the builder would have the option to populate it or not.

awonak, 2022-09-19:
One other potential benefit with a design like this is that you can have the microcontroller board with 2x20 female pin headers for standard breadboard sized microcontrollers like Arduino rp2040 Connect, or a Teensy 4.0.

Connectors should ideally be a common layout that supports DIY with standard cables we might have lying around. Either two 2x10 (unshrouded to allow us to use 16>10 pin eurorack power cables leaving some of the 16 pin side unconnected) or one 2x20 which is common for classic RaspberryPi boards ([example](https://www.adafruit.com/product/1988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)).

Then you can have the EuroPi connector hat PCB layout match appropriate microcontroller pins to the EuroPi peripheral header pins (basically translate a given board to the default EuroPi pico layout). This can be fabricated PCB or a simple DIY perfboard with shrouded wires connecting the microcontroller header pins to the appropriate EuroPi board pins.

This allows us to experiment with the EuroPi using different microcontroller boards and unlock hardware potential not offered by the pico!

chrisib, 2022-11-01:
I'm not sure if it's possible given the rest of the hardware in this project, but it would be awesome if there was a usable MicroSD card slot in the expander. Being able to turn EuroPi into a Radio Music clone would be really nice.

I haven't looked through all the schematics, so I'm not sure if there are any SPI pins available for connecting to an SD card module. But if you're looking for ideas to add to the expander this would be near the top of my wish list.

Regarding the buttons, is there any point in making them recessed so you need a pin or other too to reach them? I definitely like the smaller buttons for something as potentially dangerous in a live set as the reset, but a recessed button is even safer.

glaklandy, 2023-05-02:
I'm all for front-facing USB and additional buttons/knobs and i/o via 4HP expanders. :)

roryjamesallen, 2024-02-06:
The [USB Router](https://www.allensynthesis.co.uk/modules/usb-router.html) now provides front access USB, and reset and bootloader mode can both be forced over REPL, and thus over USB. The EuroPi-X is going to have front access USB so this extra module won't be required for it, but for the current EuroPi this is now solved

Closed 2024-02-06.

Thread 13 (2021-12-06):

[Hardware Issue] Cutoff of outputs is very low (~30Hz) due to RC values

roryjamesallen, 2021-12-06:
# Hardware Issue

**Describe the bug**
The cutoff of the RC filter used to filter the PWM is very low, so you any changes in voltage have a slight slew which isn't audible, but results in a reduced volume and smoothed output when running at high frequencies

roryjamesallen, 2021-12-06:
The RC values were chosen during development, and before the default PWM was changed to 1MHz.
The chosen values are a far lower cutoff than required for the new PWM frequency, and can now be changed to 100nF by default, or even lower values if you would like to output incredibly high frequencies without slew

Closed 2021-12-06.

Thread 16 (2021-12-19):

[Hardware Issue] ADC Scaling loses a lot of resolution unnecessarily

roryjamesallen, 2021-12-19:
# Hardware Issue

**Describe the bug**
The scaling that happens to the CV input before the Pico ADC will translate +12V into only around 2.64V, meaning only 80% of the ADC is being used, and that's assuming a 0-12V input which is quite unlikely.
In the event of using a more common range of 0-8V, the Pico would only see 1.76V at the ADC, meaning only 53% of the ADC is being used, and thus decreasing the resolution from a theoretical maximum of 1.9mV/step to 3.6mV/step.

roryjamesallen, 2021-12-19:
The resistor values can potentially be changed to allow a greater range, or even alternative resistor values be given to users to allow them to choose which CV input range they would most likely use.

For example:
22k resistors will allow 0-(~15V) (way above necessary/useful range)
27k resistors will allow 0-(~12V) (still above the range of most CV sources)
30k resistors will allow 0-(~10.5V) (almost perfectly uses the whole ADC for the 0-10V CV range)
39k resistors will allow 0-(~8.5V) (almost perfectly uses the whole ADC for the 0-8V CV range)

So from these calculations, values of 30k or 39k (all resistors are the same in any given build, this is two possible build options) will allow the user to either have a CV input range of 0-10V or 0-8V, in either case making use of almost the entire (95%) ADC range.

I will experiment in hardware to make sure no clipping does occur, even in the worst cases of resistor tolerances, with each suggested resistor value

senorblasto, 2022-01-07:
I know this is meant to be a easy to make a affordable project, but just want to mention that that the standard way to scale down analog input voltages for an ADC is by using an Obama.

A quad Obama would only add a few dollars to the cost and allow for significantly increased input accuracy

roryjamesallen, 2022-01-07:
I'm assuming you mean op-amps! There are op-amps in the CV input stage, it's actually a Mutable Instruments circuit, I'm guessing the confusion is because the [Prototype](https://github.com/roryjamesallen/EuroPi-Prototype) didn't have any op-amps, but don't worry this one does for inputs and outputs, so you can use the full 10V range!

noises-modular, 2022-06-30:
Any guidance for allowing bipolar voltages for CV in, such as +/- 5V?

roryjamesallen, 2022-07-01:
> Any guidance for allowing bipolar voltages for CV in, such as +/- 5V?

Bipolar is a tough one. Essentially what it would involve is adding an accurate +5V offset to any incoming CV, and then adjusting the calibration so that it "thinks" +10V is actually +5V, +5V is actually 0V, and 0V is actually -5V, and tells the user that. The software part of that would be fairly easy, but the difficult bit, at least without some pretty complex bodged in hardware, would be the 5V offset

redoxcode, 2022-11-11:
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

What are the exact resistors that need to be replaced?
Would you need to add an additional over voltage protection?
Of you change them to 39k resistors (0-~8.5V) will it still be save to feed 10V or even 12V to the cv input?

roryjamesallen, 2022-11-11:
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

R21, R22, and R23 I believe.

No extra protection required, you'd still be able to send in any voltage above the limit, it would simply be clipped. As the MCP6002 is rail to rail and powered by +3.3v the Pico's GPIO is always protected

iandoesallthethings, 2023-01-11:
> > Any guidance for allowing bipolar voltages for CV in, such as +/- 5V?
>
> Bipolar is a tough one. Essentially what it would involve is adding an accurate +5V offset to any incoming CV, and then adjusting the calibration so that it "thinks" +10V is actually +5V, +5V is actually 0V, and 0V is actually -5V, and tells the user that. The software part of that would be fairly easy, but the difficult bit, at least without some pretty complex bodged in hardware, would be the 5V offset

How hard would bipolar output be? I'd love to be able to generate +/-5v offsets.

roryjamesallen, 2024-02-15:
A new hardware revision of the current EuroPi is very unlikely to ever be made, and the X will be using external ADCs with a more carefully chosen range, so this issue is now redundant

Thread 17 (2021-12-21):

[Documentation Suggestion] Schematic inconsistency

mjaskula, 2021-12-21:
# Documentation Suggestion

**Describe the issue or suggestion**
The schematic shows 4.7uF capacitors on the output stages but that value of capacitor does not appear in the build guide or BOM. I didn't check the values of other components.

roryjamesallen, 2021-12-23:
Ah yup, that's a good spot! I recently changed the output capacitors to 100nF because the higher default PWM frequency has allowed the cutoff to be higher. The schematic has been changed to match that change now!

Closed 2021-12-23.

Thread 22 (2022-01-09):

Initial setup of EuroPi module throws an error because calibration.txt is not present.

awonak, 2022-01-09:
# Bug Report

**Describe the bug**

Initializing the EuroPi module and installing the firmware for the first time throws an error because `calibration.txt` does not exist.

**To Reproduce**
Steps to reproduce the behavior:
1. Nuke the pico filesystem or start with a new pico
2. Copy europi.py and install ssd1306 library
3. run any script that imports europi.py

**Expected behavior**

When running europi.py firmware for the first time, the firmware should not crash when `calibration.txt` is not present.

**Additional context**

```
>>> %Run -c $EDITOR_CONTENT
Traceback (most recent call last):
  File "<stdin>", line 188, in <module>
  File "<stdin>", line 126, in __init__
  File "<stdin>", line 29, in get_input_calibration_data
OSError: [Errno 2] ENOENT
```

roryjamesallen, 2022-01-10:
I believe this has been fixed in a more recent version of the europi library by changing 'r' to 'a+' to allow the file to be created if not present. I've just had a go with a freshly nuked Pico and it doesn't seem to throw an error and it does generate the calibration.txt file when required by an external program (even if the europi.py program has not been run as a script yet)

awonak, 2022-01-11:
I'm also getting the following error after the first prompt for 1V:
```
MicroPython v1.17 on 2021-09-02; Raspberry Pi Pico with RP2040
Type "help()" for more information.
>>> %Run -c $EDITOR_CONTENT
Traceback (most recent call last):
  File "<stdin>", line 231, in <module>
  File "<stdin>", line 129, in read_duty
MemoryError:
>>>
```
This can be fixed by reducing

awonak, 2022-01-11:
I must have been an old version of `europi.py` because I'm unable to reproduce. Thanks for the explanation!

awonak, 2022-01-14:
I got this error again and traced down the root cause. I was initializing my nuked pico by copying `europi.py` to the root directory and omitted creating the `lib` directory. When `lib` is not present, micropython throws an error trying to read/write to a folder that does not exist on the pico.

roryjamesallen, 2022-01-14:
Ahh that is a very good find. An edge case for sure but I'll look at writing something in that gives a useful error message if it thinks it's being run outside of the lib folder

Closed 2022-01-11.

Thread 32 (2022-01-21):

[Bug Report] Max output voltage capped at 9.12v?

awonak, 2022-01-21:
# Bug Report
Testing the `Output` class, I am unable to get the output voltage above 9.12v.

**To Reproduce**
Steps to reproduce the behavior:

From a MicroPython shell running on the pico, I am testing setting the cv1 output duty cycle to the maximum value and I am only seeing 9.12V max.

```python
> cv1.pin.duty_u16(65535)
```
On my oscilloscope I am reading 9.12v.

**Expected behavior**

I would expect to see a maximum output of 10v.

roryjamesallen, 2022-01-21:
Ooer, this is pretty serious. I think it must be due to resistor combinations in the amplification stage for the outputs, but I'm not quite sure how it's losing so much voltage.
The calculation for  a non-inverting op-amp is
Gain = 1 + Rf/Rin
Gain = 1 + 220k/100k
Gain = 1 + 2.2
Gain = 3.2

So in theory, with 3.3V output from the Pico, it should amplify to (3.3 * 3.2) = 10.56V, leaving a nice amount of headroom
I've measured the voltages at various points along the output stage and got 3.25V after the RC filter stage, and then 9.00V at the output pin of the op-amp, so somehow it clearly isn't being amplified to the factor that it should be

roryjamesallen, 2022-01-21:
Ok so lots of experimentation later, I have found that the problem is caused by the LED resistor forming a voltage divider with the internal resistor of the op-amp, and causing the voltage drop.
The good news is that by swapping the BOM to use 4.7k resistors instead of 1k for the LEDs, the output voltage is back above 10.3V (10V + a nice amount of headroom), and the LED is still nice and bright

mjaskula, 2022-01-21:
a couple things on this change:

- the schematic pdf (and I assume the kicad file) need to be updated with the resistor change
- the bill of materials should include R18 as a 5k1 resistor.
- an update to or at least a note on the strip board layout.

roryjamesallen, 2022-01-22:
All edits have been made to the mentioned files to change the resistors to 4k7. I haven't got any on hand to double check but I've tested with 5.1k and it works perfectly, so if you've tested it and it's all good with 4k7 I think this is solved?

mjaskula, 2022-01-22:
We discussed the testing in discord. On my module, the 4k7 resistors yield a 10.4v output on the 10v output using the diagnostic program. This is with the default calibration.

mjaskula, 2022-01-22:
Actually with the new default calibration, the 10v output is 10.07v

awonak, 2022-01-22:
Throwing my confirmation in here too. I just replaced R13 with a 5.1k resistor and I'm able to output a max voltage of 10.17v.

callimero, 2022-10-15:
BTW: Guess which Output I used for my breadboard build?

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

Closed 2022-01-22.

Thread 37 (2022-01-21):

[Project Suggestion] Program selection menu

mjaskula, 2022-01-21:
# Project Suggestion: Program selection menu

As we add user contributed scripts we will (hopefully) end up with a large enough collection that the module will be useful 'out of the box' and not *require* that the user write their own scripts. In this case it would be nice to be able to switch amongst these scripts without connecting a computer and re-writing `main.py`.

I think that a proper menu system will require that we design two major pieces:
- hardware UX: the actual menu that the user experiences via the OLED, buttons, and knobs
- software API: The menu program and API that allows programs (apps?) to be included in the menu easily.

I believe that some work had already be done towards this, at least with the prototype module (https://github.com/awonak/EuroPiAlt). I suggest that we use this issue to focus these efforts and gather input on what this menu should be and how it should behave.

mjaskula, 2022-01-21:
Here are some of my ideas to get a conversation started

Hardware UX:
- should work on the base EuroPi and not require an expander, but it's ok if the expander makes the menu easier to use
- first boot should dump you to the menu, subsequent boots should run the last running program
- it should be easy to exit a program and return to the menu, but it should require purposeful action, the user shouldn't end up there by accident
- My first though on how it should behave:
    - the screen shows a list of programs with one selected
    - the buttons are 'up' and 'down', allowing you to scroll through the list to select the program you want
    - a long press on both buttons launches the selected app
    - a long press on both buttons exits the app back to the menu

software API:
- Each program is an implementation of a base class which allows the user to define various aspects of the program including:
    - name
    - main loop
    - handlers
- We'll need a way of registering the available programs in a way that keeps the menu consistent between runs
- handlers should be registered on launch and removed on exit
- it would be nice to include a way for programs to save and load state

roryjamesallen, 2022-01-22:
I really like the bootloader idea and I'm sure I would use it on one of the EuroPis in my rack, but I think there are a lot of people (myself included in some cases) who would see the bootup taking you to a menu as a very bad thing, when one of the draws of modular is the immediacy of being ready to patch.
What would you guys think about developing the bootloader alongside the main branch as an alternate programming process, and then users can always swap between the two but there's still a clean and clear guide for one program, loads immediately?

I'm conscious that there have been design changes made, such as potentiometers instead of encoders, that are gearing the module towards standalone programs, and that's how I've been writing them (so that they are almost worthy of being made into a dedicated module). I kind of want to avoid the most common use of the module being another disting/O_c where people aren't as encouraged to write their own programs because it's seen from the surface as being a menu based multi-function!

mjaskula, 2022-01-22:
I definitely want the menu to be something that you visit intentionally. That's why I said:

> first boot should dump you to the menu, **subsequent boots should run the last running program**

I think the value of the menu at first boot is that the user can jump into using the module right away after getting it racked. They don't _need_ to write their own program. My assumption is that if they bought this thing, they _want_ to write their own, but not necessarily before they start wiggling.

That said, I think that the menu system would just be another program that the user has to load, coupled with a directory of the contributed programs. So the documentation could, remain as it is: (1) build, (2) optional calibration, (3) make it your own. And off to the side would be separate instructions to either (a) load a single program from the contrib dir, or (b) load the menu system along with the full contrib dir. So the question is how far off to the side does this need to be?

Also, I'll admit that as I've thought about the UI for different potential programs I've wished for encoders. I've also looked at the uO_c layout and thought that it might be a good direction for the next hardware iteration of the EuroPi to target. So, I'm glad to hear your thoughts and vision on this to that I can temper my expectations. And that if I do want to go in that direction it might be on my own project or expansion.

roryjamesallen, 2022-01-22:
Ah, I completely missed you saying subsequent boots should be into the previous program, that does sound like a great solution for storing multiple programs then.

I think the O_c layout is great for what it does, but accomplishing the same with the Pico would require quite a lot of extra hardware (and thus HP unless we make it SMD) as the Pico has very few on board ADCs.

I do think encoders have a lot of advantages, but the simple fact that very very few beloved dedicated modules have encoders, even for 'digital' parameters (e.g. the new Mutable Beads has a potentiometer for the density control despite it selecting discrete values) proves that people like the feel of a smooth, click-less knob, with at the very least the *perception* of continuous control.
I did deliberate for a long time when designing the new hardware about encoders, it's probably one of the things I was hung up on for the longest, so I'll agree with all the points in favour of them, I just think that the specific direction I'm going with this project (a platform with which people can design programs that are worthy of being standalone modules) leans towards potentiometers!

Of course there's also nothing to prevent anyone from designing an alternative hardware that uses encoders instead, I might even design an expansion module that has an encoder so it can be used for menu navigation if that's the direction lots of people seem to want

mjaskula, 2022-01-22:
No worries, I think, in general, we are on the same page.

It's nice to hear about these design decisions. You might consider writing some of them up, as blog posts, or whatever. I think it would help this fledgling community understand where you're coming from and the work you've put in a little more.

And yeah, an encoders expansion would be great.

roryjamesallen, 2022-01-22:
That's a good idea! I'll write some stuff up, possibly using GitHub discussions, although I've never used them before...

I'm thinking of an expansion in maybe 4HP with one or two encoders and one or two push buttons, that way you could have a single button dedicated to entering the bootloader and then an encoder that chooses the current program, or even something more complex like the way O_c can run multiple programs at once where you could run multiple simple programs at once using the same inputs e.g. top row of CV outputs are a sample and hold, bottom row is a clock divider

awonak, 2022-01-22:
I've got lots of thoughts and opinions on this topic, but I'll start with a few key observations from my work with the EuroPi-Prototype and my [Bootloader](https://github.com/awonak/EuroPiAlt) firmware. I'm in favor of the simple `europi.py` + `main.py` firmware and script approach as the default, and perhaps some additional directory for alternative firmwares (e.g. bootloader).

### EuroPi *must* be beginner friendly first
I have noticed folks from a wide range of backgrounds getting really interested in the EuroPi, some using this to try Python for the first time. I think it's important to ensure whatever changes we make, still keep the project easily accessible to beginners.

### Thonny is the default editor and it sucks at copying multiple files
I'm not aware of a way to copy entire directories or multiple files at once from Thonny to the pico. As a result, each individual contrib script would have to be copied manually. Yuck. This is why I have moved my development process over to `rshell` so I can use cp or rsync to copy multiple files in one shot. As my firmware and script library grew, I started using reusable libraries, so the number of files grew even more. As complexity grows we'll inevitably move in this direction too, so we'll need to keep in mind a good solution for simplifying this.

### Beware of hardware expansions
Early on I build a crappy [expansion board](https://github.com/awonak/EuroPi-Prototype/tree/main/contrib/expander) to give me input and additional knob control. This was awesome in theory, but I realized if I used the expansion module in any of my scripts, no one else would be able to use it. If we add any code that depends on expansion modules, then anyone without the expansion module won't be able to use it. Then you can get in the trap of forking scripts for use with/without expansion modules or excluding portions of the community who don't have that module. It's a tricky area.

### The bootloader is awesome
On my EuroPiAlt firmware, I love being able to load up any of my finished scripts for any patch I create without the need to reconnect the EuroPi to my computer. I see huge value in a bootloader script for those who want to run it. This is definitely an area worth exploring while ensuring EuroPi is still beginner friendly.

mjaskula, 2022-01-24:
I agree with everything Adam is saying here, that all sounds like the right philosophy to have.

Regarding expansion boards, I think they should be out of scope for this menu program discussion. That said, we should definitely make it a policy that no code gets merged to this repo that _requires_ an expansion board. If there's ever an official expansion board, or something third-party that is common in the community, then we can explore adding _support_ for it. But as Adam said, we will need to be careful.

awonak, 2022-01-26:
One design decision we'll have to consider here is the use of async. In my version of the firmware, the bootloader ran inside an [async event loop](https://github.com/awonak/EuroPiAlt/blob/main/src/bootloader.py#L94-L99). This allowed us to create async tasks like led triggers, button handlers, and other parallel tasks to improve performance and simplify code in some instance (but more complex in others).

As a result of this decision, scripts were required to define an [async main method](https://github.com/awonak/EuroPiAlt/blob/main/src/scripts/coin_toss.py#L76). In order to run, they would have to be started by an [async event loop](https://github.com/awonak/EuroPiAlt/blob/main/src/scripts/coin_toss.py#L104-L108
). Additionally, scripts needed to be manually added to the [bootloader script list](https://github.com/awonak/EuroPiAlt/blob/main/src/bootloader.py#L46). This might be desired if we want users to control what scripts to include/exclude, but it does add a required step when creating a new bootloader compatible script.

For our bootloader design, I'd like to avoid imposing script requirements like this as much as possible. If any requirements still exist, we should make that as easy as possible for folks, such as providing a base class with default behavior or solid documentation. Also, we should strive to make bootloader scripts backwards compatible with non-bootloader default firmware.

awonak, 2022-02-05:
Another thought that might help simplify the requirements for making a compatible script for the script selection menu is to use `boot.py` as the bootloader to choose from a list of script files and copy the selected file to `/pyboard/main.py`

https://docs.micropython.org/en/v1.9.3/pyboard/pyboard/tutorial/script.html

mjaskula, 2022-02-10:
I'm gonna run with this idea and see how far I get.

mjaskula, 2022-03-16:
This was completed with PRs #82 and #101.

Closed 2022-03-16.

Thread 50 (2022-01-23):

[Project Suggestion] Create EuroPiError class

awonak, 2022-01-23:
# Project Suggestion

When the EuroPi isn't connected to a serial output and an exception is raised, it's not obvious what happened.

**Describe your suggestion or idea**

It would be helpful to have a EuroPi specific error class that displays the error message to OLED when an exception is thrown.

This can be useful to explicitly throw:

```python
# europi.py
def choice(self, values, samples=None):
    if not isinstance(values, list):
        raise EuroPiError(f"choice expects a list, got: {values}")
```
The expectation would be that the error message fits as much of the exception text onto the oled display as possible. This makes it clear an error has occurred and helps hint at what the error was.

A more tricky case is when there is an unexpected error thrown. If it's not caught, then the oled wont show the error message.

One way to address this is to have a main entry point into the script and wrap that in a try/except/finally block.  For example:

```python
# coin_toss.py
try:
  coin_toss = CoinToss()
  coin_toss.main()
except BaseException as err:
  raise EuroPiError(e)
```
**Images**
If applicable, add screenshots or photos to help explain your problem.

mjaskula, 2022-01-24:
Putting exception messages on this tiny screen sounds problematic, and so does putting them in front of users that didn't necessarily write or work on the code. That said, we clearly need some solution here in the event of a crash.

This might be a good place to use error codes. Print `Error 42` on the screen and the user can look it up in the docs, or post it to the discord support to get help.

awonak, 2022-01-24:
+1 Error codes sound like a much better solution.

On Mon, Jan 24, 2022, 1:47 PM Matthew Jaskula ***@***.***>
wrote:

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

roryjamesallen, 2022-01-25:
Error codes sound like a great idea, I'll start having a look at current errors which would be assigned codes

roryjamesallen, 2022-08-12:
Going to close this one for now, and then we can reopen when we find an appropriate use case for error codes

Closed 2022-08-12.

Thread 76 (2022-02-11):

[Hardware Issue] The module does not use the 5V rail

roryjamesallen, 2022-02-11:
The module regulates its own supply using a linear regulator rather than using the 5V rail which would be cleaner

roryjamesallen, 2022-02-12:
This is a design decision rather than an issue, with the thought process as follows:
1. Using the 5V rail would require a 16 pin connector which would take up a lot of space on the PCB
2. Not all users have a 5V rail that can supply enough current for more than one or two modules, or have a 5V rail at all (especially in the DIY community), so an on-board regulator would still be required anyway
3. Now you also need the extra space for an on-board/5V rail selector, as well as the extra space for the 16 pin power connector
4. There is not space on the PCB for these changes

After the above considerations, there are only a few solutions:
1. Make the module 2HP wider to account for the extra hardware
2. Entirely redesign the hardware to *try* and fit the extra hardware
3. Make parts of the hardware SMD to leave more remaining space for the extra hardware
4. Use *only* an on-board regulator, and make sure it is adequately isolated from the 12V supply

As I'm sure you've already guessed, I chose option 4.
The first two require either a lot more time than I currently have (or that this specific minor issue deserves), or would leave the front panel very sparse.
Option 3 will make this project much less accessible to beginner DIYers (more of whom than you may think will be put off attempting a project simply because it contains one or more SMD components). The only alternative would be to increase the manufacturing costs significantly by soldering the SMD components before shipping.

The chosen solution not only keeps the module small, but provides a 5V supply that is perfectly adequate for powering this module without causing noise. There are also a few safety measures to reduce the problems caused by a linear regulator.
- The 5V supply is fed to the Pico via a Schottky diode which will prevent the Pico itself from affecting the power supplies
- The 5V rail has a decoupling capacitor to prevent high frequency noise
- Both 12V rails have large decoupling capacitors which will prevent high frequency noise

Closed 2022-02-12.

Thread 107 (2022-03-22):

[Question]

vfilby, 2022-03-22:
# Question

**Ask your question**
On the build I did the LEDs are very bright (used what I had on hand rather than ordering to spec).  I was thinking I should be able to tone them down by replacing the 4.7k resisters leading to each LED with something closer to 33k.

Is this a reasonable approach or would you recommend something else?

roryjamesallen, 2022-03-23:
This would be the right solution, just increase the resistors going to each LED! Increasing will not be a problem at all, however you can't decrease the resistance or the LEDs may cause the output voltage to drop, preventing the calibration from being able to complete (and thus making output voltages inaccurate)

Closed 2022-03-23.

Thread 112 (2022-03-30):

[Documentation Suggestion] Error in Cap ID in Build Instructions

bsom, 2022-03-30:
# Documentation Suggestion

**Describe the issue or suggestion**
https://github.com/Allen-Synthesis/EuroPi/blob/main/hardware/build_guide.md
"Solder the 100nF capacitors to the back (C8, C9)."
They are numbered C7 and C8 on the board, not C8 and C9

roryjamesallen, 2022-03-30:
Good spot! I think this is a left over issue from changing around the labelling of all the components during the build guide improvement. I'll fix this asap!

Closed 2022-03-30.

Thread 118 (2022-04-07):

[Bug Report] No way to exit calibration if run from the menu, potentially leading to unusable calibration values

roryjamesallen, 2022-04-07:
# Bug Report

As written by CestBallot in the Discord:

If you use the menu.py and if you start a calibration without any tools, it can be a problem.
The calibration tools don't have any return/ cancel button ( like the button 2 who can do it) and if I press button 1 it calibrate with No input so bad calibration... and after a reboot my module don't up the oled screen.

roryjamesallen, 2022-04-07:
This I would count as 2 issues in 1:
The first issue is that there is no way to exit calibration if run from the menu,
The second issue is that if unusable calibration values are generated somehow, the module will 'brick' and not give any kind of error code. I think this should either be fixed with an error code using the EuroPi error class as suggested in #50 , or by having europi.py validate the calibration values before attempting to use them, and reverting to a set of default values if they are unusable.
I prefer using the error class, although a combination of the two would be best, leaving the module usable with default values, but letting the user know that the calibration did not generate usable values

mjaskula, 2022-04-08:
I am having trouble reproducing these issues. I am able to exit from the calibration script to the menu at several points in the script. Also I have calibrated without ever connecting any cables and it still boots and runs the diagnostic script. The ain reading is bad now, of course, but it is running for me.

As for a fix for a bad calibration file, I think that it can be simpler, and constrained to the calibration script. First, I think that the calibration script should avoid writing to the calibration file until the end of the script, so that the user is less likely to quit the calibration with half of the file written. Second, before writing the data, the script can perform any sanity checks that we might have. This would mean that we would only need to check once.

roryjamesallen, 2022-04-08:
Adding sanity checks definitely seems like a good idea even if it wasn't the fault in this actual case.

I also can't recreate any of this bug and can quit to the menu during the script with no issues, so perhaps this is a bug caused by an altered or older version of the firmware, or by a very very specific sequence of events which cause the calibration values to be written in a way that halts the firmware (although I think this is unlikely)

roryjamesallen, 2022-07-18:
If this one was an issue before, it seems impossible to recreate in the current firmware so I'm going to count this one as fixed. We can always re-open if anyone experiences the same problem in future

Closed 2022-07-18.

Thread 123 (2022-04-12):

[Bug Report] Potential issue with din handling some clocks

gamecat69, 2022-04-12:
# Bug Report

**Describe the bug**
Some clocks appear to be too short to trigger the din handler.

**To Reproduce**
Send a short clock to din. Some clocks trigger the din handler, others do not.

**Expected behavior**
It is expected that a clock input to din will always trigger the din.handler.

**Images**
n/a

**Additional context**
Tested so far:
- Gates / square LFO with 50% duty cycle: works OK
- Malekko Varigate 4+: works OK
- Shakmat Time Apprentice sending clocks: causes this issue
- Shakmat Time Apprentice sending gates: works OK

roryjamesallen, 2022-04-14:
I don't have a Time Apprentice, is there any chance that someone has both a time apprentice and an oscilloscope so that they could see the length of the pulse when sending clocks?

roryjamesallen, 2022-04-24:
Updates from Discord:
Clocks under 0.01s seem less reliably detected by the firmware, however this could still be dependent on the currently running script.

Increasing the system clock speed improves reliability (minimum clock pulse that can be reliably detected), and increasing the system clock speed to as high as 250MHz seems to have no disadvantages,  so I am leaning towards adding that line to the firmware as it is. It can be overridden in each script if the user needs a slower system clock for some reason, but otherwise it seems that this line of code is being copied by most contributors into the individual scripts

gamecat69, 2022-06-07:
After some testing: Clocks >= 0.007s are OK, shorter and there will potentially be problems.

roryjamesallen, 2022-07-18:
This has now been added in a list of limitations to [programming_instructions](https://github.com/Allen-Synthesis/EuroPi/blob/main/software/programming_instructions.md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)

gamecat69, 2022-10-11:
I do. But it’s a cheap scope (DSO150) and difficult to measure time accurately. I will have a go this weekend and let you know.

Kind Regards,
Nik
(Sent from a mobile device)

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

bretdennison, 2022-11-11:
Tried getting my Europi to work with Pamela's New Workout, but no luck.  I even tried increasing the gate duty cycle (Width), but no luck.  It works fine with my WMD Metron as the clock.

Closed 2022-07-18.

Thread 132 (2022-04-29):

[Bug Report] Ghost Button presses

gamecat69, 2022-04-29:
# Bug Report

**Describe the bug**
This could potentially be a problem with the hardware or perhaps the firmware button debounce method.
On some occasions a b(n).handler_falling interrupt can be triggered without a physical press of a button. However, it is quite difficult to reproduce and seems to happen mostly randomly. The bug was identified after logging was added to the CVecorder script.

**To Reproduce**
In some cases this can be produced by starting the module with nothing connected, then connecting CV to ain followed by a clock into din. However, this problem does not happen all the time and appears to happen rather randomly.

**Expected behavior**
A b(n).handler_falling interrupt should not be triggered unless a button is pressed and then released.

**Images**
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

**Additional context**
This bug has been identified so far only when using the CVecorder script - as a button press can trigger the deletion of recorded CV, so it is therefore obvious when it happens. However, I believe this issue could manifest in all scripts.

gamecat69, 2022-08-03:
Confirmed to appear in probapoly and consequencer too.
Placing an upper time limit on a long button press detection dramatically reduces the chance of a phantom button press like the snippet below (3000 is used as an upper limit in this example).

`if ticks_diff(ticks_ms(), b1.last_pressed()) >  500 and ticks_diff(ticks_ms(), b1.last_pressed()) < 3000:`

gamecat69, 2022-11-14:
This is great! How do you feel about raising a PR for a change to the europi.py firmware?Kind Regards,Nik(Sent from a mobile device)On 14 Nov 2022, at 17:19, redoxcode ***@***.***> wrote:
I noticed these as well working on my own script. I know there are pullup resistors on the europi board, but also enabling the internal pullups of the pi pico seams to resolve these issues for me. I think my header pins on the pico are not the best and it only happens on some eurorack PSUs.
To test this you can enable the pullups in your script like this:
    b1 = Button(4)
    b1.pin=Pin(4, Pin.IN,Pin.PULL_UP)
    b2 = Button(5)
    b2.pin=Pin(5, Pin.IN,Pin.PULL_UP)

or directly change this line in europi.py
    self.pin = Pin(pin, Pin.IN)
to
    self.pin = Pin(pin, Pin.IN,Pin.PULL_UP)
There are some other things I want to optimize in the DigitalReader class, that might resolve or at least reduce this issue as well.
I will propose a PR for these when I got time.

—Reply to this email directly, view it on GitHub, or unsubscribe.You are receiving this because you authored the thread.Message ID: ***@***.***>

gamecat69, 2022-12-22:
I can confirm the suggested code change seems to avoid the phantom button presses

gamecat69, 2022-12-23:
Unfortunately, this change prevents the ability to long-press both buttons to return to the menu.

redoxcode, 2023-01-23:
Is this still present? There was some minor fix to the logic in https://github.com/Allen-Synthesis/EuroPi/pull/212

redoxcode, 2023-01-23:
>

> Unfortunately, this change prevents the ability to long-press both buttons to return to the menu.
I guess you lost the irq handler for the both action by redefining the buttons.
That handler gets set in bootloader.py.
You should try to change europi.py to include the PULL_UP.

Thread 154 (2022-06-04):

[Bug Report] PWM frequency is causing noisy cv output

awonak, 2022-06-04:
Additional observation from @t-schreibs
> Ran into an odd issue the other day. Probably not a support thing, but idk where else to drop this, and I'd be interested to hear what y'all think. I was feeding CV values from one EuroPi into another, where the second one was running Poly Square, and the output I was getting was bizarre, like almost FM-y. It was like the input analog value was super noisy. However, feeding those CV values into another oscillator (was testing w Beads w no audio input) sounded crystal clear, and any other CV value into Poly Square was also crystal clear. I'm trying to figure out where to start debugging this. Any chance it's a weird hardware thing?

Further observations from @t-schreibs
> I have one EuroPi which, I believe, is still running 0.3.0 of the firmware, and the rest are up to 0.5.0. I'm testing w RadioScanner into Poly Square just to get an easily controllable steady CV value. While the output from 0.3.0 is not perfect by any means (I'm getting audible pops & crackles), the pitch center is much more stable. The output from 0.5.0 wanders quite a bit

> Yep, I've confirmed there's something up with the latest version - I brought the other EuroPi up to 0.5.0 and now it's demonstrating the same problems as the other ones

Root cause suspected to be the change in PWM freq:
https://github.com/Allen-Synthesis/EuroPi/commit/f0ae072c8d8b9be717c8cc5740b783c510d81367

Oscilloscope testing between versions:
https://imgur.com/a/C5h0YYn

awonak, 2022-06-04:
Documentation on valid PWM freq ranges:
https://docs.micropython.org/en/latest/rp2/quickref.html#pwm-pulse-width-modulation

In my testing, I found that the PWM freq can be set to match the machine freq, with the higher the machine & pwm freq, the less noisy the cv output will be. Both machine and pwm freq overclocked to 250mhz had the best results. However, I don't know if this has any performance implications on the rest of the script. That will require a bit of further testing.

awonak, 2022-11-20:
Another consideration is for the firmware to provide a mechanism for switching between PWM modes, for example:

- High resolution (default): lower pwm freq to produce smoother resolution at the cost of stable voltage (eg. envelopes)
- High CV Accuracy: higher pwm freq to produce more stable cv at the cost of step resolution (eg. pitch cv)

Closed 2022-12-01.

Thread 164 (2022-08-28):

[Bug Report] Missing experimental package

awonak, 2022-08-28:
# Bug Report

**Describe the bug**
EuroPi v0.6.0 introduces `experimental` package and is imported with:

```
    from experimental.knobs import KnobBank
```

However since the `experimental` package isn't included in the pypi package, loading a script that depends on it will throw an error:

```
MicroPython v1.18 on 2022-01-17; Raspberry Pi Pico with RP2040

Type "help()" for more information.
>>> %Run -c $EDITOR_CONTENT
Traceback (most recent call last):
  File "<stdin>", line 19, in <module>
  File "/lib/contrib/turing_machine.py", line 37, in <module>
ImportError: no module named 'experimental'
>>>
```

awonak, 2022-08-28:
For a quick fix, comment out lines [line 19](https://github.com/Allen-Synthesis/EuroPi/blob/main/software/contrib/menu.py#L19) and [line 39](https://github.com/Allen-Synthesis/EuroPi/blob/main/software/contrib/menu.py#L39) of your `main.py` copied from [menu.py](https://github.com/Allen-Synthesis/EuroPi/blob/main/software/contrib/menu.py)

awonak, 2022-08-28:
I have deleted the tag `0.6.0` and [yanked](https://pypi.org/help/#yanked) the release from pypi.

awonak, 2022-08-28:
Fixed in https://github.com/Allen-Synthesis/EuroPi/commit/b5f9c9f61f7f5d8dc8af27b4c8d98dc7641d5393

Closed 2022-08-28.

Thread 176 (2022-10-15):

C3 - C14	100nF

callimero, 2022-10-15:
# Documentation Suggestion

**Describe the issue or suggestion**
The BOM says Nanofarad Capacitor (Non-Polarised)

The schematic shows polarized caps.

roryjamesallen, 2022-10-16:
This is because some DIYers might only have polarised caps on hand of this value, and polarised caps work just as well.

The thing is that if the schematic (and therefore PCB footprint) were non-polarised, then users with polarised caps wouldn't know which way around to place them, whereas if the footprint is polarised (as it is currently), users with non-polarised caps can just put it either way, and users with polarised caps can orient it correctly.

Closed 2022-10-16.

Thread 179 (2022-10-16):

[Bug Report] Pico does not connect to Thonny under normal conditions

roryjamesallen, 2022-10-16:
# Bug Report

When connecting a EuroPi running at least the newest version of MicroPython, Thonny fails to connect to the Pico, either giving a 'Device is busy or does not respond' error (or similar) or failing to show up in Thonny at all.

Windows often gives a 'USB device not recognised' message.

**To Reproduce**
Steps to reproduce the behavior:
1. Do not have rack power turned on
2. Have the Pico installed in the module
3. Plug the module (Pico) into a computer via USB
4. Open Thonny and press stop to attempt to make a connection
5. The device does not show up

**Expected behavior**
The module should connect in this order of events, and in the past it did

**Images**
No Pico shown despite USB connection:
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

Windows USB message:
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

**Additional context**
This order of events has worked fine for programming in the past, so something in either the firmware, MicroPython version, or OS update has changed.
You can still program the module by either
1. Plugging the Pico in via USB and making the connection *before* plugging the Pico into the module itself
or
2. Plugging the module into power (with the Pico installed) and waiting for it to boot fully, and *then* connecting it to a computer via USB

roryjamesallen, 2022-10-16:
# Important discovery
Adding a sleep(1) to the start of main.py (menu.py), prevents this issue from occurring, at least on my machine.
I can remove the sleep(1) and the issue will re-arise immediately and consistently, and add it back in and it will vanish.

Based on this, I think that some kind of interference between Thonny/MicroPython/EuroPi firmware is occurring, specifically that the running of main.py automatically and immediately upon power-on prevents a reliable USB connection from being established.

The fact that adding this delay fixes the issue also lines up with the fact that booting the module via rack power is also a workaround, as it means the USB connection and main.py booting happen at different times, so main.py cannot interfere and block the USB connection.

roryjamesallen, 2022-10-17:
Not yet tested but polling GPIO24 would allow a different operation if connected via USB.
If USB is connected, GPIO24 will be high, so a single ```if``` statement would be sufficient to for example add the delay as above only if connected to USB, and not have to delay scripts that are running solely on rack power (where this issue does not need to be accounted for)

roryjamesallen, 2023-03-22:
This issue is currently solved by a workaround, the removal of which is documented in #184

Closed 2023-03-22.

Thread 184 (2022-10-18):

[Bug Fix Tracking] Remove workaround for USB connection issue when possible

roryjamesallen, 2022-10-18:
This is an issue solely to track the workaround to fix the USB connection issue, as it will hopefully be fixed 'properly' by a MicroPython version in the future, at which point the workaround should be removed and the previous MicroPython versions marked as incompatible with the module.

## Specific removal condition
For the workaround in menu.py implemented in #183 to be removed, the following sequence of events must be able to be carried out without error from the Shell in Thonny:
1. Have the Pico installed in the module
2. Have rack power turned entirely off, and no USB connected
3. Connect the Pico/module to a computer running Thonny using a USB cable
4. Choose the port in Thonny to select 'MicroPython (Raspberry Pi Pico)
5. Wait for ```>>>``` to be shown in the Shell window

roryjamesallen, 2023-05-01:
Using MicroPython 1.20.0, this appears to be fixed

roryjamesallen, 2024-02-15:
Fixed in #333

Closed 2024-02-15.

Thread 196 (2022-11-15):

[Hardware Issue / Project Suggestion] Increase threshold for digital input

redoxcode, 2022-11-15:
# Hardware Issue: Increase threshold for digital input
This is a minor Issue, but should be addressed when a hardware revision is made:
The threshold for the digital input to read as high is about 0.8V with the current hardware.
This might cause accidental triggers when used with noisy or not perfect square eurorack signals (8-10V cv)

**Expected behavior**
For eurorack levels it would be better if the threshold would be increased to something between 2.5 and 5V.

roryjamesallen, 2022-11-19:
Yup, this is a very good point! For future hardware it will be higher.
For the current hardware you should be able to very easily hack the threshold to be higher too: By soldering a resistor from the cathode of D1 to ground you will create a potential divider on the input before it reaches the transistor. The input resistor is 100K, so a simple potential divider equation can be used to set your own input threshold.
| Added Resistor | New Threshold |
| ----------------- | ---------------- |
| 100k | 1.6V |
| 47k | 2.5V |
| 18K | 5.24V |

roryjamesallen, 2023-01-03:
As this would break compatibility with DIY expanders and the current documentation, I'm going to mark as resolved and re-open/move to a new repository when one is made for the next major hardware iteration i.e. where incompatible changes can be made

roryjamesallen, 2023-01-03:
> Can you explain how this would break compatibility with DIY expanders?

Although it is a very unlikely incompatibility, there is a chance that users will have developed expanders or other modules which rely on the digital input having such a low threshold.
For example, say a user had designed an expander that only used 3.3V logic, for which a 'high' signal of +3.3V would be more than enough to trigger the digital input, but then the hardware was changed to have a threshold of say 5V and their expander would no longer be able to trigger the digital input at all.

It is certainly a change that should be implemented in future hardware, but I believe implementing a non-compatible change to the hardware without a new version would be a mistake, and this change alone doesn't warrant an entirely new and theoretically incompatible hardware version of its own

Closed 2023-01-03.

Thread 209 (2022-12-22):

[Hardware Issue] Noise on knob values and analogue inputs

gamecat69, 2022-12-22:
# Hardware Issue

**Describe the bug**
There is noise present when sampling the analogue inputs or knob values. This noise offsets the value read at the extremities of the readings, e.g 0 will never read 0 and the max value will never read the max value.

This issue causes the the percent() value to never read 100% on some modules. The issue also causes the analogue input to never read 0 Volts.

**To Reproduce**
Steps to reproduce the behavior:
Read any value from k1 or ain to more than 1 decimal place several times.

**Expected behavior**
It would be great if something like a deadzone was implemented. e.g. if really close to 0 the value returned is 0 or of close to the max the value returned is the max value.

gamecat69, 2022-12-22:
Note that a deadzone would be needed for both knobs and the analogue input. As the analogue input never truly reads the min or max value (in the same way as the knobs), due to the averaging done in _sample_adc().

gamecat69, 2022-12-23:
An alternative method would be to mask this problem at a lower level in the _sample_adc function using something like the example below. One benefit of doing this is that it would mask the problem in all higher level functions for both the knobs and the analogue input.

```
    def _sample_adc(self, samples=None, low_dead_zone=190, high_dead_zone=65500):
        # Over-samples the ADC and returns the average.
        values = []
        for _ in range(samples or self._samples):
            values.append(self.pin.read_u16())
        #return round(sum(values) / len(values))
        val = round(sum(values) / len(values))
        if val < low_dead_zone: # This is just noise, remove it by setting to 0
            return 0
        elif val > high_dead_zone: # probably noise, set to highest value
            return 65535
        else:
            return val
```

gamecat69, 2022-12-23:
I was a little concerned that in our haste to develop a fix, we perhaps had not correctly defined the problem, how to test for it and how to test that any change had fixed it lol! :)

... so I created a simple test script that displays the following:
1. Noise at the lowest and highest levels when reading from k1 and k2
2. Noise at the lowest level when reading from ain (I excluded the high val test for ain partially for speed and partially because I do not believe this will cause much of a problem for most)

When running the test, I believe the problem is present if any low value is greater than 0 and any high value is less than 1.0.

I ran this test twice, once using the suggested fix to _sample_adc and once using the suggested by @redoxcode.

The _sample_adc update fixed the problem for both the knobs and ain.
The suggestion by @redoxcode fixed the problem for the knobs, but not for the ain.

gamecat69, 2022-12-25:
Good point around calibration for ain. I was thinking that might be a possibility. While calibration is mentioned, why don’t we include the knob deadzones in the calibrating routine too? But have default values for un calibrated modules like for the other values?Kind Regards,Nik(Sent from a mobile device)On 25 Dec 2022, at 10:06, redoxcode ***@***.***> wrote:
I don't think this should be a implemented in _sample_adc  as it returns an in from 0 to MAX_UINT16 that is the direct average of the samples that are in this range them self. Especially with sample size 1 this would result in a strange mapping. _sample_adc should do what everyone expects it to do.
I haven't enabled deadzones for ain in my code since I don't think deadzones are the right way to handle this issue for ain. A change in way the calibration works would make more sense (not just calibrate the high point, but also the 0 point including any noise).
But since my suggestion is implemented in the AnalogReader class it could be enabled for ain as well. But it shouldn't!
I finished my tests on actual hardware and will make a PR later.

—Reply to this email directly, view it on GitHub, or unsubscribe.You are receiving this because you authored the thread.Message ID: ***@***.***>

redoxcode, 2023-03-27:
Closed?

gamecat69, 2023-03-27:
Has the analogue input noise issue been fixed or was a fix only developed
for k1 and K2? If the aim issue is still present, then I guess this issue
is still open.

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

redoxcode, 2023-03-27:
There was a PR that fixed 2 point calibration (https://github.com/Allen-Synthesis/EuroPi/pull/232)
idk, I don't have that issue so I can't test.

gamecat69, 2023-04-03:
@redoxcode: I am interested to hear what results you get when you run the test script I provided above.
Do you not experience the noise on ain? i.e. is the value 0 when nothing is plugged in when you run the test script?

redoxcode, 2023-04-05:
@gamecat69 I just made a fresh setup with the firmware 0.8.1 (not calibrated) and your [script](https://raw.githubusercontent.com/gamecat69/EuroPiApps/pot-test/software/contrib/noise_test.py) and I get 0.0 and 1.0 for both knobs and 0.0 for ain. I tested with and without usb power (always with eurorack power). Also I tested to have something constant connected to ain and that shows as well.

gamecat69, 2023-04-05:
Thanks for performing the test @redoxcode. I just did the same test on two modules using two different power supplies.
I got 0.0 and 1.0 values for k1 and k2, but non values > 0.0 for the ain test with nothing connected. I wonder where the ain noise is coming from in my setup....

redoxcode, 2023-04-05:
@gamecat69 can  you try to do the 2 point calibration and see if that helps?
Also maybe reflow the solder on the 3 pins of the socket?
Is the connection to ground working when nothing is connected?

> There was a PR that fixed 2 point calibration (#232)

redoxcode, 2023-08-15:
Closed? As OP hasn't answered and https://github.com/Allen-Synthesis/EuroPi/issues/211#issuecomment-1671746056 is closed as well?

gamecat69, 2023-08-15:
Sorry for the delayed replies. I will test this with the latest firmware
and report back.

Kind Regards,
Nik

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

gamecat69, 2023-08-15:
I have done some testing, but TBH I got lost in PRs and sorta duplicate
issues in the repo :(.

I think that Issue #209 (
https://github.com/Allen-Synthesis/EuroPi/issues/209) should still be open
(see test results below).
However, the other PRs and issues etc that branched off from the original
issue may possibly be closed, but I guess this might be open to
interpretation.

Testing (issue 209)
I calibrated a module running firmware 0.10 and micropython 0.19. I used
the high-precision calibration routine.
My test script (
https://raw.githubusercontent.com/gamecat69/EuroPiApps/pot-test/software/contrib/noise_test.py)
resulted in a pass for the knobs and a very small amount of noise on the
ain (0.000562). I believe for this issue to be resolved the ain should read
0.0 because nothing is connected it should not be providing a non-zero
value.

Kind Regards,
Nik

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

roryjamesallen, 2023-08-21:
>

Out of interest, what happens if you use the same precision for the calibration? i.e. change `calibrate.py` to use 4096 samples rather than 256 for each analogue input read. It is good that we're so so close to 0V, and almost any use of ain will naturally round that down to 0 (6 decimal places would let ain select between far more values than the specification of the EuroPi states based on the bit depth of the ADC), so this small discrepancy could just be down to using a lower number of samples when determining the zero point

roryjamesallen, 2023-08-21:
> a very small amount of noise on the ain (0.000562).

I've just run your noise script on an uncalibrated europi and got exactly 0.0 on ain, haven't yet tried with a calibrated one

gamecat69, 2023-08-22:
I calibrated using 4096 samples and ran the noise_test.py script again.
The results were interesting.... If I calibrate using 4096 samples I get
higher noise (0.03nnn). If I calibrate using 256 samples I get lower noise
(0.00002n).
I also did the test using different cases and I learned that the noise is
slightly different between cases... I therefore suspect that the noise in
my setup might be coming from the power rail, either from the power supply
or from other modules on the same rail....

Either way though.... my original suggestion was for the firmware to make
sure ain reads 0.0 even if the actual value reads as low as 0.00002), thus
eliminating any noise.
If this is not desired though, it is not a major problem. I will simply
continue to make sure that any scripts attempting to detect 0 on ain do
some rounding and the issue can be closed.

Kind Regards,
Nik

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

roryjamesallen, 2023-08-22:
> I get higher noise (0.03nnn). If I calibrate using 256 samples I get lower noise (0.00002n).

That is interesting, it does lean towards some kind of spiked noise then rather than a consistent noise floor, and that would explain more samples having higher noise as it picks up more of the spikes.
Either way, I think that this level of noise is acceptable as noise will be different in every system like you say, so any solution would be imperfect: if we find the average user noise at 256 samples and introduce firmware rounding to make sure that's zero, users with noisy cases will still experience noise at zero, and users with clean cases will have every ain reading slowed down by rounding unnecessarily

roryjamesallen, 2024-01-31:
With no realistic solution possible for this issue which doesn't sacrifice the experience of users with lower noise cases, and with the EuroPi-X development in progress which will fix these noise issues using higher quality ADCs and filtering, I'm going to mark this one closed unless any significant findings or solutions are found.
The Pico ADCs are very noisy, and from what I've read this in large part due to limitations of the ADC itself. Maybe in future this can be "fixed" with config menu settings to raise the voltage level that's considered as zero to account for a noise floor, but it might just be something we have to live with and accept that the hardware of the EuroPi is imperfect

Closed 2024-01-31.

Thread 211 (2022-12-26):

[Project Suggestion] Update calibration routine and implementation

redoxcode, 2022-12-26:
# Update calibration routine and implementation

As mentioned in other issues (e.g. https://github.com/Allen-Synthesis/EuroPi/issues/209) and the discord channel multiple times, the way the calibration works could be improved.
I hope we can use this issue to collect our ideas and requirements and maybe find a good solution together.

I will start with these points:
- As mentioned in (https://github.com/Allen-Synthesis/EuroPi/issues/209) calibration of ain should be at least 2 points (0V and 10V) with multiple samples to account for noise. Especially the 0V measurement will be influenced by noise as the noise can't occur symmetrical around 0 (no values below 0 possible)
- Maybe more people have voltage measurement equipment (multimeter) than rescission voltage sources. So maybe calibrate the outputs first and then use that for the input? Maybe don't use the output to calibrate the input or vice versa?
- Maybe have calibrate all outputs independently? I guess they use the same parts on most builds, but there can still be differences due to the tolerances of the parts or bad connections.

redoxcode, 2023-01-12:
- Maybe we can/should add a compensation for the INL pattern (https://pico-adc.markomo.me/INL-DNL/#why-does-the-dnl-spike) of the ADC used for ain as discussed here: https://github.com/Allen-Synthesis/EuroPi/issues/214

redoxcode, 2023-03-27:
After PR https://github.com/Allen-Synthesis/EuroPi/pull/232 2 point calibration should actually use 0V measurement...

roryjamesallen, 2023-08-09:
I believe this has been fixed with both #232 and #212

Closed 2023-08-09.

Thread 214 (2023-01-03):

ADC problem

georgestheking, 2023-01-03:
The PICO is buggy and has limitation following PICO HARDWARE DATASHEET.
One idea will be to use an external ADC like the MCP3204.

Best regards

Georges

redoxcode, 2023-01-11:
Can you elaborate on how 'the PICO is buggy'?

georgestheking, 2023-01-11:
Hi,
A small problem for the ADC :
https://www.hackster.io/news/raspberry-pi-confirms-it-is-investigating-a-flaw-in-the-raspberry-pi-pico-rp2040-adc-95c393b55dfb

Best regards
Georges

Le mer. 11 janv. 2023 à 22:04, redoxcode ***@***.***> a
écrit :

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

roryjamesallen, 2023-02-12:
I understand the limitations with the inbuilt ADC of the Pico, but it is really too late to fix this now with the current hardware! Future hardware will almost certainly have external ADCs to allow there to be more of them as well, so I'll mark this as closed but know that it's on the list for future hardware improvements!

Closed 2023-02-12.

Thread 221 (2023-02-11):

[Bug Report] AnalogInput calibration improvement when using only two points

francoisgeorgy, 2023-02-11:
Hi,

I think there's a little bug in the way the voltage is computed when the calibration has been done with only two point (0 and 10).

In AnalogueInput.read_voltage() the code :

    cv = 10 * (reading / INPUT_CALIBRATION_VALUES[-1])

should take `INPUT_CALIBRATION_VALUES[0]` into account and becomes :

    cv = 10 * ((reading - - INPUT_CALIBRATION_VALUES[0]) / (INPUT_CALIBRATION_VALUES[-1] - INPUT_CALIBRATION_VALUES[0]))

This is especially important when reading low voltage. If, for example, we have :

    INPUT_CALIBRATION_VALUES = [384, 44634]

The result, with `reading = 384` is

    # current code:
    cv = 10 * (384 / 44634) = 0.08603306896088184

    # new code:
    cv = 10 * ((384 - 384) / (44634 - 384)) = 0.0

And with `reading = 44634` :

    # current code:
    cv = 10 * (44634 / 44634) = 10.0

    # new code:
    cv = 10 * ((44634 - 384) / (44634 - 384)) = 10.0

We can see that the 0V computation (with reading=384) is now correct and that the max voltage is not affected.

A similar issue is present in AnalogueInput.percent() :

current code :

    max_value = max(reading, INPUT_CALIBRATION_VALUES[-1])

proposed correction :

    max_value = max(reading, (INPUT_CALIBRATION_VALUES[-1] - INPUT_CALIBRATION_VALUES[0]))

What do you think? Am I correct?

redoxcode, 2023-02-26:
I think you're right! Good catch! I never looked at the actual implementation of the calibration before.
I made a fork that should fix the issue in all relevant places:
https://github.com/redoxcode/EuroPi/blob/calibration-fix/software/firmware/europi.py
Maybe you can double check these changes for me before I open a PR?

(some tests still fail, but it's only one contrib script (tests/contrib/test_europi_turing_machine.py) so I guess it's an issue of this test and not the code changes)

francoisgeorgy, 2023-02-27:
Your fix looks good to me. Thank you very much for your time. I could have opened a PR.

I don't have the time to run the tests and test with my EuroPi today but can do it in a few days if you want. But, your code is fine and I don't see any problem.

redoxcode, 2023-02-28:
created the PR https://github.com/Allen-Synthesis/EuroPi/pull/232
Even if I haven't calibrated my modules yet, I am very interested in improving the Ain and Output accuracy, since it opens up more use cases for the europi.

mjaskula, 2023-03-02:
I took a quick look at the test failures and didn't see anything obvious. I'll look again after some other priorities.

Closed 2023-03-19.

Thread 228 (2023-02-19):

[Bug Report] Unable to calibrate

Salvadi, 2023-02-19:
I'm unable to calibrate the Europi with mode 1. The calibration gets stuck at "Calibrating..." after plugging the 10V source into the analogue input.
The Europi was loaded with the the precompiled firmware from the "Quick start" section.

However programming the Europi with Thonny IDE I can calibrate with no problems at all.

**To Reproduce**
Steps to reproduce the behavior:
1. Program the Europi as per the "Quick start" section
2. Click on 'Calibrate'
3. Select 'Mode 1'
4. Get stuck at 'Calibrating...'

**Expected behavior**
Get to the 'Insert analogue input into CV1' calibration step.

redoxcode, 2023-02-20:
Working on a fix here: https://github.com/Allen-Synthesis/EuroPi/pull/229

awonak, 2023-02-26:
Fixed in #229

Closed 2023-02-26.

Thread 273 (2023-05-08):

Pico W?

toneburst, 2023-05-08:
More of a question than an issue really: is the RPi Pico W able to be used as a drop-in replacement for the non-W variant?

Obviously it would use more power, if so…

toneburst, 2023-05-14:
Cool. Let me know how it goes!

I haven’t checked, but my suspicion is that the power requirements of the W variant may be significantly higher.

May or may not be a problem for the module’s transformer.

roryjamesallen, 2023-06-03:
> More of a question than an issue really: is the RPi Pico W able to be used as a drop-in replacement for the non-W variant?
>
> Obviously it would use more power, if so…

Yes, the Pico W can be used very safely as a drop in replacement for a normal Pico!

Although it might draw slightly more, the 5V regulator on the EuroPi is really an overkill solution, so even though the entire module only draws around 90mA from the +12V rail, the regulator is capable of more than *>500mA* so if the W really needs more it will still be available to it

Closed 2023-06-03.

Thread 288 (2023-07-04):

C1 & C2

georgestheking, 2023-07-04:
C1 & C2 must be ceramic capacitor.
See the 7805 datasheet.

Best regards

Georges

roryjamesallen, 2023-07-19:
Fixed in #286

Closed 2023-07-19.

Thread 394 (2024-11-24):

Stabilize CV input with additional 1nF capacitor?

chrisib, 2024-11-24:
# Hardware Issue

A user reported on Discord that adding a 1uF capacitor in parallel with R23 improves the accuracy of the ADC, resulting in more accurate calibration.

Proposed modified input stage, adding `C*`:
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

This modification appears to match the original input stage, for example the one found in Braids:
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

# Planned Experiment

I've ordered some extra capacitors (I don't have any 1nF caps on-hand right now) and plan on modifying one of my EuroPis to include the proposed change.  Then I'll send in fixed voltages to AIN and record the raw PWM readings over some period of time, and compare the variance before & after the modification to see how much of a difference this really makes.

chrisib, 2024-11-24:
Started recording the data. I'm still waiting for the capacitors (I only ordered them yesterday, but they should arrive this week).

https://docs.google.com/spreadsheets/d/1rbvg_A5ZrKb3OqOu_JKJJ7-fPOTPx5xrRCnM5VENmN4/edit?usp=sharing

Script to generate the source data:
```python
from europi import ain, b1, oled
from time import sleep

def main():
    def wait_for_b1(value):
        while b1.value() != value:
            sleep(0.05)

    for volts in range(11):
        oled.centre_text(f'Connect {volts}V\nPress B1')
        wait_for_b1(1)

        with open(f'{volts}_v.csv', 'w') as fout:
            fout.write(f'{volts}V\n')
            for i in range(1000):
                duty = ain.pin.read_u16()
                fout.write(f'{duty}\n')
        
        wait_for_b1(0)
    
    oled.centre_text('Done')

if __name__ == '__main__':
    main()
```

civerachb-cpr, 2024-11-27:
Got my extra capacitors and added the 1nF to the back-side of the board, connected directly to the ends of R23.  Re-ran the code above. Results added to https://docs.google.com/spreadsheets/d/1rbvg_A5ZrKb3OqOu_JKJJ7-fPOTPx5xrRCnM5VENmN4/edit?usp=sharing

Interestingly at 0V the noise in the duty cycle actually seemed to go up. Could be a random event; we're not dealing with a lot of trials, so data's going to be subject to some variance.  But for all values above 0V, the standard deviation dropped by about half, which indicates much less noise in the duty cycle.

I'm tentatively willing to call the experiment a success, though the extra noise at 0V is worth investigating further.

If anyone else wants to repeat this experiment and post their results, I'd love to see the results of more data across a wider range of modules.

chrisib, 2024-11-28:
Got my extra capacitors and added the 1nF to the back-side of the board, connected directly to the ends of R23. Re-ran the code above. Results added to https://docs.google.com/spreadsheets/d/1rbvg_A5ZrKb3OqOu_JKJJ7-fPOTPx5xrRCnM5VENmN4/edit?usp=sharing

Interestingly at 0V the noise in the duty cycle actually seemed to go up. Could be a random event; we're not dealing with a lot of trials, so data's going to be subject to some variance. But for all values above 0V, the standard deviation dropped by about half, which indicates much less noise in the duty cycle.

I'm tentatively willing to call the experiment a success, though the extra noise at 0V is worth investigating further.

If anyone else wants to repeat this experiment and post their results, I'd love to see the results of more data across a wider range of modules.

chrisib, 2024-11-28:
Photos showing the 1nF capacitor soldered directly to the legs of R23; this is easiest if you have not cut the legs on the resistor too short.

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

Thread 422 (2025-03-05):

[Bug Report] "About" script is broken in V0.18.0

WavyDavy1960, 2025-03-05:
# Bug Report

**Describe the bug**
In version 0.18.0
"About" script is broken, and locks up EuroPi when you press button #1 or #2.
 And it does not display version information.

**To Reproduce**
Steps to reproduce the behavior:
1. Go to 'About'
2. Click on 'button #1 or #2'
3. no version information is displayed.
4. EuroPi is disabled, no button press or knob turning will work, until EuroPi is powered off, and then on again.

**Expected behavior**
Pressing button #2 should display firmware version.
**Images**
If applicable, add screenshots or photos to help explain your problem.

**Additional context**
Add any other context about the problem here.

chrisib, 2025-03-05:
Can you please provide the contents of `last_crash.txt` (if it exists) as well as `config/EuroPiConfig.json` and `config/ExperimentalConfig.json`?

WavyDavy1960, 2025-03-06:
I installed the V0.18.0 firmware/scripts, using the method involving powering up the EuroPi module, while holding down the small white button on the back of the module, and then dragging and dropping the firmware into the folder.
I don’t know how to install individual modules, or retrieve the files you requested.

I would welcome a link to directions on how to install individual modules, and how to retrieve the requested documents.

I am also interested in how to retain the calibration information, so I don’t have to recalibrate, each time I update the firmware/scripts.

I enjoyed building and using the EuroPi modules.
Thanks much for your work on this project.
DA
VE

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

chrisib, 2025-03-06:
Ah, ok. Rather than using the quickstart method using the all-in-one UF2 method, it's often more reliable to use the Thonny method described [here](https://github.com/Allen-Synthesis/EuroPi/blob/main/software/programming_instructions.md#pico-setup).

1. Use flash-nuke like you did initially to wipe the Pico
2. Download and install the Micropython firmware (a UF2 file) from https://micropython.org/download/RPI_PICO/ (if you are using a Pico W, Pico 2, or Pico 2 W there are alternative UF2 files for those -- make sure to download the correct one)
3. Install Thonny on your computer
4. Connect the Pico to your computer via the USB cable
5. Use Thonny's package manager to install the `ssd1306`, `micropython-europi` and `micropython-europi-contrib` packages onto the Pico

WavyDavy1960, 2025-03-06:
Hi Chris,
I need advice about the following error…
I believe I have a clone Raspberry Pi. It only says Raspberry Pi ©️ 2020, on the circuit board.
I am using the latest version of Thony downloaded from their website yesterday.
Using a Mac Mini with OS 12.7.6 (21H1320)

After following all instructions, in the link provided, I get stuck at the step where I try to install the ssd1306.
I tried with “MicroPython (Raspberry Pi Picco) Board in FS mode @ /de/cu.usbmodem14101”
I also tried with “MicroPython (RP2040) Board in FS mode @ /de/cu.usbmodem14101”
Selected in the lower right corner of Thony.
I am using the latest version of Thony downloaded from their website yesterday.
Using a Mac Mini with OS 12.7.6 (21H1320)

After clicking install, and waiting for a while, I get an error message as follows:

install --progress-bar off micropython-ssd1306
Looking in indexes: http://127.0.0.1:36628
WARNING: Retrying (Retry(total=4, connect=None, read=None, redirect=None, status=None)) after connection broken by 'ReadTimeoutError("HTTPConnectionPool(host='127.0.0.1', port=36628): Read timed out. (read timeout=15)")': /micropython-ssd1306/
WARNING: Retrying (Retry(total=3, connect=None, read=None, redirect=None, status=None)) after connection broken by 'ReadTimeoutError("HTTPConnectionPool(host='127.0.0.1', port=36628): Read timed out. (read timeout=15)")': /micropython-ssd1306/
WARNING: Retrying (Retry(total=2, connect=None, read=None, redirect=None, status=None)) after connection broken by 'ReadTimeoutError("HTTPConnectionPool(host='127.0.0.1', port=36628): Read timed out. (read timeout=15)")': /micropython-ssd1306/
127.0.0.1 - - [06/Mar/2025 11:56:13] "GET /micropython-ssd1306/ HTTP/1.1" 200 -
127.0.0.1 - - [06/Mar/2025 11:56:13] "GET /micropython-ssd1306/ HTTP/1.1" 200 -
----------------------------------------
Exception occurred during processing of request from ('127.0.0.1', 58065)
Traceback (most recent call last):
  File "/Applications/Thonny.app/Contents/Frameworks/Python.framework/Versions/3.10/lib/python3.10/socketserver.py", line 316, in _handle_request_noblock
    self.process_request(request, client_address)
  File "/Applications/Thonny.app/Contents/Frameworks/Python.framework/Versions/3.10/lib/python3.10/socketserver.py", line 347, in process_request
    self.finish_request(request, client_address)
  File "/Applications/Thonny.app/Contents/Frameworks/Python.framework/Versions/3.10/lib/python3.10/socketserver.py", line 360, in finish_request
    self.RequestHandlerClass(request, client_address, self)
  File "/Applications/Thonny.app/Contents/Frameworks/Python.framework/Versions/3.10/lib/python3.10/site-packages/thonny/vendored_libs/pipkin/proxy.py", line 586, in __init__
    super().__init__(request, client_address, server)
  File "/Applications/Thonny.app/Contents/Frameworks/Python.framework/Versions/3.10/lib/python3.10/socketserver.py", line 747, in __init__
    self.handle()
  File "/Applications/Thonny.app/Contents/Frameworks/Python.framework/Versions/3.10/lib/python3.10/http/server.py", line 433, in handle
    self.handle_one_request()
  File "/Applications/Thonny.app/Contents/Frameworks/Python.framework/Versions/3.10/lib/python3.10/http/server.py", line 421, in handle_one_request
    method()
  File "/Applications/Thonny.app/Contents/Frameworks/Python.framework/Versions/3.10/lib/python3.10/site-packages/thonny/vendored_libs/pipkin/proxy.py", line 595, in do_GET
    self._serve_distribution_page(path)
  File "/Applications/Thonny.app/Contents/Frameworks/Python.framework/Versions/3.10/lib/python3.10/site-packages/thonny/vendored_libs/pipkin/proxy.py", line 613, in _serve_distribution_page
    self.wfile.write("<!DOCTYPE html><html><body>\n".encode(SERVER_ENCODING))
  File "/Applications/Thonny.app/Contents/Frameworks/Python.framework/Versions/3.10/lib/python3.10/socketserver.py", line 826, in write
    self._sock.sendall(b)
ConnectionResetError: [Errno 54] Connection reset by peer
----------------------------------------
127.0.0.1 - - [06/Mar/2025 11:56:13] "GET /micropython-ssd1306/ HTTP/1.1" 200 -
----------------------------------------
Exception occurred during processing of request from ('127.0.0.1', 58086)
Traceback (most recent call last):
  File "/Applications/Thonny.app/Contents/Frameworks/Python.framework/Versions/3.10/lib/python3.10/socketserver.py", line 316, in _handle_request_noblock
    self.process_request(request, client_address)
  File "/Applications/Thonny.app/Contents/Frameworks/Python.framework/Versions/3.10/lib/python3.10/socketserver.py", line 347, in process_request
    self.finish_request(request, client_address)
  File "/Applications/Thonny.app/Contents/Frameworks/Python.framework/Versions/3.10/lib/python3.10/socketserver.py", line 360, in finish_request
    self.RequestHandlerClass(request, client_address, self)
  File "/Applications/Thonny.app/Contents/Frameworks/Python.framework/Versions/3.10/lib/python3.10/site-packages/thonny/vendored_libs/pipkin/proxy.py", line 586, in __init__
    super().__init__(request, client_address, server)
  File "/Applications/Thonny.app/Contents/Frameworks/Python.framework/Versions/3.10/lib/python3.10/socketserver.py", line 747, in __init__
    self.handle()
  File "/Applications/Thonny.app/Contents/Frameworks/Python.framework/Versions/3.10/lib/python3.10/http/server.py", line 433, in handle
    self.handle_one_request()
  File "/Applications/Thonny.app/Contents/Frameworks/Python.framework/Versions/3.10/lib/python3.10/http/server.py", line 421, in handle_one_request
    method()
  File "/Applications/Thonny.app/Contents/Frameworks/Python.framework/Versions/3.10/lib/python3.10/site-packages/thonny/vendored_libs/pipkin/proxy.py", line 595, in do_GET
    self._serve_distribution_page(path)
  File "/Applications/Thonny.app/Contents/Frameworks/Python.framework/Versions/3.10/lib/python3.10/site-packages/thonny/vendored_libs/pipkin/proxy.py", line 615, in _serve_distribution_page
    self.wfile.write(
  File "/Applications/Thonny.app/Contents/Frameworks/Python.framework/Versions/3.10/lib/python3.10/socketserver.py", line 826, in write
    self._sock.sendall(b)
BrokenPipeError: [Errno 32] Broken pipe
----------------------------------------
127.0.0.1 - - [06/Mar/2025 11:56:13] "GET /micropython-ssd1306/ HTTP/1.1" 200 -
Collecting micropython-ssd1306
  WARNING: Retrying (Retry(total=4, connect=None, read=None, redirect=None, status=None)) after connection broken by 'ReadTimeoutError("HTTPConnectionPool(host='127.0.0.1', port=36628): Read timed out. (read timeout=15)")': /micropython-ssd1306/micropython-ssd1306-0.3.tar.gz/
127.0.0.1 - - [06/Mar/2025 11:56:41] "GET /micropython-ssd1306/micropython-ssd1306-0.3.tar.gz/ HTTP/1.1" 200 -
  WARNING: Retrying (Retry(total=3, connect=None, read=None, redirect=None, status=None)) after connection broken by 'ReadTimeoutError("HTTPConnectionPool(host='127.0.0.1', port=36628): Read timed out. (read timeout=15)")': /micropython-ssd1306/micropython-ssd1306-0.3.tar.gz/
  WARNING: Retrying (Retry(total=2, connect=None, read=None, redirect=None, status=None)) after connection broken by 'ReadTimeoutError("HTTPConnectionPool(host='127.0.0.1', port=36628): Read timed out. (read timeout=15)")': /micropython-ssd1306/micropython-ssd1306-0.3.tar.gz/
127.0.0.1 - - [06/Mar/2025 11:57:09] "GET /micropython-ssd1306/micropython-ssd1306-0.3.tar.gz/ HTTP/1.1" 200 -
  WARNING: Retrying (Retry(total=1, connect=None, read=None, redirect=None, status=None)) after connection broken by 'ReadTimeoutError("HTTPConnectionPool(host='127.0.0.1', port=36628): Read timed out. (read timeout=15)")': /micropython-ssd1306/micropython-ssd1306-0.3.tar.gz/
  WARNING: Retrying (Retry(total=0, connect=None, read=None, redirect=None, status=None)) after connection broken by 'ReadTimeoutError("HTTPConnectionPool(host='127.0.0.1', port=36628): Read timed out. (read timeout=15)")': /micropython-ssd1306/micropython-ssd1306-0.3.tar.gz/
127.0.0.1 - - [06/Mar/2025 11:57:37] "GET /micropython-ssd1306/micropython-ssd1306-0.3.tar.gz/ HTTP/1.1" 200 -
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
chrisib, 2025-03-07:
That looks like it may be a bug with Thonny. What version are you using, and does your Mac Mini have working internet connection?

If that problem persists you might want to reach out to the Thonny developers, as that doesn't look like normal behaviour.

Regarding the Pico, if it's a 2020 board it's likely either a standard Pico or a clone thereof. Some users have reported QC issues with third-party Pico clones, so it's possible that if your board is also a clone that there are hard-to-diagnose hardware or quality-control problems. That seems unlikely if some scripts work fine, but it's not out of the realm of possibility.

WavyDavy1960, 2025-03-07:
Hi Chris,
Disregard my previous email from earlier today.
I want to report that I was successful at installing the firmware and scripts, after closing my memory hogging browser, and restarting my computer.
I then tested the _About script, and it worked as expected, displaying the correct version of installed scripts.

Thanks for your help, answering questions.
And thanks again for all your contributions to the EuroPi project
Have a great day
DA
VE

> On Mar 5, 2025, at 8:27 PM, Chris I-B ***@***.***> wrote:
>
> here <https://github.com/Allen-Synthesis/EuroPi/blob/main/software/programming_instructions.md#pico-setup>

chrisib, 2025-03-07:
Great! Glad it's working for you!

Closed 2025-03-07.

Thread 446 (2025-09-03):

Encoder Error?

Cyantig, 2025-09-03:
# Hardware Issue

I am having problems with my left pot
 only moving one step forward or one step back and I can't scroll in the menu. I am able to enter and exit programs. Any idea on what the problem could be? I did check my soldering job before posting.

CT

chrisib, 2025-09-03:
Sorry to year you're having problems with your module!

Did the encoder previously work correctly and then stop, or has it never worked correctly?

Can you please try connecting the module to your computer via the USB cable and open Thonny. In Thonny's MicroPython terminal at the bottom of the window, please try running the following commands:

```python
from europi import k1

# rotate the knob all the way to the left
k1.percent()

# rotate the knob so it's close to vertical
k1.percent()

# rotate the knob all the way to the right
k1.percent()
```

These should output `0.0` followed by `0.5` and finally `1.0` (plus or minus a little bit of error).

Then try running

```python

# rotate the knob all the way to the left
k1._sample_adc(samples=128)

# rotate the knob all the way to the right
k1._sample_adc(samples=128)
```

That should help provide some insight into what could be going wrong.

Cyantig, 2025-09-07:
MicroPython v1.25.0-dirty on 2025-07-01; Raspberry Pi Pico2 with RP2350
Type "help()" for more information.
>>> from europi import k1
>>> # rotate the knob all the way to the left
k1.percent()
0.0
>>> # rotate the knob so it's close to vertical
k1.percent()
0.5340312
>>> # rotate the knob all the way to the right
k1.percent()

1.0
>>>
---------------------------------------------
>>> # rotate the knob all the way to the left
k1._sample_adc(samples=128)
65535
>>> # rotate the knob all the way to the right
k1._sample_adc(samples=128)
36
>>>
---------------------------------------------

Here is the output of the commands that you requested.  I installed the firmware from the all-in-one GitHub release.

CT

chrisib, 2025-09-07:
That looks good to me.

One thing I just realized: when navigating the menu you should be using `k2`, not `k1`. Can you verify that you can scroll through the menu by rotating the knob on the right?

Cyantig, 2025-09-07:
The behavior I am seeing on the right encoder gives no response at all in the menu. The only action I am getting at all is one step forward and one step back on the left  encoder.

chrisib, 2025-09-07:
Well, that looks to be the problem. It seems like it's probably a hardware issue. Can you please:

1. Measure the resistance of the potentiometer in the same 3 positions (all the way to the left, centre, all the way to the right). On my sample I measure 9.59kΩ all the way to the left, 5.24kΩ in the centre and 1.2Ω all the way to the right. Basically 0-10k across the full range of the pot.
2. Make sure you don't have any shorts between the 3 legs of the pot.
3. Make sure you have a good connections between the 3.3V pin on the Pico to one side leg of the pot, ground and the other side leg of the pot, and a between the centre leg of the pot and GP28 on the Pico

Hopefully it's an easy fix and there's just a solder bridge somewhere in the circuit path. At worst the potentiometer may be faulty and need replacing.

Cyantig, 2025-09-08:
So it looks like the 3v3 and ground lines are ok.

So pot k1 seems to be labeled B10K measuring out at 5K-0k from the wiper, k2 seems to have a broken wiper as I am not measuring anything at all on it but 5K across the whole thing.

I am going to go ahead a replace them both with some 10k and hopefully this will resolve any issues going forward.

Are you able to provide me with a part number that I could look up at Digikey?

CT

Closed 2025-09-08.

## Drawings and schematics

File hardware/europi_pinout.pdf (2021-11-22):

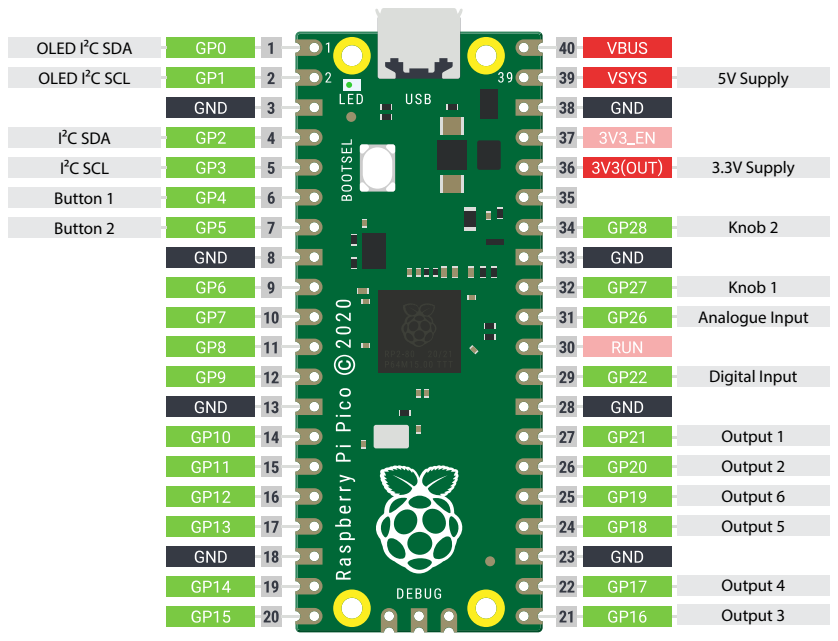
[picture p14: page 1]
5V Supply; 3.3V Supply; Knob 2; Knob 1 Analogue Input; Digital Input; Output 1 Output 2 Output 6 Output 5; Output 4 Output 3; Button 1 Button 2; I²C SDA I²C SCL

OLED I²C SDA
OLED I²C SCL

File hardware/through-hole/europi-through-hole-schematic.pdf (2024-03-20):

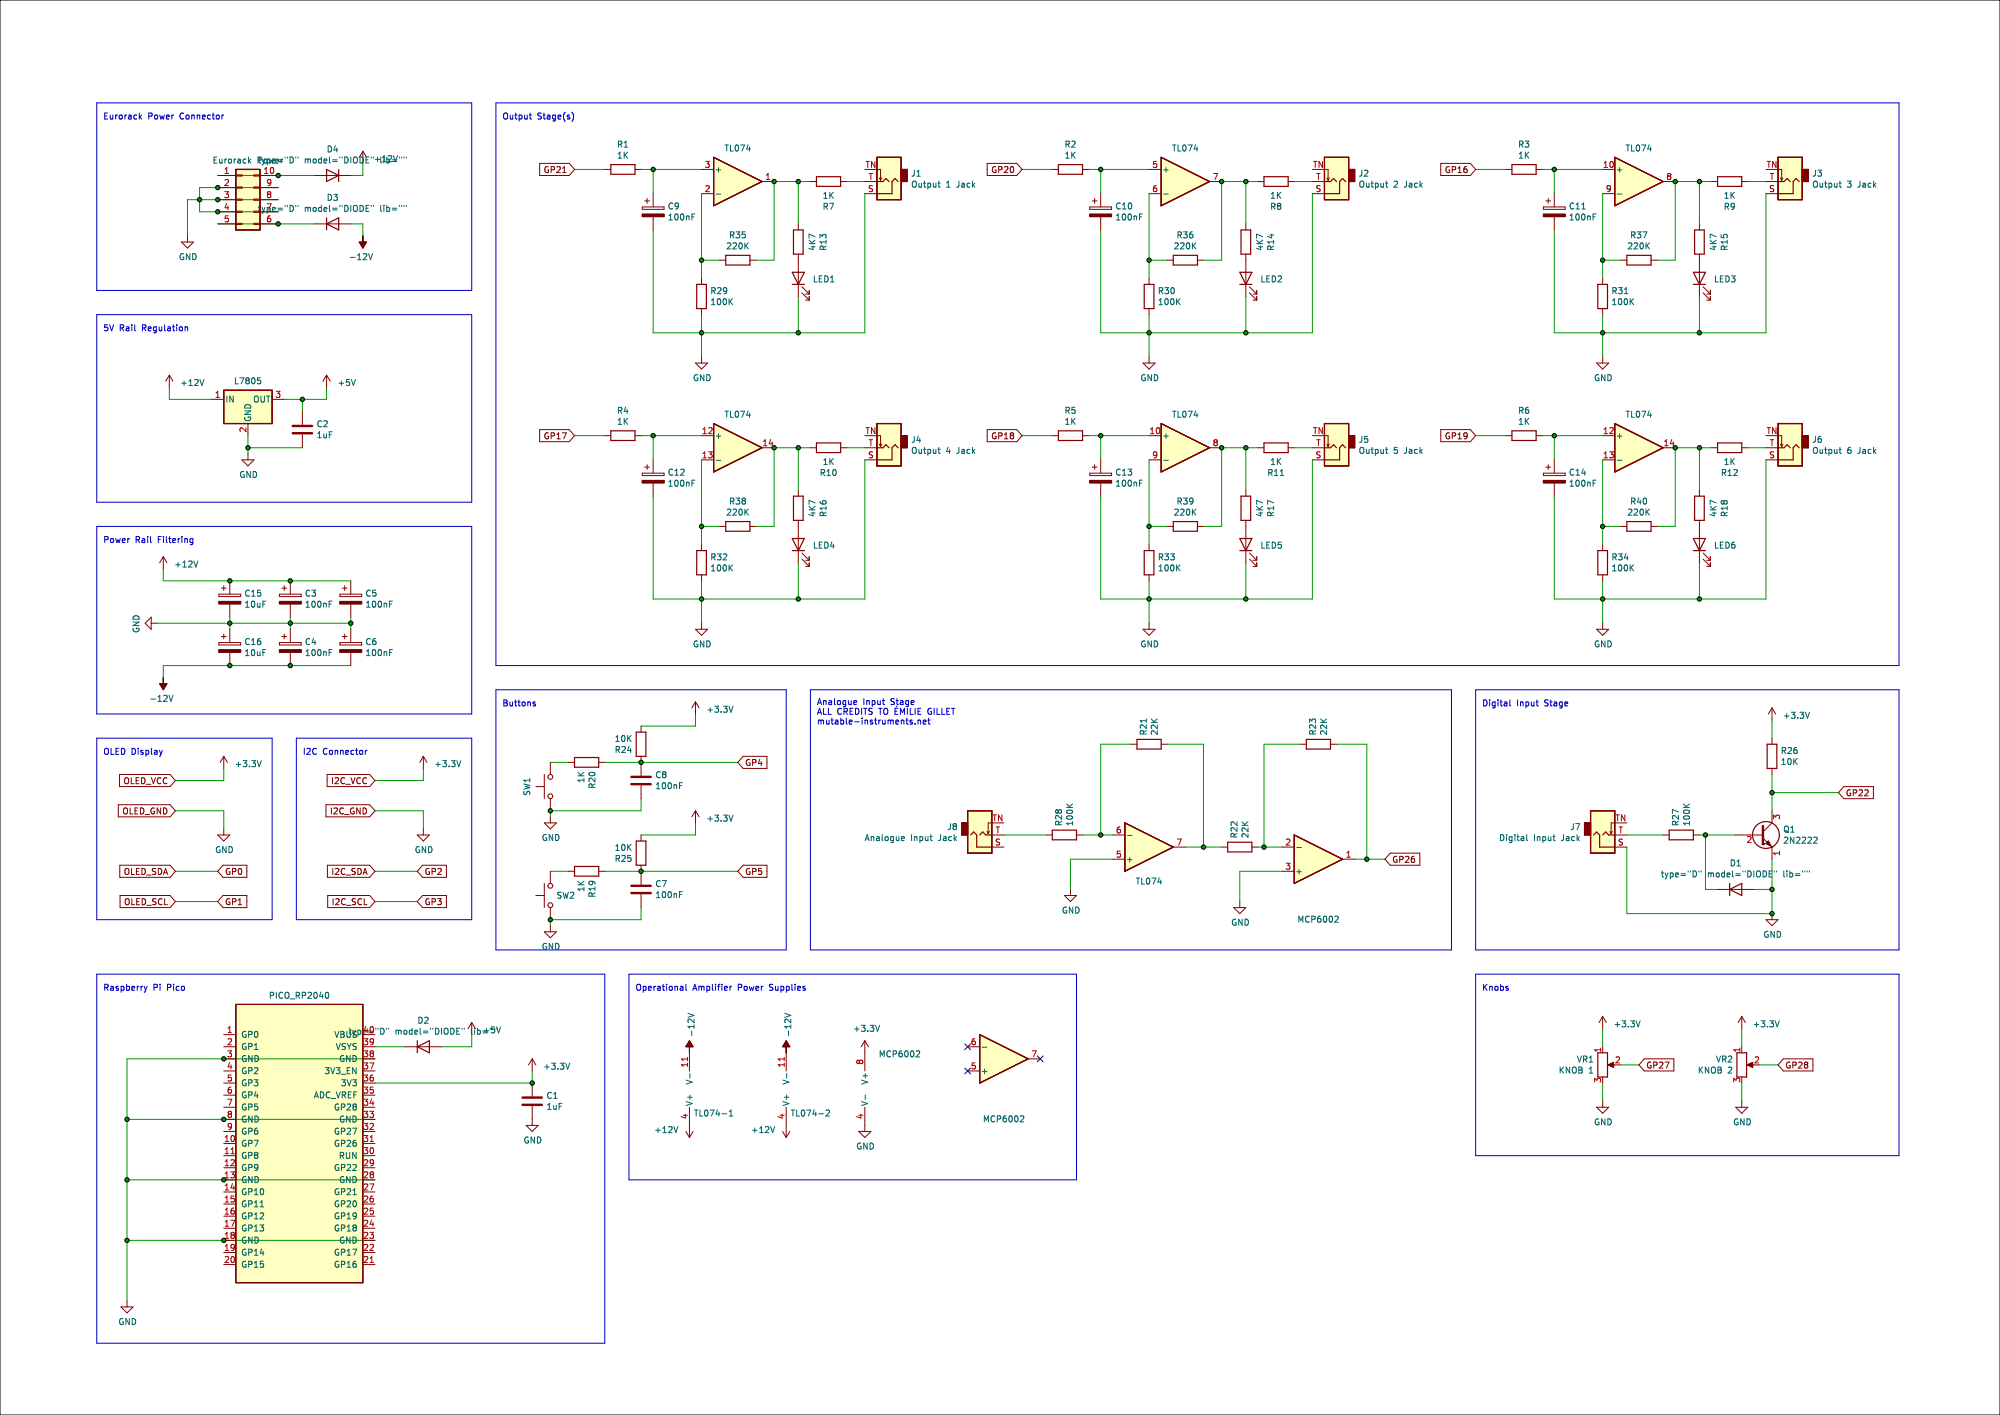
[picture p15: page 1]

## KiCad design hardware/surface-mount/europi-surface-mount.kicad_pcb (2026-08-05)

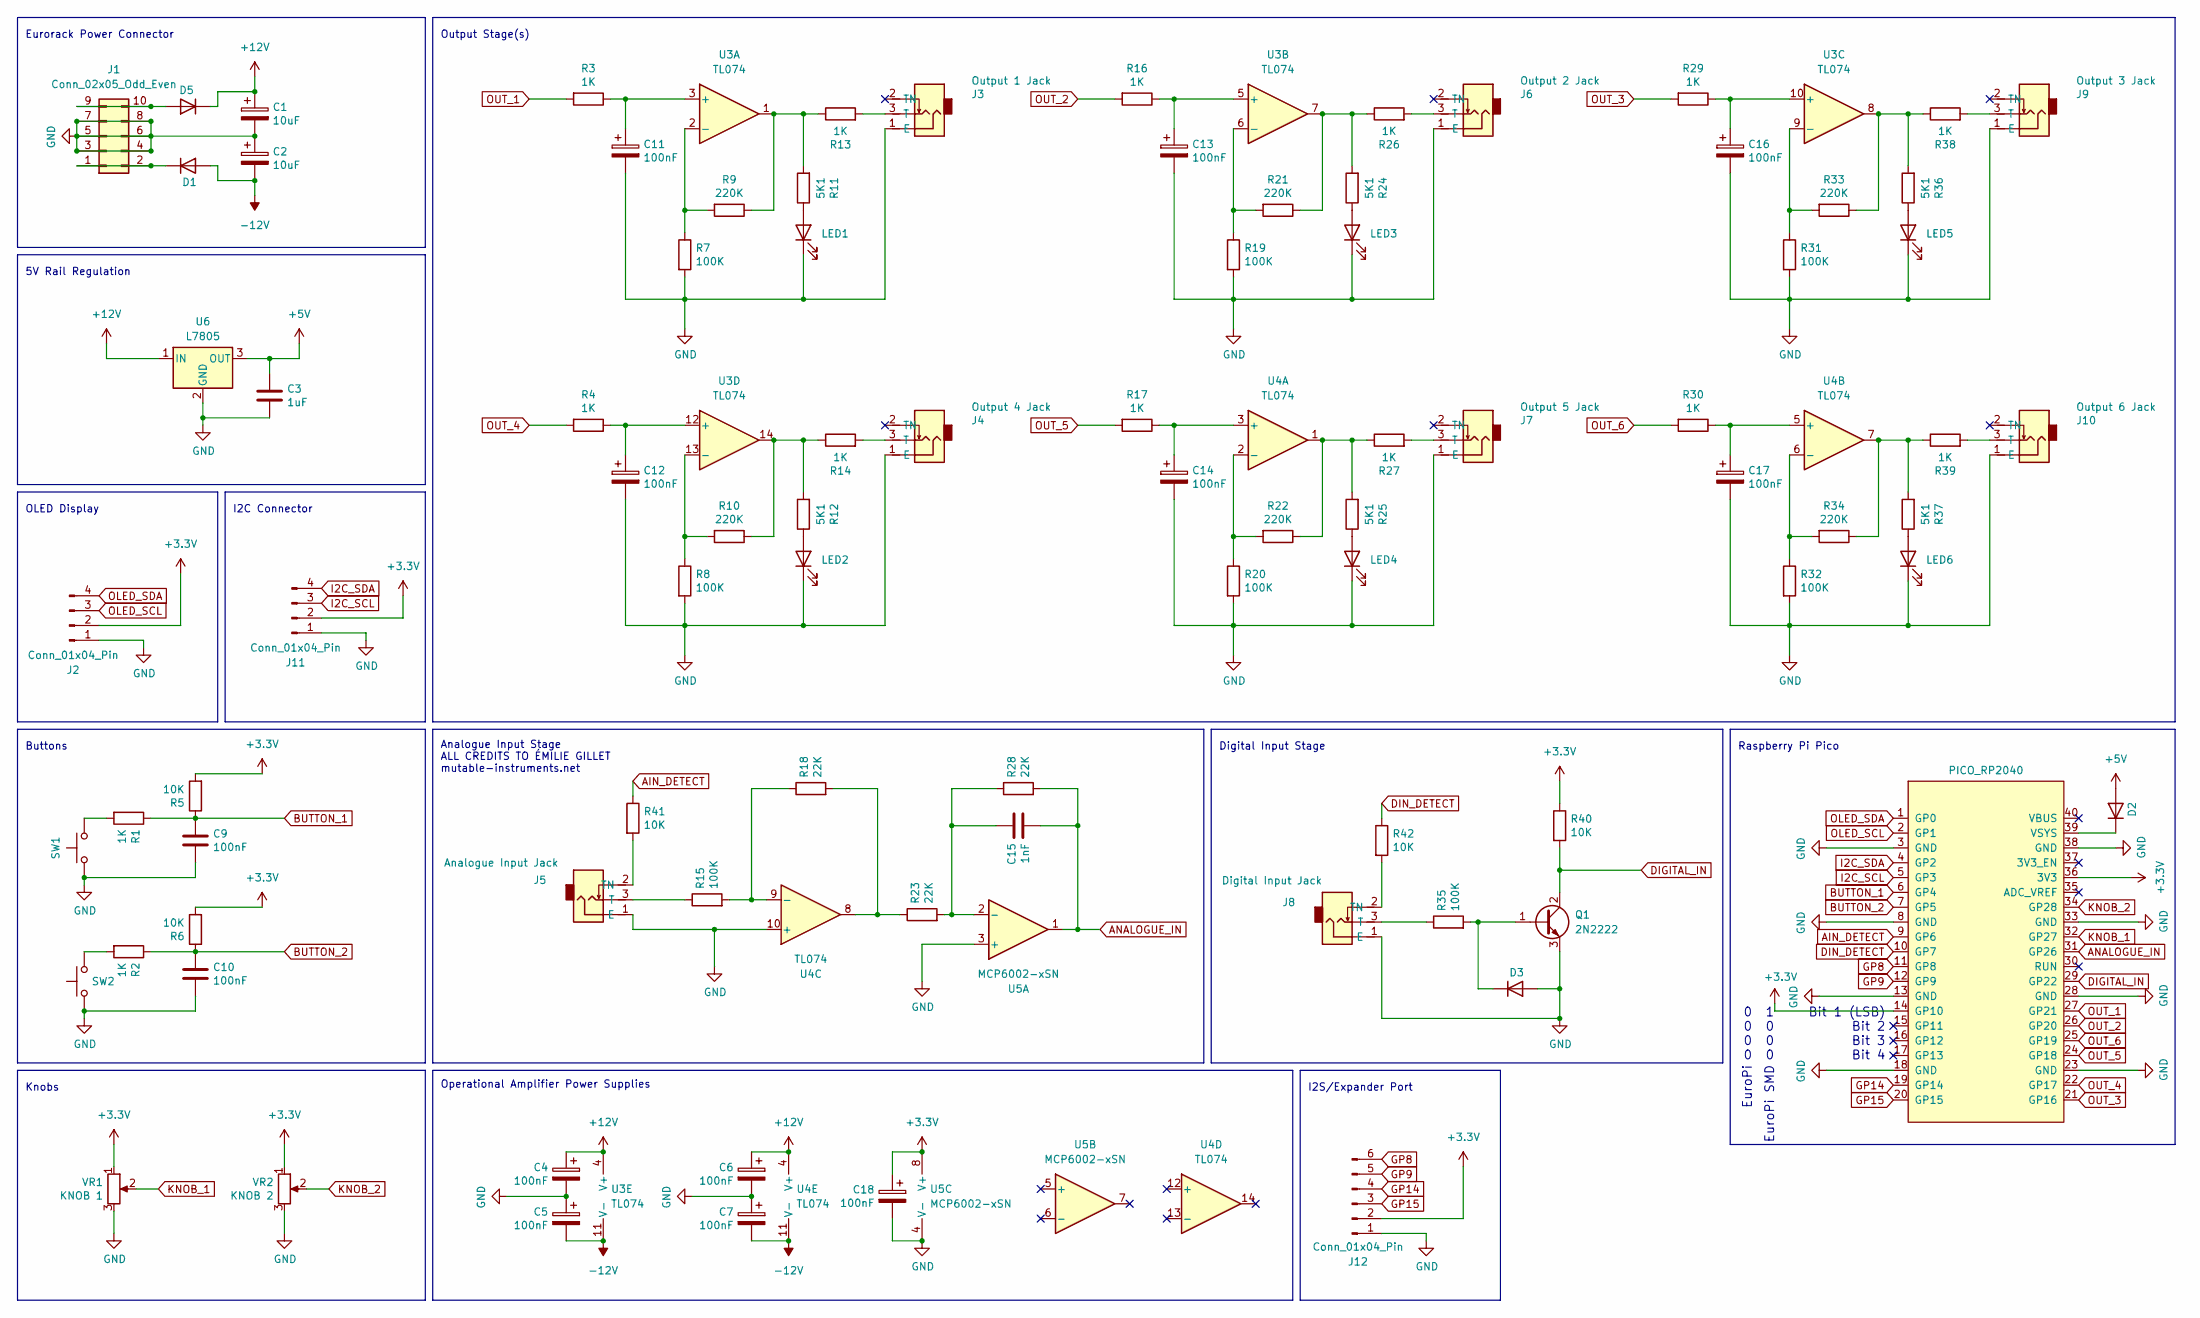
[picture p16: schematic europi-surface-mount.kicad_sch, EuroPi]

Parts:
C1, C2: 10uF; C_0805_2012Metric
C3: 1uF; C_0603_1608Metric
C4, C5, C6, C7, C9, C10, C11, C12, C13, C14, C16, C17, C18: 100nF; C_0603_1608Metric
C15: 1nF; C_0603_1608Metric
D1, D2, D5: D; D_SMA; LCSC Part C5356810
D3: D; D_SMA; LCSC Part C5148475
J1: Conn_02x05_Odd_Even; power-header-10-pin-unlabelled
J2: Conn_01x04_Pin; PinHeader_1x04_P2.54mm_Vertical
J3: Output 1 Jack; jack-thonkiconn-mono
J4: Output 4 Jack; jack-thonkiconn-mono
J5: Analogue Input Jack; jack-thonkiconn-mono
J6: Output 2 Jack; jack-thonkiconn-mono
J7: Output 5 Jack; jack-thonkiconn-mono
J8: Digital Input Jack; jack-thonkiconn-mono
J9: Output 3 Jack; jack-thonkiconn-mono
J10: Output 6 Jack; jack-thonkiconn-mono
J11: Conn_01x04_Pin; JST_PH_B4B-PH-K_1x04_P2.00mm_Vertical
J12: Conn_01x04_Pin; JST_PH_B6B-PH-K_1x06_P2.00mm_Vertical
LED1, LED2, LED3, LED4, LED5, LED6: LED; led-3mm
Q1: 2N2222; SOT-89-3; LCSC Part C21714170
R1, R2, R3, R4, R13, R14, R16, R17, R26, R27, R29, R30, R38, R39: 1K; R_0603_1608Metric
R5, R6, R40, R41, R42: 10K; R_0603_1608Metric
R7, R8, R15, R19, R20, R31, R32, R35: 100K; R_0603_1608Metric
R9, R10, R21, R22, R33, R34: 220K; R_0603_1608Metric
R11, R12, R24, R25, R36, R37: 5K1; R_0603_1608Metric
R18, R23, R28: 22K; R_0603_1608Metric
SW1, SW2: SW_Push; switch-momentary-c&k
U2: PICO_RP2040; raspberry-pi-pico
U3, U4: TL074; SOIC-14_3.9x8.7mm_P1.27mm; LCSC Part C6963
U5: MCP6002-xSN; SOIC-8_3.9x4.9mm_P1.27mm; LCSC Part C7377
U6: L7805; TO-252-2; LCSC Part C7394043
VR1: KNOB 1; potentiometer-9mm
VR2: KNOB 2; potentiometer-9mm

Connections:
+3.3V: C18.1, J2.2, J11.2, J12.2, R5.2, R6.2, R40.1, U2.14 (GP10), U2.36 (3V3), U5.8 (V+), VR1.1, VR2.1
+5V: C3.1, D2.2 (A), U6.3 (OUT)
+12V: C1.1, C4.1, C6.1, D5.1 (K), U3.4 (V+), U4.4 (V+), U6.1 (IN)
-12V: C2.2, C5.2, C7.2, D1.2 (A), U3.11 (V-), U4.11 (V-)
AIN_DETECT: R41.1, U2.9 (GP6)
ANALOGUE_IN: C15.2, R28.2, U2.31 (GP26), U5.1
BUTTON_1: C9.1, R1.1, R5.1, U2.6 (GP4)
BUTTON_2: C10.1, R2.1, R6.1, U2.7 (GP5)
DIGITAL_IN: Q1.2 (C), R40.2, U2.29 (GP22)
DIN_DETECT: R42.1, U2.10 (GP7)
GND: C1.2, C2.1, C3.2, C4.2, C5.1, C6.2, C7.1, C9.2, C10.2, C11.2, C12.2, C13.2, C14.2, C16.2, C17.2, C18.2, D3.2 (A), J1.3, J1.4, J1.5, J1.6, J1.7, J1.8, J2.1, J3.1 (E), J4.1 (E), J5.1 (E), J6.1 (E), J7.1 (E), J8.1 (E), J9.1 (E), J10.1 (E), J11.1, J12.1, LED1.1 (K), LED2.1 (K), LED3.1 (K), LED4.1 (K), LED5.1 (K), LED6.1 (K), Q1.3 (E), R7.2, R8.2, R19.2, R20.2, R31.2, R32.2, SW1.1, SW2.1, U2.3 (GND), U2.8 (GND), U2.13 (GND), U2.18 (GND), U2.23 (GND), U2.28 (GND), U2.33 (GND), U2.38 (GND), U4.10 (+), U5.3 (+), U5.4 (V-), U6.2 (GND), VR1.3, VR2.3
GP8: J12.6, U2.11 (GP8)
GP9: J12.5, U2.12 (GP9)
GP14: J12.4, U2.19 (GP14)
GP15: J12.3, U2.20 (GP15)
I2C_SCL: J11.3, U2.5 (GP3)
I2C_SDA: J11.4, U2.4 (GP2)
KNOB_1: U2.32 (GP27), VR1.2
KNOB_2: U2.34 (GP28), VR2.2
unnamed: D1.1 (K), J1.1, J1.2
unnamed: D2.1 (K), U2.39 (VSYS)
unnamed: D3.1 (K), Q1.1 (B), R35.2
unnamed: D5.2 (A), J1.9, J1.10
unnamed: J3.3 (T), R13.2
unnamed: J4.3 (T), R14.2
unnamed: J5.3 (T), R15.1
unnamed: J5.2 (TN), R41.2
unnamed: J6.3 (T), R26.2
unnamed: J7.3 (T), R27.2
unnamed: J8.3 (T), R35.1
unnamed: J8.2 (TN), R42.2
unnamed: J9.3 (T), R38.2
unnamed: J10.3 (T), R39.2
unnamed: LED1.2 (A), R11.1
unnamed: LED2.2 (A), R12.1
unnamed: LED3.2 (A), R24.1
unnamed: LED4.2 (A), R25.1
unnamed: LED5.2 (A), R36.1
unnamed: LED6.2 (A), R37.1
unnamed: R1.2, SW1.2
unnamed: R2.2, SW2.2
unnamed: R10.1, R12.2, R14.1, U3.14
unnamed: R9.1, R11.2, R13.1, U3.1
unnamed: R18.2, R23.1, U4.8
unnamed: R21.1, R24.2, R26.1, U3.7
unnamed: R22.1, R25.2, R27.1, U4.1
unnamed: R33.1, R36.2, R38.1, U3.8
unnamed: R34.1, R37.2, R39.1, U4.7
unnamed: C11.1, R3.1, U3.3 (+)
unnamed: R7.1, R9.2, U3.2 (-)
unnamed: C13.1, R16.1, U3.5 (+)
unnamed: R19.1, R21.2, U3.6 (-)
unnamed: C16.1, R29.1, U3.10 (+)
unnamed: R31.1, R33.2, U3.9 (-)
unnamed: C12.1, R4.1, U3.12 (+)
unnamed: R8.1, R10.2, U3.13 (-)
unnamed: C14.1, R17.1, U4.3 (+)
unnamed: R20.1, R22.2, U4.2 (-)
unnamed: C17.1, R30.1, U4.5 (+)
unnamed: R32.1, R34.2, U4.6 (-)
unnamed: R15.2, R18.1, U4.9 (-)
unnamed: C15.1, R23.2, R28.1, U5.2 (-)
OLED_SCL: J2.3, U2.2 (GP1)
OLED_SDA: J2.4, U2.1 (GP0)
OUT_1: R3.2, U2.27 (GP21)
OUT_2: R16.2, U2.26 (GP20)
OUT_3: R29.2, U2.21 (GP16)
OUT_4: R4.2, U2.22 (GP17)
OUT_5: R17.2, U2.24 (GP18)
OUT_6: R30.2, U2.25 (GP19)

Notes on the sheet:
Eurorack Power Connector
I2S/Expander Port
0 1 0 0 0 0 0 0
Operational Amplifier Power Supplies
Raspberry Pi Pico
Digital Input Stage
EuroPi SMD
5V Rail Regulation
Output Stage(s)
I2C Connector
Buttons
EuroPi
OLED Display
Analogue Input Stage ALL CREDITS TO ÉMILIE GILLET mutable-instruments.net
Knobs
Bit 1 (LSB) Bit 2 Bit 3 Bit 4

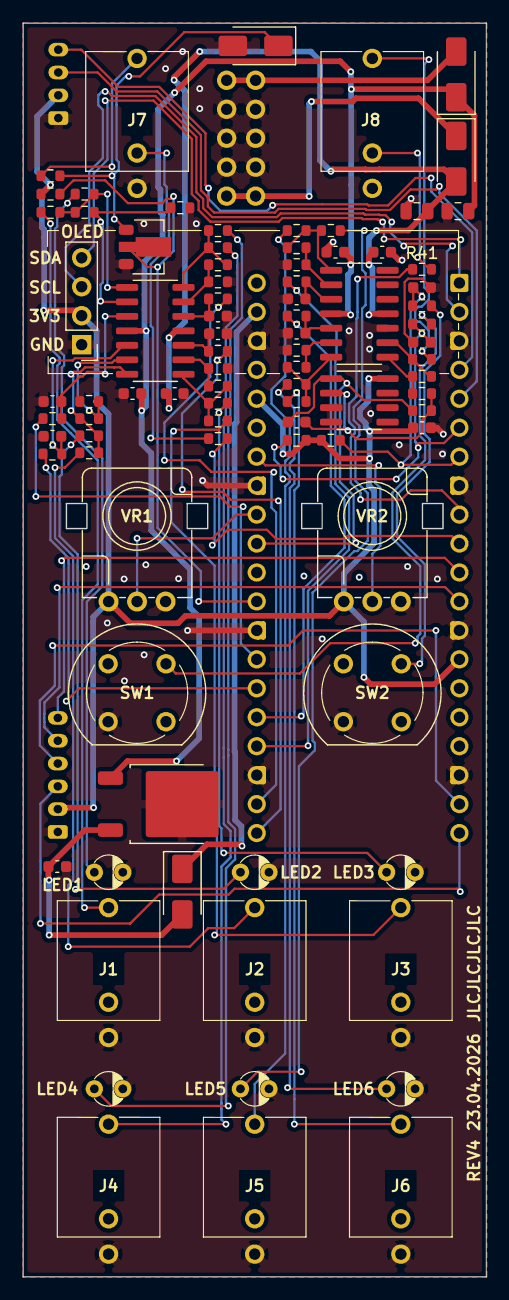
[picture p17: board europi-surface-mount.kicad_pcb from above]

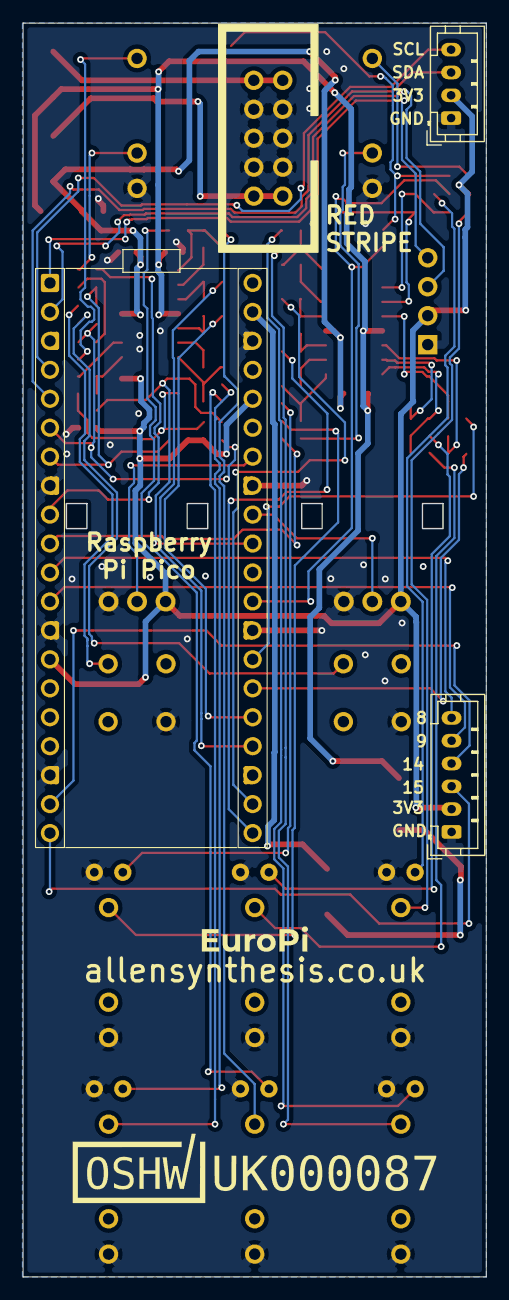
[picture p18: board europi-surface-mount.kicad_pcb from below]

Board: 2 copper layers, 40.6 x 110.0 mm, 91 parts (4 on the bottom side), 70 nets.

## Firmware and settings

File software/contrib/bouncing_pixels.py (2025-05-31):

# Copyright 2025 Allen Synthesis
#
# Licensed under the Apache License, Version 2.0 (the "License");
# you may not use this file except in compliance with the License.
# You may obtain a copy of the License at
#
#     http://www.apache.org/licenses/LICENSE-2.0
#
# Unless required by applicable law or agreed to in writing, software
# distributed under the License is distributed on an "AS IS" BASIS,
# WITHOUT WARRANTIES OR CONDITIONS OF ANY KIND, either express or implied.
# See the License for the specific language governing permissions and
# limitations under the License.

"""
A bunch of pixels bouncing around, inspired by the beloved bouncing DVD logo.
A gate is triggered each time a wall is hit. See `bouncing_pixels.md` for more information.

@author  Jorin (jorin.se)
@year    2025
"""

try:
    # Local development
    from software.firmware.europi import *
    from software.firmware.europi_script import EuroPiScript
    from software.firmware.experimental.math_extras import rescale
    from software.firmware.experimental.knobs import KnobBank
    from software.firmware.experimental.thread import DigitalInputHelper
    from software.firmware import configuration

except ImportError:
    # Device import paths
    from europi import *  # type: ignore
    from europi_script import EuroPiScript  # type: ignore
    from experimental.math_extras import rescale  # type: ignore
    from experimental.knobs import KnobBank  # type: ignore
    from experimental.thread import DigitalInputHelper  # type: ignore
    import configuration  # type: ignore

from _thread import start_new_thread, allocate_lock
from cmath import phase, polar, rect
from math import degrees, e, inf, log, pi, radians
from random import uniform
from time import ticks_ms, ticks_diff, sleep_ms

tau = pi * 2

ARENA_HEIGHT = 480
UNITS_PER_PIXEL = ARENA_HEIGHT / oled.height

COLLISION_ID_UP = 0
COLLISION_ID_LEFT = 1
COLLISION_ID_RIGHT = 2
COLLISION_ID_DOWN = 3
COLLISION_ID_ANY = 4
COLLISION_ID_CORNER = 5


def exponential_interpolation(a, b, t):
    """Exponentially interpolate between a and b by t, where t=0 gives a and t=1 gives b.
    This function uses e as the base which hopefully gives a "natural" feeling curve.
    """
    return e ** (t * log(b + 1 - a)) - 1 + a


class Event:
    """A simple, synchronous event implementation. Handlers can be added either when instantiating,
    or by using the += operator. The event is then emitted using the emit function.
    """

    def __init__(self, *handlers):
        # *handlers is a tuple, so we must explicitly create a mutable list to add given handlers to.
        self.handlers = []
        self.handlers.extend(handlers)

    def __iadd__(self, handler):
        """Register an event handling function."""
        self.handlers.append(handler)
        return self

    def emit(self, *args, **kwargs):
        """Emit the event, calling each handler synchronously in the order they were added.
        Arguments are passed through to each handler, so it is up to the user to ensure that
        the arguments match up.
        """
        for handler in self.handlers:
            handler(*args, **kwargs)


class Arena:
    def __init__(self, config):
        self.config = config
        self.on_width_changed = Event()

        # Height is constant, unlike width.
        self.height = ARENA_HEIGHT  # Simulated size
        self.display_height = oled.height  # Displayed arena height
        self.draw_y_min = 0  # First y coordinate for the displayed arena
        self.draw_y_max = (  # Last y coordinate for the displayed arena
            self.draw_y_min + self.display_height
        )

        # Width is variable, but we initialise its variables here to ensure it can be referenced.
        self.width = config.ARENA_WIDTH_MAX
        self.display_width = oled.width
        self.draw_x_min = 0
        self.draw_x_max = oled.width

    def set_width(self, width):
        """Set the arena's width."""
        prev_width = self.width
        self.width = clamp(width, self.config.ARENA_WIDTH_MIN, self.config.ARENA_WIDTH_MAX)
        self.display_width = int(self.width / UNITS_PER_PIXEL)
        self.draw_x_min = int(oled.width / 2 - self.display_width / 2)
        self.draw_x_max = self.draw_x_min + self.display_width
        self.on_width_changed.emit(prev_width, self.width)

    def draw_boundary(self):
        """Draw the boundaries of the arena, one pixel outside of draw_x_min and draw_x_max.
        This will fall outside of the bounds of the display when the arena covers the full screen, which is intentional.
        """
        oled.vline(self.draw_x_min - 1, 0, oled.height, 1)
        oled.vline(self.draw_x_max + 1, 0, oled.height, 1)


class Ball:
    def __init__(self, arena, config):
        self.config = config
        self.BOUNCE_ANGLE_DEVIATION_MAX = radians(config.BOUNCE_ANGLE_DEVIATION_MAX)
        self.arena = arena

        self.on_over_speed = Event(getattr(self, config.OVER_SPEED_BEHAVIOUR))
        self.on_under_speed = Event(getattr(self, config.UNDER_SPEED_BEHAVIOUR))
        self.on_collide = Event()
        arena.on_width_changed += self.translate_x

        self.reset()

    def __repr__(self):
        speed, direction = polar(self.velocity)
        return f"Ball at ({self.pos.real}, {self.pos.imag}), velocity {speed}/s {int(degrees(direction))}°"

    def if_active(fn):
        """Functions wrapped with this function will only run if self.active is true.
        This is needed to avoid processing when over/under speed behaviour is set to deactivate.
        """

        def inner(self, *args, **kwargs):
            if not self.active:
                return
            fn(self, *args, **kwargs)

        return inner

    @if_active
    def draw(self):
        arena = self.arena
        x = int(rescale(self.pos.real, 0, arena.width, arena.draw_x_min, arena.draw_x_max))
        y = int(rescale(self.pos.imag, 0, arena.height, arena.draw_y_min, arena.draw_y_max))
        oled.pixel(x, y, 1)

    def translate_x(self, old_width: float, new_width: float):
        """Translate the ball's x so that it's the same relative distance from the edges with new_width as it was with old_width."""
        new_x = new_width * self.pos.real / old_width
        self.pos = complex(new_x, self.pos.imag)

    def reset(self):
        """Reset the ball, randomising its position, velocity, bounciness, acceleration, and marking it as active."""
        self.pos = complex(uniform(0, self.arena.width), uniform(0, self.arena.height))
        self.velocity = rect(
            uniform(self.config.START_SPEED_MIN, self.config.START_SPEED_MAX), uniform(0, tau)
        )
        self.bounciness = uniform(self.config.BOUNCINESS_MIN, self.config.BOUNCINESS_MAX)
        self.acceleration = uniform(self.config.ACCEL_MIN, self.config.ACCEL_MAX)
        self.active = True

    @if_active
    def impulse(self):
        """Apply an impulse of speed in a random direction to the ball."""
        self.velocity += rect(
            uniform(
                self.config.IMPULSE_SPEED_VARIATION_MIN, self.config.IMPULSE_SPEED_VARIATION_MAX
            )
            * self.impulse_speed,
            uniform(0, tau),
        )

    def deactivate(self):
        """Set the ball to inactive, meaning it won't be processed by functions that are wrapped by @if_active."""
        self.active = False

    def noop(self):
        """Do nothing. This is used as a possible under speed behaviour."""
        pass

    @if_active
    def tick(self, delta: float):
        # Apply acceleration
        delta_v = rect(self.acceleration * delta, phase(self.velocity))
        self.velocity += delta_v

        # Grab the speed and direction of the resulting velocity for later use
        speed, direction = polar(self.velocity)

        # Apply velocity and check whether collisions happened
        delta_x = self.velocity.real * delta
        delta_y = self.velocity.imag * delta

        collide_x = (self.pos.real + delta_x) // self.arena.width
        collide_y = (self.pos.imag + delta_y) // self.arena.height

        self.pos += complex(
            delta_x - delta_x * abs(collide_x) * 2,
            delta_y - delta_y * abs(collide_y) * 2,
        )

        if collide_x != 0:
            if collide_x != 1:  # Left
                self.on_collide.emit(COLLISION_ID_LEFT)
            if collide_x != -1:  # Right
                self.on_collide.emit(COLLISION_ID_RIGHT)
            if (
                self.pos.imag < self.config.CORNER_COLLISION_MARGIN
                or self.arena.height - self.pos.imag < self.config.CORNER_COLLISION_MARGIN
            ):
                self.on_collide.emit(COLLISION_ID_CORNER)

            speed *= self.bounciness
            direction = (
                pi
                - direction
                + uniform(-self.BOUNCE_ANGLE_DEVIATION_MAX, self.BOUNCE_ANGLE_DEVIATION_MAX)
            )

        if collide_y != 0:
            if collide_y != 1:  # Up
                self.on_collide.emit(COLLISION_ID_UP)
            if collide_y != -1:  # Down
                self.on_collide.emit(COLLISION_ID_DOWN)

            speed *= self.bounciness
            direction = -direction + uniform(
                -self.BOUNCE_ANGLE_DEVIATION_MAX, self.BOUNCE_ANGLE_DEVIATION_MAX
            )

        # Update velocity based on changes to speed and direction stemming from collisions
        self.velocity = rect(speed, direction)

        # Travelled more than one width or height in one tick, or speed is above threshold.
        # TODO: we should be able to account for multiple collisions in one tick and not need this check
        if abs(collide_x) > 1 or abs(collide_y) > 1 or speed > self.config.OVER_SPEED_THRESHOLD:
            self.on_over_speed.emit()

        # Speed too low
        if speed < self.config.UNDER_SPEED_THRESHOLD:
            self.on_under_speed.emit()


class Gate:
    def __init__(self, cv, gate_hold_length):
        self.cv = cv
        self.gate_hold_length = gate_hold_length
        self.opened = None

    def on(self):
        self.cv.on()
        self.opened = ticks_ms()

    def off(self):
        self.cv.off()
        self.opened = None

    def tick(self, delta: float):
        if self.opened is None:
            return
        if ticks_diff(ticks_ms(), self.opened) >= self.gate_hold_length:
            self.off()


class BouncingPixels(EuroPiScript):
    def __init__(self):
        super().__init__()
        self.is_running = False

        # This lock is for both the arena and the balls.
        # Since changing arena size changes ball positions, it is a shared lock.
        self.state_lock = allocate_lock()

        saved_state = self.load_state_json()
        self.state_saved = False
        self.k1_bank = (
            KnobBank.builder(k1)
            .with_unlocked_knob("speed")
            .with_locked_knob(
                "ball_count", initial_percentage_value=saved_state.get("ball_count", 0.0)
            )
            .build()
        )

        self.k2_bank = (
            KnobBank.builder(k2)
            .with_unlocked_knob("width")
            .with_locked_knob("impulse_speed", initial_percentage_value=saved_state.get("impulse_speed", 0.5))
            .build()
        )

        # Initialise some internal state variables
        self.b1_pressed = None
        self.b2_pressed = None
        self.ball_count = 1
        self.time_factor = 1

        # Trackers of inputs
        # -1 as a starting value means they always get updated on first poll.
        self.speed_input = -1.0
        self.width_input = -1.0
        self.ball_count_input = -1.0
        self.impulse_speed_input = -1.0
        self.ain_input = -1.0

        # We store analogue input values in these. Although we only change change one as determined by
        # config.AIN_FUNCTION, we do need to reference them all when their respective knobs change.
        self.speed_ain_term = 0.0
        self.width_ain_term = 0.0
        self.ball_count_ain_term = 0.0
        self.impulse_speed_ain_term = 0.0

        # Initialise input events
        self.on_speed_input = Event(self.mark_state_unsaved, self.apply_speed)
        self.on_width_input = Event(self.mark_state_unsaved, self.apply_width)
        self.on_ball_count_input = Event(self.mark_state_unsaved, self.apply_ball_count)
        self.on_impulse_speed_input = Event(self.mark_state_unsaved, self.apply_impulse_speed)
        self.on_ain_input = Event(
            # To avoid excess compute spent on string formatting or dict lookups in the main loop, we keep an assortment of
            # set and apply functions so that we can assign them once and for all here.
            getattr(self, f"update_{self.config.AIN_FUNCTION}_ain_term"),
            getattr(self, f"apply_{self.config.AIN_FUNCTION}"),
        )

        # Create the playing field and gate abstractions
        self.arena = Arena(self.config)
        self.balls = [
            Ball(arena=self.arena, config=self.config) for _ in range(self.config.BALL_COUNT_MAX)
        ]
        hold_lengths = [
            self.config.GATE_HOLD_LENGTH_TOP,
            self.config.GATE_HOLD_LENGTH_LEFT,
            self.config.GATE_HOLD_LENGTH_RIGHT,
            self.config.GATE_HOLD_LENGTH_BOTTOM,
            self.config.GATE_HOLD_LENGTH_ANY,
            self.config.GATE_HOLD_LENGTH_CORNER,
        ]
        self.gates = [Gate(cv, hold_length) for cv, hold_length in zip(cvs, hold_lengths)]

        # Register external event handlers.
        self.digital_input_helper = DigitalInputHelper(
            on_b1_rising=self.b1_rising,
            on_b1_falling=self.b1_falling,
            on_b2_rising=self.b2_rising,
            on_b2_falling=self.b2_falling,
            on_din_rising=getattr(self, self.config.DIN_FUNCTION)
        )

        for ball in self.balls:
            ball.on_collide += self.report_collision

    @classmethod
    def config_points(cls):
        return [
            configuration.floatingPoint(
                "POLL_FREQUENCY", minimum=5.0, maximum=inf, default=30.0, danger=True
            ),
            configuration.floatingPoint(
                "SAVE_PERIOD", minimum=0.0, maximum=inf, default=5000.0, danger=True
            ),
            configuration.floatingPoint(
                "RENDER_FREQUENCY", minimum=1.0, maximum=inf, default=30.0, danger=True
            ),
            configuration.floatingPoint(
                "LONG_PRESS_LENGTH", minimum=0.0, maximum=inf, default=500.0
            ),
            configuration.floatingPoint("TIMESCALE_MIN", minimum=-inf, maximum=inf, default=0.0),
            configuration.floatingPoint("TIMESCALE_MAX", minimum=-inf, maximum=inf, default=100.0),
            configuration.floatingPoint(
                "KNOB_CHANGE_THRESHOLD", minimum=0.0, maximum=0.1, default=0.01
            ),
            configuration.choice("DIN_FUNCTION", choices=["impulse", "reset"], default="impulse"),
            configuration.choice(
                "AIN_FUNCTION",
                choices=["speed", "impulse_speed", "ball_count", "width"],
                default="speed",
            ),
            configuration.floatingPoint(
                "GATE_HOLD_LENGTH_TOP", minimum=1.0, maximum=10_000.0, default=25.0
            ),
            configuration.floatingPoint(
                "GATE_HOLD_LENGTH_LEFT", minimum=1.0, maximum=10_000.0, default=25.0
            ),
            configuration.floatingPoint(
                "GATE_HOLD_LENGTH_RIGHT", minimum=1.0, maximum=10_000.0, default=25.0
            ),
            configuration.floatingPoint(
                "GATE_HOLD_LENGTH_BOTTOM", minimum=1.0, maximum=10_000.0, default=25.0
            ),
            configuration.floatingPoint(
                "GATE_HOLD_LENGTH_ANY", minimum=1.0, maximum=10_000.0, default=10.0
            ),
            configuration.floatingPoint(
                "GATE_HOLD_LENGTH_CORNER", minimum=1.0, maximum=10_000.0, default=100.0
            ),
            configuration.floatingPoint(
                "ARENA_WIDTH_MIN",
                minimum=ARENA_HEIGHT * 2.0 / oled.height,
                maximum=ARENA_HEIGHT * oled.width / oled.height,
                default=ARENA_HEIGHT * 2.0 / oled.height,
            ),
            configuration.floatingPoint(
                "ARENA_WIDTH_MAX",
                minimum=ARENA_HEIGHT * 2.0 / oled.height,
                maximum=ARENA_HEIGHT * oled.width / oled.height,
                default=ARENA_HEIGHT * oled.width / oled.height,
            ),
            configuration.integer("BALL_COUNT_MIN", minimum=1, maximum=100, default=1),
            configuration.integer("BALL_COUNT_MAX", minimum=1, maximum=100, default=100),
            configuration.floatingPoint(
                "CORNER_COLLISION_MARGIN",
                minimum=0.0,
                maximum=ARENA_HEIGHT / 2.0,
                default=ARENA_HEIGHT / oled.height,
            ),
            configuration.floatingPoint("START_SPEED_MIN", minimum=0.0, maximum=inf, default=10.0),
            configuration.floatingPoint("START_SPEED_MAX", minimum=0.0, maximum=inf, default=100.0),
            configuration.floatingPoint("ACCEL_MIN", minimum=-inf, maximum=inf, default=-5.0),
            configuration.floatingPoint("ACCEL_MAX", minimum=-inf, maximum=inf, default=5.0),
            configuration.floatingPoint("BOUNCINESS_MIN", minimum=0.0001, maximum=inf, default=0.8),
            configuration.floatingPoint("BOUNCINESS_MAX", minimum=0.0001, maximum=inf, default=1.2),
            configuration.floatingPoint(
                "BOUNCE_ANGLE_DEVIATION_MAX", minimum=0.0, maximum=180.0, default=15.0
            ),
            configuration.choice(
                "UNDER_SPEED_BEHAVIOUR",
                choices=["impulse", "reset", "deactivate", "noop"],
                default="reset",
            ),
            configuration.choice(
                "OVER_SPEED_BEHAVIOUR", choices=["reset", "deactivate"], default="reset"
            ),
            configuration.floatingPoint(
                "UNDER_SPEED_THRESHOLD", minimum=0.0, maximum=inf, default=5.0
            ),
            configuration.floatingPoint(
                "OVER_SPEED_THRESHOLD", minimum=0.0, maximum=inf, default=1.0e6
            ),
            configuration.floatingPoint("IMPULSE_SPEED_MIN", minimum=0.0, maximum=inf, default=0.0),
            configuration.floatingPoint(
                "IMPULSE_SPEED_MAX", minimum=0.0, maximum=inf, default=1.0e5
            ),
            configuration.floatingPoint(
                "IMPULSE_SPEED_VARIATION_MIN", minimum=0.0, maximum=inf, default=0.5
            ),
            configuration.floatingPoint(
                "IMPULSE_SPEED_VARIATION_MAX", minimum=0.0, maximum=inf, default=2.0
            ),
        ]

    # Button handlers
    def b1_rising(self):
        self.k1_bank.set_current("ball_count")
        self.k2_bank.set_current("impulse_speed")
        self.b1_pressed = ticks_ms()

    def b1_falling(self):
        self.k1_bank.set_current("speed")
        self.k2_bank.set_current("width")

        delta = ticks_diff(ticks_ms(), self.b1_pressed)
        if delta <= self.config.LONG_PRESS_LENGTH:
            self.reset()

        self.b1_pressed = None

    def b2_rising(self):
        self.k1_bank.set_current("ball_count")
        self.k2_bank.set_current("impulse_speed")
        self.b2_pressed = ticks_ms()

    def b2_falling(self):
        self.k1_bank.set_current("speed")
        self.k2_bank.set_current("width")

        delta = ticks_diff(ticks_ms(), self.b2_pressed)
        if delta <= self.config.LONG_PRESS_LENGTH:
            self.impulse()

        self.b2_pressed = None

    def mark_state_unsaved(self):
        """Denote that the state saved onto storage does not match current knob state."""
        self.state_saved = False

    def save_state(self):
        """Save knob states to storage and denote that storage matches current knob state."""
        self.save_state_json(
            {
                "speed": self.speed_input,
                "width": self.width_input,
                "ball_count": self.ball_count_input,
                "impulse_speed": self.impulse_speed_input,
            }
        )
        self.state_saved = True

    # Event handlers to save analogue input into respective variables
    def update_speed_ain_term(self):
        self.speed_ain_term = ain.percent()

    def update_width_ain_term(self):
        self.width_ain_term = ain.percent()

    def update_ball_count_ain_term(self):
        self.ball_count_ain_term = ain.percent()

    def update_impulse_speed_ain_term(self):
        self.impulse_speed_ain_term = ain.percent()

    # Event handlers to apply knob and analogue input values
    def apply_speed(self):
        input_sum = self.speed_input + self.speed_ain_term
        self.time_factor = exponential_interpolation(
            self.config.TIMESCALE_MIN, self.config.TIMESCALE_MAX, input_sum
        )

    def apply_width(self):
        input_sum = self.width_input + self.width_ain_term
        width = rescale(
            input_sum, 0.0, 1.0, self.config.ARENA_WIDTH_MIN, self.config.ARENA_WIDTH_MAX
        )
        self.arena.set_width(width)

    def apply_ball_count(self):
        input_sum = self.ball_count_input + self.ball_count_ain_term
        self.ball_count = int(
            exponential_interpolation(
                self.config.BALL_COUNT_MIN, self.config.BALL_COUNT_MAX, input_sum
            )
        )
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

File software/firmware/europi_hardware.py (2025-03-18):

# Copyright 2025 Allen Synthesis
#
# Licensed under the Apache License, Version 2.0 (the "License");
# you may not use this file except in compliance with the License.
# You may obtain a copy of the License at
#
#     http://www.apache.org/licenses/LICENSE-2.0
#
# Unless required by applicable law or agreed to in writing, software
# distributed under the License is distributed on an "AS IS" BASIS,
# WITHOUT WARRANTIES OR CONDITIONS OF ANY KIND, either express or implied.
# See the License for the specific language governing permissions and
# limitations under the License.
"""
Hardware-specific definitions & implementations for Europi

Originally all of this was included as part of europi.py, but was moved
here to make it easier to access e.g. button status readers independently
of all of the other EuroPi initialization that occurs inside the `europi`
module.

Normally this module should not be included directly; it's imported
automatically as part of `from europi import *`.
"""

from machine import ADC
from machine import I2C
from machine import PWM
from machine import Pin
from machine import freq
from machine import mem32
import time

from europi_config import load_europi_config, CPU_FREQS
from experimental.experimental_config import load_experimental_config

# Load the configuration objects so we can initialize
# the hardware according to user preferences
europi_config = load_europi_config()
experimental_config = load_experimental_config()

# Analogue voltage read range.
MIN_INPUT_VOLTAGE = 0
MAX_INPUT_VOLTAGE = europi_config.MAX_INPUT_VOLTAGE
GATE_VOLTAGE = europi_config.GATE_VOLTAGE
DEFAULT_SAMPLES = 32

# Output voltage range
MIN_OUTPUT_VOLTAGE = 0
MAX_OUTPUT_VOLTAGE = europi_config.MAX_OUTPUT_VOLTAGE

PWM_FREQ = 100_000

# Digital input and output binary values.
HIGH = 1
LOW = 0

# Pin assignments
PIN_DIN = 22
PIN_AIN = 26
PIN_K1 = 27
PIN_K2 = 28
PIN_B1 = 4
PIN_B2 = 5
PIN_CV1 = 21
PIN_CV2 = 20
PIN_CV3 = 16
PIN_CV4 = 17
PIN_CV5 = 18
PIN_CV6 = 19
PIN_USB_CONNECTED = 24
PIN_TEMPERATURE = 4

# Standard max int consts.
MAX_UINT16 = 65535

# How many CV outputs are there?
# On EuroPi this 6, but future versions (e.g. EuroPi X may have more)
NUM_CVS = 6

# Import the calibration values
# These are generated by tools/calibrate.py, but do not exist by default
try:
    from calibration_values import INPUT_CALIBRATION_VALUES, OUTPUT_CALIBRATION_VALUES
except ImportError:
    # Note: run calibrate.py to get a more precise calibration.
    # Default calibration values are close-enough to reasonable performance, but aren't great
    INPUT_CALIBRATION_VALUES = [384, 44634]
    OUTPUT_CALIBRATION_VALUES = [
        0,
        6300,
        12575,
        19150,
        25375,
        31625,
        38150,
        44225,
        50525,
        56950,
        63475,
    ]
# Legacy calibration using only CV1; apply the same calibration values to each output
if type(OUTPUT_CALIBRATION_VALUES[0]) is int:
    cv1_values = OUTPUT_CALIBRATION_VALUES
    OUTPUT_CALIBRATION_VALUES = []
    for i in range(NUM_CVS):
        OUTPUT_CALIBRATION_VALUES.append(cv1_values)


def clamp(value: int | float, low: int | float, high: int | float):
    """
    Returns a value that is no lower than 'low' and no higher than 'high'.

    :param value:  The value to clamp
    :param low:  The inclusive lower bound
    :param high:  The inclusive upper bound
    """
    return max(min(value, high), low)
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

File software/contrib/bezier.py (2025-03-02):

#!/usr/bin/env python3
# Copyright 2024 Allen Synthesis
#
# Licensed under the Apache License, Version 2.0 (the "License");
# you may not use this file except in compliance with the License.
# You may obtain a copy of the License at
#
#     http://www.apache.org/licenses/LICENSE-2.0
#
# Unless required by applicable law or agreed to in writing, software
# distributed under the License is distributed on an "AS IS" BASIS,
# WITHOUT WARRANTIES OR CONDITIONS OF ANY KIND, either express or implied.
# See the License for the specific language governing permissions and
# limitations under the License.
"""
Generates random voltages based on Bezier curves

Inspired by Addac Systems' & Monotrail's ADDAC507 collaboration
"""

from europi import *
from europi_script import EuroPiScript

from experimental.knobs import *
from experimental.math_extras import solve_linear_system
from experimental.screensaver import OledWithScreensaver

import configuration
import math
import random
import time

ssoled = OledWithScreensaver()

class LogicalOperator:
    """Abstract class used for saving the gate outputs' logical operation

    Subclasses must implement the compare(a, b) method
    """
    def compare(self, a, b):
        raise Exception("Not implemented")

class LogicalAnd(LogicalOperator):
    """Binary AND operator"""
    def compare(self, a, b):
        return a and b

class LogicalOr(LogicalOperator):
    """Binary OR operator"""
    def compare(self, a, b):
        return a or b

class LogicalXor(LogicalOperator):
    """Binary XOR operator"""
    def compare(self, a, b):
        return (a or b) and not (a and b)

class LogicalNand(LogicalOperator):
    """Binary NAND operator"""
    def compare(self, a, b):
        return not (a and b)

class LogicalNor(LogicalOperator):
    """Binary Nor operator"""
    def compare(self, a, b):
        return not (a or b)

class LogicalXnor(LogicalOperator):
    """Binary XNOR operator"""
    def compare(self, a, b):
        return (a and not b) or (not a and b)


CLIP_MODE_LIMIT = 0
CLIP_MODE_FOLD = 1
CLIP_MODE_THRU = 2
N_CLIP_MODES = 3

CLIP_MODE_NAMES = [
    "Limit",
    "Fold",
    "Thru"
]

AIN_MODE_FREQUENCY = "frequency"
AIN_MODE_CURVE = "curve"


class Point2D:
    def __init__(self, x, y):
        self.x = x
        self.y = y

    def __str__(self):
        return f"{self.x},{self.y}"


def linear_interpolate(x1, x2, t):
    """Linearly interpolate from one value to another

    @param x1 The initial value of x
    @param x2 The final value of x
    @param t  The time [0, 1]

    @return   The interpolated value of x
    """
    return x1 * (1-t) + x2 * t


class BezierCurve:
    """Calculates 2D bezier curves using quadratic interpolation

    The intermediate point, P1, always lies on the inverse diagonal o
    """
    def __init__(self):
        self.origin = Point2D(0, 0)
        self.next_point = Point2D(1, 0)

    def set_next_value(self, y):
        """Set the y value for the next time increment (0-1)
        """
        self.origin.y = self.next_point.y
        self.next_point.y = y

    def value_at(self, t, k):
        """Get the value of the bezier curve for a given time

        @param t  The time [0, 1]
        @param k  The curve constant, in the range [-1, 1]  See @interpolate for details on the curve constant
        """
        # Get 4 points on the curve so we can create a cubic equation for the curve
        p1 = self.interpolate(0, k)
        p2 = self.interpolate(1/3, k)
        p3 = self.interpolate(2/3, k)
        p4 = self.interpolate(1, k)

        # matrix representation
        m = [
            [p1.x**3, p1.x**2, p1.x, 1, p1.y],
            [p2.x**3, p2.x**2, p2.x, 1, p2.y],
            [p3.x**3, p3.x**2, p3.x, 1, p3.y],
            [p4.x**3, p4.x**2, p4.x, 1, p4.y],
        ]

        coeffs = solve_linear_system(m)
        return coeffs[0] * t**3 + coeffs[1] * t**2 + coeffs[2] * t + coeffs[3]


    def interpolate(self, t, k):
        """Calculate the 2D position for the given time

        See https://en.wikipedia.org/wiki/Bezier_curve#Cubic_curves for details on the math.

        @param t  The current interpolated time, between 0 and 1
        @param k  A constant indicating our progression from horizontal endpoints (smoothest) @ -1.0 to
                  linear @ 0.0 to vertical endpoints (spikiest) @ 1.0
        @return   The interpolated 2D point on the bezier curve
        """
        # Define 2 intermediate points, which are either horizontally or vertically aligned with the start and end points
        p0 = self.origin
        p1 = Point2D(0,0)
        p2 = Point2D(0,0)
        p3 = self.next_point

        if k <= 0:
            # start/endpoints aligned horizontally with intermediate points
            # /3 results in slightly smoother results; /2 was giving cusps on sharp peaks & valleys
            p1.x = p0.x - k/3
            p2.x = p3.x + k/3
            p1.y = p0.y
            p2.y = p3.y
        else:
            # start/endpoints aligned vertically with intermediate points
            p1.x = p0.x
            p2.x = p3.x

            dy = abs(p0.y - p3.y)

            if p0.y < p3.y:
                # p1 goes up, p2 goes down
                p1.y = p1.y + dy * k/2
                p2.y = p3.y - dy * k/2
            else:
                # p1 goes down, p2 goes up
                p1.y = p1.y - dy * k/2
                p2.y = p3.y + dy * k/2

        q0 = Point2D(
            linear_interpolate(p0.x, p1.x, t),
            linear_interpolate(p0.y, p1.y, t)
        )
        q1 = Point2D(
            linear_interpolate(p1.x, p2.x, t),
            linear_interpolate(p1.y, p2.y, t)
        )
        q2 = Point2D(
            linear_interpolate(p2.x, p3.x, t),
            linear_interpolate(p2.y, p3.y, t)
        )

        r0 = Point2D(
            linear_interpolate(q0.x, q1.x, t),
            linear_interpolate(q0.y, q1.y, t)
        )
        r1 = Point2D(
            linear_interpolate(q1.x, q2.x, t),
            linear_interpolate(q1.y, q2.y, t)
        )

        b = Point2D(
            linear_interpolate(r0.x, r1.x, t),
            linear_interpolate(r0.y, r1.y, t)
        )

        return b
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

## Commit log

2021-11-26 Add files via upload
    OLED is now accessed as a subclass to allow custom methods; OLED initialisation has custom error message if not identified on the i2c scan
    [europi.py]
2021-11-28 Add files via upload
    Custom error message for non-string used in oled.centre_text()
    [europi.py]
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2021-12-03 Fix DigitalInput init bounce
    Previously used 0 as last_pressed which causes it to be triggered immediately. Changed now to initialise at the current time ticks_ms to fix this
    [europi.py]
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2022-01-01 Initial commit of the coin toss script. Also fixed bug in Knob choice, and added percent method.
    [coin_toss.py, europi.py]
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2022-01-12 Update harmonic_lfos.py
    Add display and optimisation. LFOs now all start/reset at 0V
    [harmonic_lfos.py]
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2022-01-22 Add calibration error message
    If calibration was run without rack power turned on, duplicate values in the calibration list will result in a ZeroDivisionError when trying to initialise the analogue input.
    Added an error message to tell the user to complete calibration again with rack power turned on
    [europi.py]
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2022-02-02 Move contrib dir to software
    This keeps all software in one place, makes copying the code to the
    board easier and opens the door to a simpler testing infrastructure and
    simpler bootloader code.
    Fixes issue #55
    [coin_toss.py, diagnostic.py, harmonic_lfos.py]
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2022-03-12 Remove .clear() method
    Remove .clear() method and replace the only instance where it was used with .fill(0)
    [europi.py]
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2022-03-15 updates from PR review
    - use super() call
    - use qualname not display name for save state file
    - remove unnecessary main()
    - remove menu handlers
    - add note that EuroPiScripts should not call reset_state()
    [bootloader.py, europi_script.py]
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2022-04-14 remove for loop that was calling _set_duty() multiple times
    The for loop in Output.voltage() ended up calling _set_duty() multiple
    times while it found the correct calibration setting. This resulted in
    unwanted noise as the output value changed. This fix removes the for
    loop, and only sets the output duty once.
    [europi.py]
2022-04-15 Reduce default output PWM frequency
    Reduce default output PWM frequency from 1MHz to 100kHz to increase effective bit depth and reduce stepping issues when trying to generate smooth voltages
    [europi.py]
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2022-04-30 Add EuroPiError class
    Add EuroPiError class which will display a given error code both in the terminal and on the OLED display. The OLED message will appear for 5 seconds before allowing resumption of the script, so users can exit to the menu again if they are unable to fix the error themselves
    [europi.py]
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2022-07-26 add docstrings to Knobs
    add experimental.knobs to the api docs
    also add a missing parameter and remove an unused parameter
    [knobs.py]
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2022-07-26 fix length code to line up with how the TM actually works
    [turing_machine.py]
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2022-10-16 Revert "Merge branch 'main' of https://github.com/gamecat69/EuroPiApps"
    This reverts commit 844af6e735bd72cd36aa6fdc359e89a96769bb65, reversing
    changes made to 0c78cf291f8c515bbeb01b6482c11c8683b03c6a.
    [europi.py, knobs.py, turing_machine.py]
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2022-11-13 move machine freq call and reset_state call over to menu.py instead of calling at firmware import time.
    [europi.py]
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2022-12-06 fix missing version file (#205)
    * include the version.py file in the contrib distribution
    * increment version number for bugfix release
    [version.py]
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2023-02-06 upgrade black and pip-tools (#216)
    black makes formatter changes on a yearly basis. This commit upgrades us
    to the 2023 version and makes one simple change to bring the code up to
    spec. pip-tools was also upgraded to fix an import error when running
    pip-compile.
    [bootloader.py]
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2023-02-17 config improvements and clean up
    add int config point
    add tests for different config point failures
    make the TM pulses bits configurable
    move europi_config.py to the firmware
    diagnostic temp units are configurable
    also black format diagnostic
    [diagnostic.py, europi_config.py, turing_machine.py]
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2023-02-28 Add quantizer to contrib (#222)
    * Initial commit of some working code. Still a lot to do, but it can quantize to a chromatic scale using an external trigger right now
    * Add support for togging notes in the scale on and off. Start (re-)building support for continuous operation instead of triggered
    * Implement the menu items to set intervals, root offset, operation mode
    * Fix the default view to be the keyboard screen
    * Add menu instructions, implement save/load
    * Remove a TODO that we've done
    * Apply the transposition generated by .root; we weren't actually doing anything with it before
    * Keep the current note root agnostic; just change the output voltage. Otherwise the G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
    [quantizer.py]
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2023-03-01 LockableKnob init fix (#193)
    * add back in the KnobPlayground
    * change var name in test
    * add initial_percentage_value and initial_uint16_value to LockableKnob
    This makes the values used in initial knob setup more clear.
    * update TuringMachine for LockableKnob changes
    add ability to set the initial value in the TM class. Use this to more clearly setup the inital state of the locked knob.
    * remove KnobPlayground from menu
    We'd like to make this available, but there seems to be a memory
    allocation issue when adding more scripts. This will be addressed in a
    different PR.
    [knobs.py, turing_machine.py]
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2023-03-15 Menu improvements (#235)
    * display a progress bar while loading scripts for the menu
    * menu: delay importing scripts untill necessary
    this means that we can boot faster if we are going directly to the script (bypassing the menu)
    * fix menu import test
    * preemptive GC to allow scripts to load
    also add some debug code to make future memory investigations easier
    * Reset machine before running selected script
    This forces all of the imported scripts out of memory, allows the
    running script access to all available memory, and puts scripts launched
    from the menu on the same footing as those launched from saved state
    * minor cleanup
    * Update uf2 building and docs for cha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
    [bootloader.py, europi_script.py]
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2023-03-19 2 Point calibration fix (#232)
    * Fix 2 point calibration
    * Fix 2 point calibration in mock
    * Fixed error in percentage calculation
    * fixed missing ( ) in calculation
    * account for ain < 0 point calibration
    * update for 2 point calibration
    * make black happy
    * make black happy
    * Why did my black output differ?
    * format for black
    * Remove dublicate calculation
    * reformat
    [europi.py]
2023-03-19 Consequencer mar 23 (#241)
    * removed comment
    * randomness now sum of ain and k1
    * pattern is now sum of ain and k2
    * decreased maxRandomPatterns to 32 to avoid crashes on some systems
    * updated version history
    * added garbage collection
    * added scrolling pattern effect
    * updated patterns
    * removed duplicate line in version history
    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
    [consequencer.py]
2023-03-25 Add Euclidean Rhythm generator (#243)
    * Initial commit to start the Euclidean Rhythm script
    * Implement the bulk of the backend for generating the rhythms, loading, and saving. Add the euclid docs and add the script to the menu
    * Implement the first-draft UI and menus
    * Add default patterns, change the default number of steps to 1 to prevent index out of bounds issues, fix some bugs found when testing on hardware
    * Cache the string representation of the pattern, resetting it on regenerate() or advance() calls
    * Add a screensaver to blank the screen if there's no user interaction for 20 minutes. Pressing either button returns to the channel menu
    * Add a note about the screen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
    [euclid.py]
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2023-03-30 Fix errors in schematic (#246)
    * Fix errors
    R13 value was fixed from 1K to 4K7, and the second MCP6002 unit was specified as unconnected
    * Update schematic PDF
    [europi_schematic.kicad_sch]
2023-04-21 Fix ain.choice and ain.range alternative (#253)
    * missing deadzones parameter in ain.percent
    * Add documentation
    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
    [europi.py]
2023-05-03 Make consequencer scrolling infinite (#251)
    * make scrolling infinite
    * Fix infinite scrolling for shorter patterns
    * Add fix for patterns >16 steps long
    * remove unnecessary for loop
    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
    [consequencer.py]
2023-06-07 Fix i2c labels on schematic (#280)
    * fix i2c labels on schematic
    * generate schematic pdf
    [europi_schematic.kicad_sch]
2023-06-16 Add Pamela's "EuroPi" Workout (#248)
    * Clean rebase to latest master, squashed merge of previous pams changes (except the bad merge)
    * Re-apply the changes to the mocks for testing
    * Remove the effects of Width and Amplitude on AIN waves; this was having undesired consequences when using the script as a S&H quantizer. This simplifies the setup and prevents accidental (and sometimes dramatic) pitch-shifting as a result of the default settings
    * Add support for phase-offset. This lets us trigger pulses on off-beats! Woo! Can't believe I didn't think to add that earlier...
    * Code cleanup, use OrderedDict objects to simplify storing the clock mods & quantizers. Remove some unncessary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
    [euclid.py, quantizer.py, screensaver.py]
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2023-08-09 Updates to Pam's (#292)
    * Move the start/stop/reset signals out of the wave shape and into the clock mod settings; this closer-matches the original Pam's module and eliminates ambiguity about what a x4 Reset wave actually means (hint: the x4 does NOTHING)
    * Update the documentation
    * First-draft swing implementation. Untested on the Pi because it's late, so it may not work properly yet
    * Documentation update
    * Add per-channel mute options
    * Typo. Tested mute & swing; both appear to work as intended
    * Add a per-channel reset action to reset all settings to default
    * Fix a bug where setting the swing too high or too low caused a division-by-zero error.
    * Add a note abou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
    [knobs.py, quantizer.py]
2023-08-18 Update the screensaver logo to use the new graphics (#299)
    * Update the screensaver logo to use the new graphics
    * Linting
    * Fix the new logo bytearray
    * ' -> "
    [screensaver.py]
2023-09-05 Lazy-load menu items on launch, add exception handling (#298)
    * Overhaul the menu so we give it an OrderedDict initially, only load the class to be launched at the time of launch. Add some exception-handling and a BSOD analogue to display error messages
    * Remove the test_build_scripts_mapping test, since that function has been removed
    * Better exception logging
    * Move the EuroPiScript validation into the menu function instead of the launch callback. Remove references to traceback. Remove some duplicate documentation from docstrings.
    * Reset run_request on an invalid script
    * Remove the sleep when the error duration is zero/negative. Force all CV outputs off if an unhandled exc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
    [bootloader.py]
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2023-09-18 Basic support for large fonts - V2 (#293)
    * copy across all files from @francoisgeorgy 's branch
    * remove reference to non existent script
    * include instantiated Display class in custom_font.py
    * make writer method private
    * correct text_width return value
    * convert Display class to wrap existing firmware class
    * black formatting
    * use instantiated oled object rather than create new one
    * replace duplicate code with super() call
    * update docstring
    * rename class
    * Create custom_font.md
    * black formatting
    * documentation changes
    [custom_font.py]
2023-09-23 Add Particle Physics LFO script (#297)
    * Initial commit of a bouncy physics-inspired LFO
    * Highlight which modifiers are editable, remember to set the last update time so the particle moves correctly
    * Overhaul the Particle class so update() doesn't return anything but instead sets flags inherent to the class. Assume the particle has come to rest if it's 2mm at peak altitude; otherwise we get into weird floating-point errors. May tweak this more later. Use CV3 to send a gate when the particle is at rest (can be used to auto-reset the particle!). CV4-5 are position/velocity. CV6 is still unused
    * Rename Marble Physics -> Particle Physics. Add the readme, add the new program to the me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
    [knobs.py]
2023-10-31 Add new named constants, reduce incidences of "magic numbers" (#308)
    * Remove magic numbers for the I/O pins, replace with named constants
    * Use the new PIN_* definitions in the calibration script
    * Replace some magic numbers in the quantizer with named constants
    * Add named constants for the consequencer modes instead of using literals 1/2/3 in comparisons
    [consequencer.py, europi.py, quantizer.py]
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2024-01-31 Access bootloader mode from the menu (#320)
    * add update_firmware to menu
    * create update_firmware
    * Update programming_instructions.md
    * add comments
    * Add missing comma
    * Fix wording and refer to Bootloader script
    * Rename to Bootloader
    * Change to be named Bootloader
    * Refer to Bootloader instead of UpdateFirmware
    * Rename to BootloaderMode
    * Update to refer to BootloaderMode
    * Refer to BootloaderMode
    * import machine to remove bootloader confusion
    the europi "bootloader" menu system uses the term bootloader, this script has been adjusted to use machine.bootloader so that the difference is more obvious
    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
    [bootloader_mode.py, europi.py, europi_script.py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]
2024-02-01 Add more settings to `europi_config` (#317)
    * Expand the readme to include a section on the global configuration file. Add support for setting screen orientation & Moog vs Buchla V/Oct configuration
    * Add write_cmd to the mocks for testing
    * Add the register definitions to ssd1306 for testing
    * Missing newline
    * Remove const(...); the testing environment doesn't appear to know about it
    * flip_display -> rotate_display in readme
    * Add max voltages, screen size, and EuroPi model to the configuration settings
    * Make the configuration points' formatting consistent, disable linter format checking, since it insists on making it irregular
    * Fix typo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
    [configuration.py, europi.py, europi_config.py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]
2024-02-01 avoid making display calls while building docs
    Since the doc generation system mocks out the ssd1306 library we can't make any calls to it while importing the europi lib
    [europi.py]
2024-02-04 Improved Gates & Triggers Script, Overhauled screensaver (#309)
    * Add the gates_and_triggers script
    * Expand the readme with ranges & voltages
    * Blank the screen
    * Fix a bug in the ain on-fall callback
    * Revert "Remove magic numbers for the I/O pins, replace with named constants"
    This reverts commit 327c3cc88db6cd2d32dcfb4b117a2fe183b7ca88.
    * Increase the maximum gate duration to 2s (from 1s)
    * Overhaul the script to use a single digital input, allow CV control over the gate output, add a toggle output, and two new end-of-fall outputs (for the dynamic gate & toggle outs)
    * Show the gate length (to the nearest ms) on the screen, add the screensaver to G&T. Move the scr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
    [bootloader.py, custom_font.py, screensaver.py]
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2024-02-06 Consequencer jan 24 (#324)
    * consequencer updates Jan-24 init
    * fixed minor screensaver related bug
    * doc updates based on feedback
    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
    [consequencer.py]
2024-02-08 Improvements to oled.centre_text() (#329)
    * edits to centre_text
    * Update europi.py
    * Update europi.py
    * Revert "black formatting"
    This reverts commit bc8a32107a8c4136b1b1fcc5d5dd20330b032838.
    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
    [europi.py]
2024-02-08 Use the new screensaver class in Pam's, Logic, and Euclid scripts (#312)
    * Show the gate length (to the nearest ms) on the screen, add the screensaver to G&T. Move the screensaver activation & blank timeouts into the Screensaver class itself instead of redefining them externally
    * Add a new wrapped Oled class that automatically checks for screensaver & screen-blanking. Use this wrapper instead of europi.oled in the 3 scripts that use the screensaver
    * Revert "Increase the sensi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
    [euclid.py]
2024-02-08 Add gate voltage to config (#331)
    * add gate_voltage to config
    * add changes to CONFIGURATION.md
    * fix indent
    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
    [europi.py, europi_config.py]
2024-02-08 Add Conway's Game of Life LFO (#313)
    * Initial commit of an LFO based on Conway's Game of Life. Runs way too slowly to reliably use an external clock
    * For debugging use CV6 as a gate that is high while we calculate the game process and low during drawing. This gives us a reasonable FPS monitor with low impact.
    * Simple optimization: only check regions that have changed instead of the whole field. This improves the FPS by a lot, but makes it less stable overall. Decent trade-off, I think.
    * Remove the vestiges of the external clock mode, update what the six CV channels do. Use the buttons as respawn or reset
    * Typo in a comment
    * Move the get_bit and set_but functions out of t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
    [bitarray.py, conway.py]
2024-02-09 Add Traffic script (#311)
    * Revert "Increase the sensitivity of the knobs for waking up the screensav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
    [a_to_d.py, screensaver.py]
2024-02-09 Add Clock Multiplier & Divider (#319)
    * Revert "Increase the sensitivity of the knobs for waking up the screensaver"
    This reverts commit 0f217050a4dc4edef001d8495cf4882572252616.
    * Change centre_text so it doesn't call .show() by default, add clear_first and auto_show arguments to centre_text, modify all extant calls to centre_text to use the correct auto_show behaviour
    * Go back to high-sensitivity for the knobs
    * Revert the change to make centre_text auto-show by defaul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
    [clock_mod.py]
2024-02-09 Replace instances where scripts define their own gate/trigger voltages to use .on() and .off(). Replace instances of .voltage(0) with .off() for clarity & consistency.
    [clock_mod.py, conway.py]
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2024-02-15 Add I²C Parameters to Config (#340)
    * add i2c parameters to europi_config
    * use i2c config parametersin europi.py
    * fix range to allow 0 or 1
    * add i2c parameters
    [europi.py, europi_config.py]
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2024-03-06 Remove trailing whitespace from all .py and .md files (#351)
    * Remove trailing whitespace from all .py and .md files
    * Add automatic trailing whitespace check to CI
    * Remove a hidden file that shouldn't be there
    * Revert "Add automatic trailing whitespace check to CI"
    This reverts commit d14a7b6681e22df34e2b359adf18519bcccc9769.
    * Use a fork of the whitespace-detector that supports filtering by file extension
    * Fix regex syntax (i hope)
    * Remove trailing whitespace from files outside the `software` directory
    * Remove the whitespace linting
    [bernoulli_gates.py, cvecorder.py, harmonic_lfos.py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]
2024-03-13 Remove a check that prevented the first item from being selected (#356)
    [ui.py]
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2024-03-16 Treat `europi_config` keys like named constants (#346)
    * Create a new ConfigSettings class that exposes the config dict's items as if they were named constants for improved code legibility
    * Make the new class _not_ a dict just to avoid any chance of subscripting. Fix some bugs
    * Use double-quotes to make the linter happier
    * Update scripts that use their own config_point instances
    * Make the config object a dict again; the tests were failing and I don't want to dig into rewriting those right now.
    * Hack the tests by providing an __eq__ method that supports comparing ConfigSettings instances to their equivalent source dict. Update the notes in europi_script to explain the con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
    [configuration.py, consequencer.py, diagnostic.py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]
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2024-05-23 Add Lutra script (#353)
    * Add Lutra script & docs
    * Use _thread to separate the GUI from the backend math. Change the LFO range to make the fastest speed slower, but the slowest speed _way_ slower.
    * Remove the ISRs; I forgot _thread could lock up if they're used
    * Fix a bug when loading the saved state
    * Add a note that the wave shape shows up on the display for 3s during selection
    * Code cleanup
    * Move the digital input helper into a new experimental module, add more detailed multi-threading docs with examples
    * Add the expert-users warning to the multithreading document
    * Make the maximum spread use nice intervals instead of just flat tick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
    [thread.py]
2024-06-02 Reduce latency in Clock Modifer script (#363)
    * Use microseconds for calculating the timing instead of milliseconds. Keep track of when the GUI needs re-rendering instead of always redrawing to reduce latency
    * Simplify state calculation
    * Minor linting
    * Increase the timeout for the incoming clock to 5s (from 1s). Re-implement the clock multiplication & division to force it to re-sync to the incoming gates. Division is now implemented as a simple gate-skipper. Multiplication phase times are based on the last incoming gate time instead of a free-running counter
    * Add an upper bound to the gate counter to prevent overflows/performance degredation with large integers
    * Add a scr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
    [clock_mod.py, screensaver.py]
2024-06-02 Bit Garden - Deterministic psudo random gate processor (#360)
    * Compile uf2 test merge (#3)
    * Create Release and publish uf2 asset upon version tag creation.
    * typos and syntax
    * testing on push
    * separate run commands
    * testing
    * clone to path
    * missed leading folder
    * provide working dir for final make
    * install missing build packages
    * do not use env vars
    * add asset type
    * replace release action
    * add automatic_release_tag
    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
    [bit_garden.py]
2024-06-02 Improve responsiveness of Gates & Triggers (#364)
    * Rewrite most of Gates & Triggers to reduce overhead in the ISRs, improve knob responsiveness
    * Don't invert ain; treat k2 as an attenuator, not an attenuverter. Add median filtering for additional debouncing
    * Minor cleanup
    * Add a section about fine-tuning short gates
    * Reduce samples when reading analogue inputs; the median filter de-noises enough that we can speed up sampling. Rename some variables for clarity
    * Add the formula used to calculate the gate duration
    * Move median(l) into a new experimental.math module, add mean(l) as well since they're both nice utility functions to have (even if mean() isn't used anywhere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
    [knobs.py, math.py]
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2024-07-20 Improve numerical `ConfigPoint` implementations (#370)
    * Refactor the IntegerConfigPoint so it doesn't save the whole range as a list. Add FloatConfigPoint so we can save floating point values without converting them to integers. Use the new FloatConfigPoint for the global voltage settings in europi_config.
    * Fix the tests, remove support for step values within IntegerConfigPoint ranges, as they are not used anywhere
    * Forgot to update the number of config points
    * Remove the "c" key
    * Replace the range argument for IntegerConfigPoints with explicit maximum & minimum values
    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
    [configuration.py, europi_config.py, turing_machine.py]
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

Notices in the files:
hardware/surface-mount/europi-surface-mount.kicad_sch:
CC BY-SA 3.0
